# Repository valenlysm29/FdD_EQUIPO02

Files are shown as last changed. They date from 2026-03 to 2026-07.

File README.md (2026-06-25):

# Equipo 02 - Fundamentos de Diseño
### Carrera de Ingeniería Ambiental / Informática / Industrial  
**Universidad Peruana Cayetano Heredia**

---

## 🌍 Descripción del Equipo  
<p align="justify">
Somos el <strong>Equipo 02</strong> del curso <strong>Fundamentos de Diseño 2026-1</strong>, conformado por estudiantes de la carrera de Ingeniería Ambiental / Informática / Industrial.  
Nuestro objetivo es aplicar la metodología de diseño para generar soluciones innovadoras con impacto social, tecnológico y ambiental.
</p>

---

## 🎯 Introducción
<p align="justify">
La ciudad de Lima, particularmente en distritos como Villa María del Triunfo, presenta una marcada desigualdad en el acceso a recursos básicos, siendo el agua potable uno de los más críticos. En las zonas altas y asentamientos humanos, el abastecimiento es irregular, costoso y, en muchos casos, dependiente de camiones cisterna, lo que limita el desarrollo y la calidad de vida de la población.
</p>

<p align="justify">
Paradójicamente, Lima posee una alta humedad ambiental, especialmente durante temporadas de garúa y neblina, recurso que no es aprovechado de manera eficiente. A ello se suma un segundo problema relevante: la contaminación del aire, producto del crecimiento urbano, el tránsito vehicular y la presencia de polvo en zonas no pavimentadas.
</p>

<p align="justify">
En este contexto, el presente proyecto propone el diseño de un sistema inteligente de captación de niebla con monitoreo de calidad del aire, que permita no solo generar una fuente alternativa de agua, sino también evaluar las condiciones ambientales del entorno. Esta propuesta integra principios de ingeniería, sostenibilidad y tecnología, orientándose a soluciones adaptadas a la realidad local.
</p>

---

## ⚠️ Problemática

<p align="justify">
En las zonas altas de Villa María del Triunfo y otros sectores periurbanos de Lima se identifican dos problemáticas principales:
</p>

### 1. Escasez de agua  
- Más de un millón de personas en Lima no cuentan con acceso adecuado al agua potable.  
- Existe dependencia de camiones cisterna, lo que implica **altos costos y baja continuidad del servicio**.  
- Se generan limitaciones en actividades básicas como higiene, riego y consumo.  

### 2. Contaminación del aire  
- Presencia de material particulado (PM2.5 y PM10), especialmente en zonas con alta exposición al polvo.  
- Emisión de gases contaminantes debido al tránsito vehicular y actividades urbanas.  
- Impacto directo en la salud, principalmente enfermedades respiratorias.  

### 🔍 Problema integrador  

<p align="justify">
A pesar de la abundante humedad ambiental presente en forma de neblina o garúa, no existen sistemas accesibles que permitan aprovechar este recurso como fuente alternativa de agua y, simultáneamente, evaluar la calidad del aire del que proviene.
</p>

<p align="justify">
Esto genera una doble brecha:
</p>

- Se desperdicia un recurso natural disponible (neblina).  
- No se cuenta con información clara sobre la calidad del aire en zonas vulnerables.  

---

## 💡 Presentación de la solución  

<p align="justify">
El presente proyecto propone el desarrollo de un <strong>sistema inteligente de captación de niebla con monitoreo de calidad del aire</strong>, diseñado para zonas vulnerables de Lima, como Villa María del Triunfo, donde existe limitada disponibilidad de agua potable y altos niveles de contaminación ambiental.
</p>

<p align="justify">
La solución se basa en el aprovechamiento de la humedad atmosférica en forma de neblina o garúa, la cual es transformada en agua mediante un sistema de captación física. A diferencia de los sistemas tradicionales de atrapanieblas, esta propuesta incorpora un componente tecnológico que permite evaluar la calidad del aire y la calidad del agua, generando información ambiental relevante.
</p>

<p align="justify">
El sistema está compuesto por tres módulos principales:
</p>

### 🔹 Módulo 1: Captación de niebla  
- Uso de una malla especializada donde las microgotas se adhieren.  
- Coalescencia de gotas hasta alcanzar un tamaño suficiente.  
- Descenso por gravedad hacia una canaleta.  
- Almacenamiento en un depósito.  

### 🔹 Módulo 2: Monitoreo ambiental  
- Integración de sensores (ej. MQ-135 o PM2.5).  
- Detección de gases y partículas contaminantes.  
- Visualización del nivel de calidad del aire mediante LED o pantalla.  

### 🔹 Módulo 3: Registro y análisis  
- Medición del volumen de agua recolectada.  
- Registro del tiempo de captación.  
- Relación entre condiciones ambientales y rendimiento del sistema.  

<p align="justify">
Desde el enfoque de ingeniería, la solución integra principios de <strong>transferencia de masa (condensación)</strong>, diseño estructural optimizado (ángulo e inclinación de la malla) y sistemas electrónicos basados en sensores y microcontroladores. Esto permite no solo la captación eficiente del recurso hídrico, sino también la generación de datos para análisis y toma de decisiones.
</p>

<p align="justify">
El valor diferencial del proyecto radica en su enfoque integral: no solo busca generar una fuente alternativa de agua, sino también garantizar que dicha agua provenga de un entorno ambiental evaluado, incorporando un criterio de calidad que no está presente en sistemas convencionales.
</p>

<p align="justify">
En términos de impacto, esta solución representa una alternativa sostenible, de bajo costo y replicable, que puede ser implementada en comunidades con condiciones similares, contribuyendo simultáneamente a la <strong>seguridad hídrica</strong> y al <strong>monitoreo ambiental urbano</strong>.
</p>

---

## 🎯 Objetivos de Desarrollo Sostenible (ODS)

- 🚰 **ODS 6: Agua limpia y saneamiento**  
  Busca garantizar la disponibilidad y gestión sostenible del agua, promoviendo no solo el acceso al agua potable, sino también su uso eficiente en actividades productivas como la agricultura. Este objetivo es fundamental, ya que el sector agrícola consume aproximadamente el 70% del agua dulce a nivel mundial, lo que hace necesario implementar sistemas de riego más eficientes y sostenibles . En el Perú, aún existen importantes brechas en el acceso y gestión del agua: solo el 49,4% de la población cuenta con agua potable gestionada de forma segura , lo que evidencia la urgencia de optimizar el uso del recurso hídrico, especialmente en contextos de escasez.
  
  En distritos como Villa María del Triunfo, donde muchas familias dependen de camiones cisterna y enfrentan altos costos por el agua, resulta poco sostenible utilizar agua potable para el riego agrícola. En este contexto, nuestro proyecto se alinea directamente con el ODS 6 al proponer un sistema de riego agrícola basado en una fuente alternativa de agua, lo que permite reducir la presión sobre el agua potable, mejorar la eficiencia en su uso y promover prácticas sostenibles. De esta manera, se contribuye no solo a la conservación del recurso hídrico, sino también al desarrollo de la agricultura urbana y a la mejora de la calidad de vida en comunidades vulnerables.

---

- ❤️ **ODS 3: Salud y bienestar** 

  Monitoreo de la calidad del aire (Meta 3.9). El proyecto no solo proporciona agua, sino que también mide el entorno. Al integrar sensores de calidad del aire, se obtendrán datos críticos para prevenir enfermedades respiratorias. El ODS 3 busca reducir sustancialmente el número de muertes y enfermedades producidas por aire contaminado. El sistema actúa como una estación de alerta temprana para la salud comunitaria. Villa María del Triunfo es uno de los distritos con mayor humedad y, a menudo, con altos índices de contaminación por su cercanía a zonas industriales y tráfico. La niebla puede concentrar contaminantes; por ello, medir el aire mientras se captura el agua es vital.  

  Reducción de la carga de estrés y salud mental.En pleno 2026, la escasez hídrica en el Cono Sur de Lima obliga a más de 3,000 familias en VMT a depender de camiones cisterna con costos excesivos y frecuencias mínimas. La salud, entendida como un estado de bienestar integral, se ve afectada por la carga física y mental de gestionar el agua. Al automatizar la recolección para áreas verdes y huertos, se reduce el agotamiento físico (especialmente en mujeres y niños) y el estrés económico. La autonomía sobre el recurso hídrico y la creación de espacios verdes saludables transforman el entorno social, promoviendo una mejor salud mental y cohesión comunitaria.
---

- 🏗️ **ODS 9: Industria, innovación e infraestructura**  
  Este objetivo promueve el desarrollo de infraestructura resiliente, la industrialización sostenible y el fomento de la innovación. En muchas zonas vulnerables de Lima, la infraestructura para el acceso al agua es limitada o inexistente, lo que genera dependencia de sistemas informales como los camiones cisterna.  

  Frente a esta situación, el proyecto propone una solución innovadora que integra diseño estructural, sensores y análisis de datos. El sistema combina un mecanismo físico de captación de niebla con tecnologías como microcontroladores y monitoreo en tiempo real, permitiendo no solo recolectar agua, sino también optimizar su funcionamiento mediante el análisis de variables ambientales.  

  De esta manera, se desarrolla una propuesta tecnológica orientada a la innovación y al desarrollo de soluciones funcionales para problemáticas reales, promoviendo infraestructura alternativa sostenible, accesible y replicable en otras zonas con condiciones similares.

---

- 🏙️ **ODS 11: Ciudades y comunidades sostenibles**  
  Busca mejorar las ciudades frente al rápido crecimiento urbano. Actualmente, más de la mitad de la población vive en zonas urbanas y se proyecta que esta cifra alcanzará el 70 % para el año 2050, lo que generará problemáticas como la contaminación del aire, la expansión desordenada y el acceso limitado a servicios básicos. Además, cerca de 1100 millones de personas viven en condiciones precarias, y muchas ciudades continúan creciendo más rápido en territorio que en población, provocando un uso ineficiente del suelo. Ante este panorama, el ODS 11 propone construir ciudades más sostenibles, resilientes, seguras e inclusivas.  

  En este contexto, como equipo se desarrollará el proyecto “Sistema inteligente de captación de niebla con monitoreo de calidad del aire para Lima”, el cual buscará responder a problemáticas reales de la ciudad. Por un lado, se propondrá captar agua a partir de la humedad ambiental, con el objetivo de contribuir al acceso a un recurso básico en zonas vulnerables. Por otro lado, se incorporarán sensores que permitirán monitorear la calidad del aire, facilitando la identificación de niveles de contaminación. De esta manera, el proyecto integrará sostenibilidad, uso eficiente de recursos e innovación tecnológica, con la finalidad de aportar a la mejora de la calidad de vida en entornos urbanos y fortalecer el desarrollo de ciudades más sostenibles.

---

- 🌱 **ODS 13: Acción por el clima**  
  Hemos escogido este ODS porque nuestro proyecto busca responder a problemas relacionados con el cambio climático en Lima, especialmente en zonas como Villa María del Triunfo, donde hay presencia de neblina, alta humedad y contaminación del aire.  

  En las zonas de lomas de Villa María del Triunfo existe alta humedad debido a la neblina, pero este recurso no es aprovechado, a pesar de la escasez de agua en sectores cercanos. Además, la contaminación del aire en Lima afecta el ambiente y la salud, siendo un problema relacionado con el cambio climático. Según datos estadísticos de SENAMHI, en Lima se registran contaminantes como PM2.5 y PM10 en niveles que pueden ser perjudiciales para la salud. Asimismo, la humedad relativa puede alcanzar entre 70% y 90%, lo que evidencia el potencial de captar agua de la niebla.

---

## 📸 Fotografía del prototipo
<p align="center">
  
  <br>
  <em>Figura 1. Representación del prototipo propuesto</em>
</p>

---

## 📚 Referencias

- Organización Mundial de la Salud (OMS). (2021). *Air Quality Guidelines*.  
  https://www.who.int/publications/i/item/9789240034228  

- Organización Mundial de la Salud (OMS). (2021). *What are the WHO Air Quality Guidelines*.  
  https://www.who.int/news-room/feature-stories/detail/what-are-the-who-air-quality-guidelines  

- United Nations. (2023). *The Sustainable Development Goals Report 2023*.  
  https://unstats.un.org/sdgs/report/2023/  

- United Nations. (2023). *Informe de los Objetivos de Desarrollo Sostenible*.  
  https://unstats-un-org.translate.goog/sdgs/report/2023/_x_tr_sl=en&_x_tr_tl=es&_x_tr_hl=es&_x_tr_pto=tc  

- Naciones Unidas Perú. (s.f.). *Objetivo de Desarrollo Sostenible 6: Agua limpia y saneamiento*.  
  https://peru.un.org/es/sdgs/6  

- United Nations Environment Programme (UNEP). (2019). *Air Pollution Report*.  
  https://unhabitat.org/world-cities-report-2020-the-value-of-sustainable-urbanization  

- World Bank. (2020). *Sustainable Cities Report*.  
  https://www.unep.org/resources/assessment/air-pollution-asia-and-pacific-science-based-solutions  

- UNICEF. (s.f.). *Día Mundial del Agua: 1.000 niños mueren cada día por falta de agua potable*.  
  https://www.unicef.es/noticia/dia-mundial-del-agua-1000-ninos-mueren-cada-dia-por-falta-de-agua-potable  

- Servicio Nacional de Meteorología e Hidrología del Perú (SENAMHI). (2022). *Calidad del aire en Lima Metropolitana*.  
  https://www.senamhi.gob.pe  

- Servicio Nacional de Meteorología e Hidrología del Perú (SENAMHI). (2025). *Reporte de condiciones climáticas y calidad del aire en Lima*.  
  https://www.senamhi.gob.pe  

- Superintendencia Nacional de Servicios de Saneamiento (SUNASS). (2023). *Familias sin acceso al agua potable gastan más que hogares conectados*.  
  https://www.gob.pe/institucion/sunass/noticias/848884  

- Ministerio de Vivienda, Construcción y Saneamiento. (2024). *Proyectos de agua y saneamiento en Villa María del Triunfo*.  
  https://www.gob.pe/vivienda  

- FogQuest. (2020). *Fog Collection Projects*.  
  https://www.fogquest.org  

- MIT News. (2013). *Fog harvesting system inspired by nature*.  
  https://news.mit.edu/2013/efficient-fog-harvesting-0423  

- UCSS. (s.f.). *Contaminación del aire en Villa María del Triunfo*.  
  https://es.scribd.com/document/495390114/informe-villa-maria-docx  

- Congreso de la República del Perú. (2012). *Informe técnico: Captación de agua de las nieblas: Una alternativa para el desarrollo de las zonas áridas*. Centros de Documentación y Biblioteca.  
  https://www2.congreso.gob.pe/sicr/cendocbib/con4_uibd.nsf/B0F868A4B8BAE93705257CBC004FA71A/$FILE/1_INFORME_TECNICO_FINAL.pdf
 
  ---

## 📸 Fotografía del Equipo  
<p align="center">
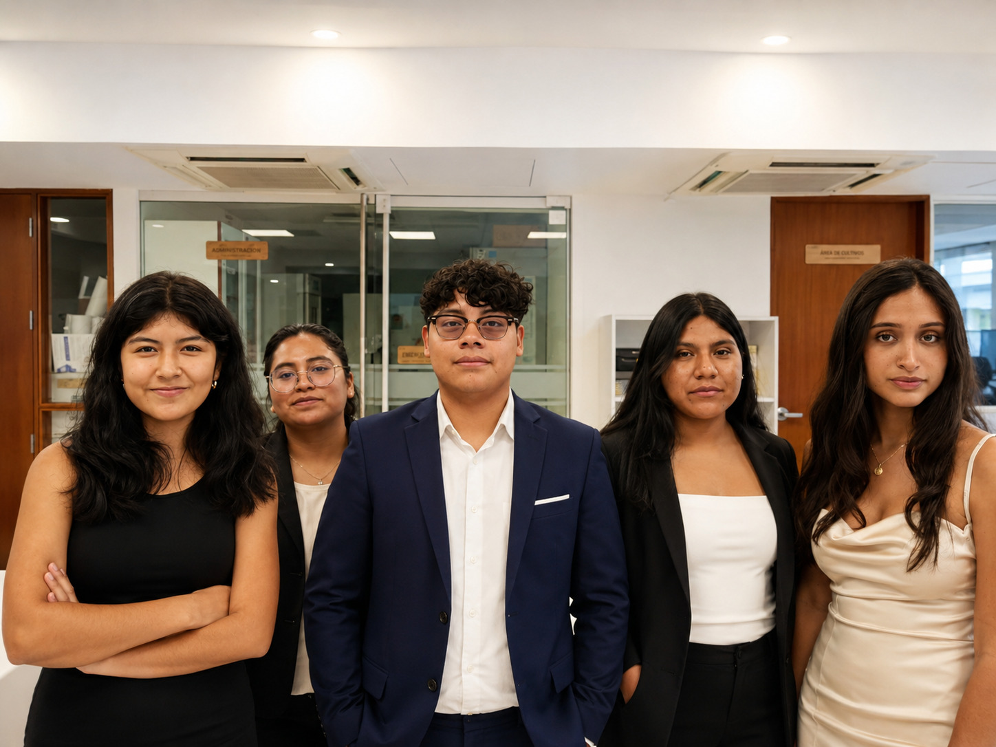
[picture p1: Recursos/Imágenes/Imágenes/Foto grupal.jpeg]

<br>
<em>Figura 2. Fotografía del equipo 02</em>
</p>

---

## 👥 Integrantes del Equipo  

| 📸 Foto | 👤 Nombre | 🎓 Rol | 💡 Intereses | 📧 Correo |
|:---:|:---|:---:|:---|:---|
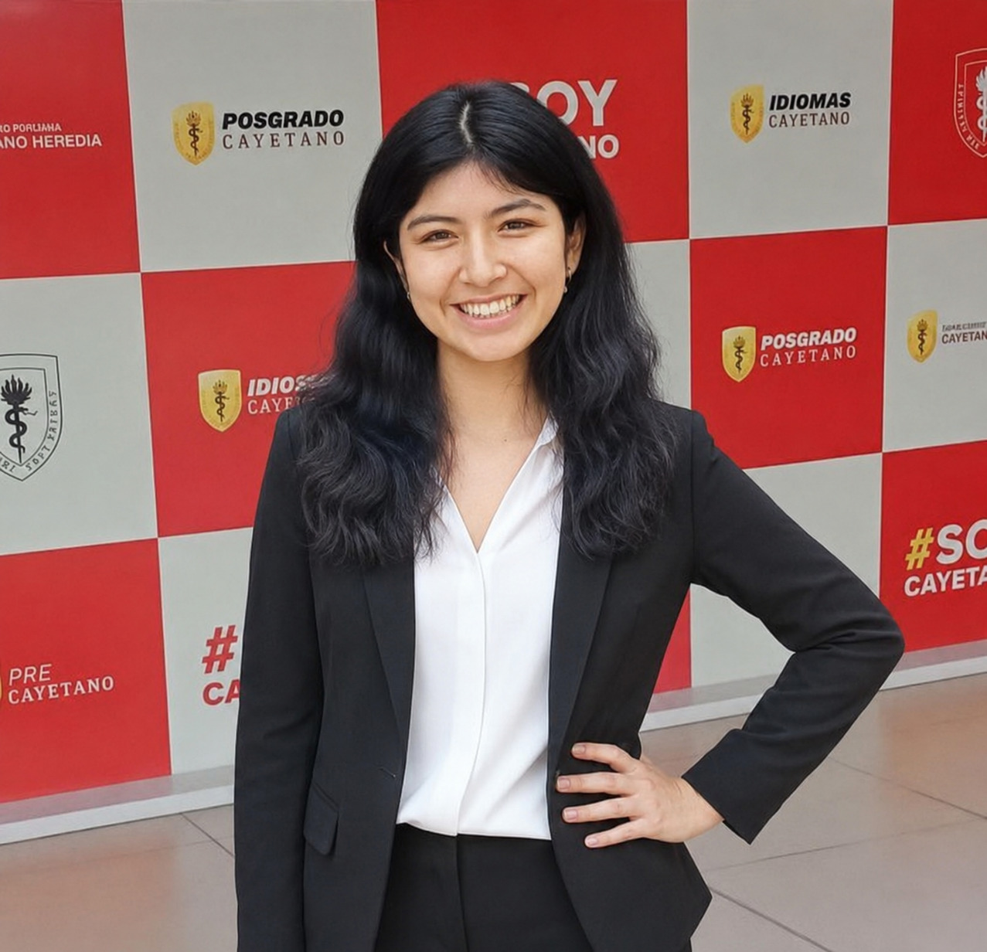
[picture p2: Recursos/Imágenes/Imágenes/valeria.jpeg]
|  | **Rodriguez Zavaleta, Valeria Nicole** | 👑 Líder del equipo | 🌱 Innovación social, 💡 liderazgo, ♻️ sostenibilidad | 📩 [valeria.rodriguez@upch.pe](mailto:valeria.rodriguez@upch.pe) |
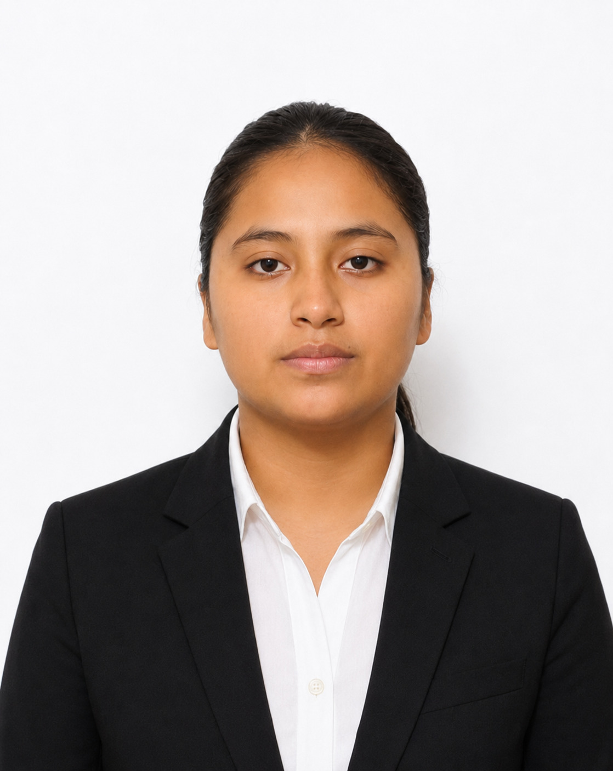
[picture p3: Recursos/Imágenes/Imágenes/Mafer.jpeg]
|  | **Perez Salvatierra, María Fernanda** | 🔬 Investigación | 🌍 Gestión ambiental, 🌱 desarrollo sostenible, 📊 impacto ambiental | 📩 [maria.perez.salvatierra@upch.pe](mailto:maria.perez.salvatierra@upch.pe) |
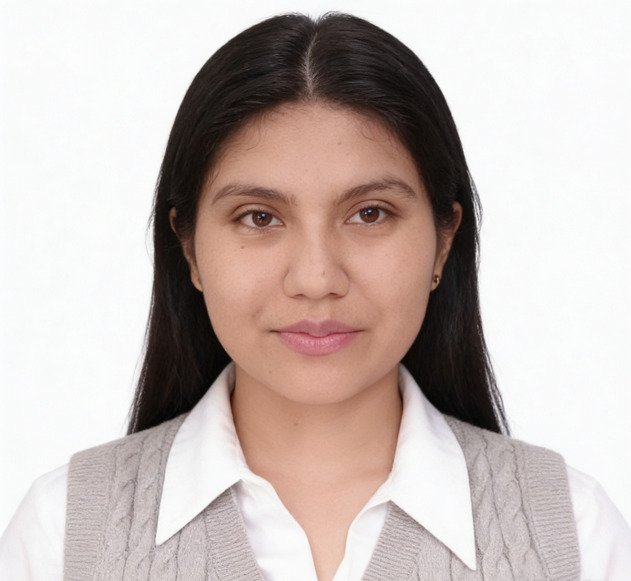
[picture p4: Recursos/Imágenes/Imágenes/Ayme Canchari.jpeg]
|  | **Canchari de la Cruz, Ayme** | 🎨 Diseño | 🧩 prototipos, ✨ innovación, 🎯 creatividad aplicada | 📩 [ayme.canchari@upch.pe](mailto:ayme.canchari@upch.pe) |
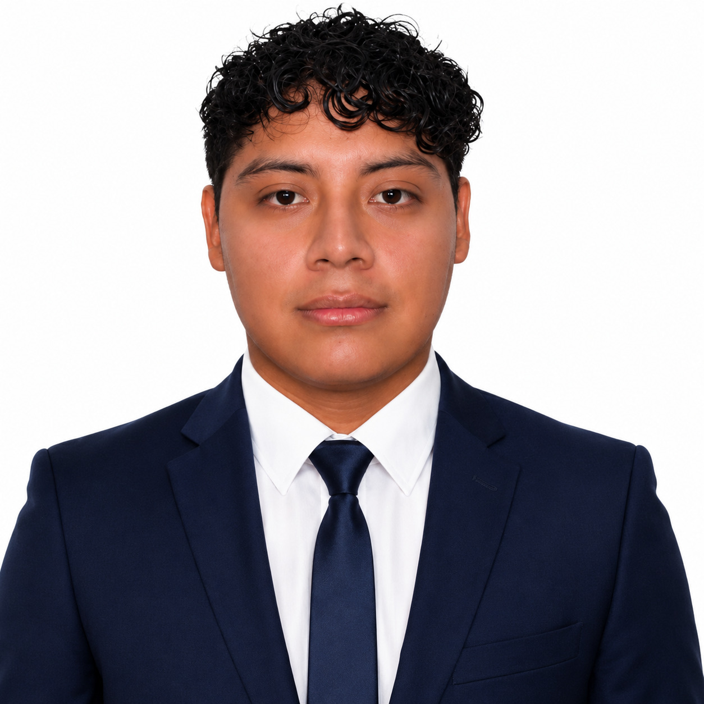
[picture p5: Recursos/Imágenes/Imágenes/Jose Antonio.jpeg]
|  | **Mamani Tello, Jose Antonio** | 📝 Documentación | 📄 procesos, 📈 mejora continua, ✍️ redacción técnica | 📩 [jose.mamani.t@upch.pe](mailto:jose.mamani.t@upch.pe) |
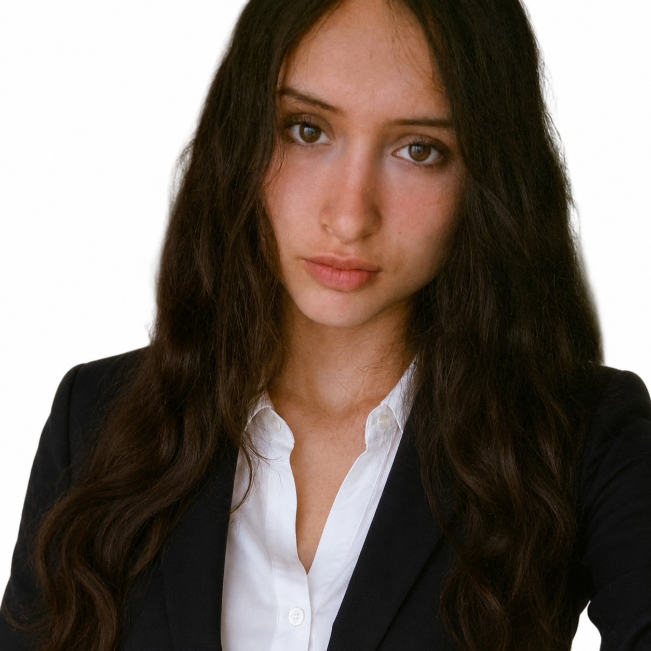
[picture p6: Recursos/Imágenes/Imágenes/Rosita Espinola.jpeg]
|  | **Espinola Abanto, Rosita Dayana** | 💻 Programación | 👩‍💻 programación, 📊 datos, 🧠 simulación y sistemas robóticos | 📩 [rosita.espinola@upch.pe](mailto:rosita.espinola@upch.pe) |

---

## 📌 Resumen Final  
<p align="justify">
El presente README describe la conformación del equipo, la problemática abordada y la propuesta de solución desarrollada en el marco del curso Fundamentos de Diseño. El proyecto propone un sistema inteligente que capta agua de la neblina mediante una malla atrapanieblas y, simultáneamente, monitorea la calidad del aire mediante sensores ambientales. Esta solución, aplicada en zonas como Villa María del Triunfo, permite aprovechar la humedad del ambiente como fuente alternativa de agua y evaluar las condiciones del aire del que proviene, integrando sostenibilidad, tecnología e innovación en un solo sistema.
</p>

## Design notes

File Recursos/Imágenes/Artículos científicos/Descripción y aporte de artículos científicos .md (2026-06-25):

 # Artículo Científico de Apoyo 1

## Nombre del Artículo

Water Harvesting Through Fog Collectors: A Review of Conceptual, Experimental and Operational Aspects

## Descripción

Este artículo presenta una revisión del estado del arte sobre los sistemas de captación de agua mediante atrapanieblas, enfocándose en su uso como alternativa frente a la escasez hídrica en zonas áridas y comunidades aisladas. Analiza la clasificación de los sistemas en conceptuales, experimentales y operacionales, así como su evolución, funcionamiento y aplicaciones en distintos contextos.

Además, estudia los principales factores que influyen en la eficiencia de captación, como el clima, los materiales utilizados y el diseño estructural, junto con desafíos asociados al mantenimiento y la implementación social de estas tecnologías.

## Aporte al Proyecto

Este artículo aporta una base teórica sólida sobre el funcionamiento de los atrapanieblas y los factores que afectan su eficiencia. Asimismo, permite identificar oportunidades de mejora mediante la incorporación de tecnologías IoT para el monitoreo en tiempo real de variables ambientales y de la calidad del agua, fortaleciendo la propuesta del proyecto.

---

# Artículo Científico de Apoyo 2

## Nombre del Artículo

Eficiencia de captación de agua con tres tipos de malla atrapanieblas en zonas rurales altoandinas de la sierra norte del Perú

## Descripción

Este artículo presenta un estudio experimental que evalúa la eficiencia de captación de agua mediante tres tipos de mallas atrapanieblas en zonas rurales altoandinas del norte del Perú. La investigación compara el desempeño de cada material bajo condiciones ambientales similares, considerando variables como humedad relativa, velocidad del viento y densidad de la niebla.

Los resultados evidencian diferencias significativas en la cantidad de agua recolectada, lo que permite determinar los materiales más eficientes para la captación en este tipo de entornos.

## Aporte al Proyecto

Este estudio proporciona evidencia experimental sobre la influencia del tipo de malla en el rendimiento de los sistemas atrapanieblas. Además, contribuye a la selección de materiales más eficientes y respalda la propuesta de integrar sensores para analizar en tiempo real la relación entre las condiciones ambientales y la eficiencia del sistema.

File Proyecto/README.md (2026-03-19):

# Proyecto

En esta carpeta deben estar todos los archivos necesarios para poder replicar el proyecto:

- Código fuente del sistema (Módulo Software)
- Archivos de diseño 3D para la fabricación de piezas (Módulo Mecánico)
- Esquemas electrónicos (Módulo Electrónico)

Cada módulo contiene su propia documentación y recursos específicos para facilitar la implementación y el montaje del proyecto.

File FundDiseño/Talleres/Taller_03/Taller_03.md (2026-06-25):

# 1. INTRODUCCIÓN

El acceso al agua constituye uno de los principales desafíos a nivel global, especialmente en un contexto marcado por el cambio climático y el crecimiento urbano acelerado, factores que comprometen la disponibilidad y la gestión sostenible de los recursos hídricos (1). En el Perú, esta problemática es particularmente crítica, ya que solo el 49,4% de la población cuenta con acceso a agua potable gestionada de forma segura, lo que evidencia importantes brechas estructurales en la cobertura y calidad del servicio (2).

En Lima Metropolitana, y de manera más acentuada en distritos como Villa María del Triunfo, la situación se agrava debido a la expansión urbana desordenada y a la limitada infraestructura de saneamiento. En estas zonas, una parte significativa de la población depende del abastecimiento mediante camiones cisterna, lo cual incrementa el costo del recurso y restringe su disponibilidad para actividades domésticas y productivas. Paradójicamente, estas áreas presentan altos niveles de humedad relativa (entre 70% y 90%), acompañados de fenómenos persistentes de neblina o garúa característicos de las lomas costeras (2).

A pesar de este potencial hídrico atmosférico, la niebla no es aprovechada de manera sistemática como fuente alternativa de agua. Esta situación se ve agravada por la contaminación del aire, caracterizada por la presencia de material particulado fino (PM2.5 y PM10), emisiones vehiculares y polvo en suspensión, lo que no solo afecta la salud de la población, sino también la calidad del agua captada de la atmósfera (3).

En este contexto, diversas investigaciones han demostrado que la captación de agua de niebla mediante sistemas atrapanieblas constituye una alternativa viable en zonas áridas y semiáridas, permitiendo recolectar microgotas suspendidas en la atmósfera para su uso en actividades como el riego agrícola (4–7). Asimismo, el desarrollo tecnológico en este campo ha sido impulsado por estudios y patentes que optimizan la eficiencia de captación mediante el uso de materiales especializados (8). Sin embargo, en el contexto local, estas soluciones suelen carecer de sistemas de monitoreo ambiental y de adaptaciones específicas frente a condiciones de contaminación urbana.

En ese sentido, se identifica una brecha tecnológica en la integración de sistemas de captación de agua de niebla con herramientas inteligentes de monitoreo ambiental que permitan garantizar un uso eficiente, seguro y sostenible del recurso. Estudios realizados en las lomas de Villa María del Triunfo evidencian que el agua captada no es apta para consumo humano directo, pero sí resulta adecuada para riego y mantenimiento de áreas verdes, lo que orienta su aprovechamiento hacia usos no potables (7).

Frente a esta problemática, el presente proyecto propone el diseño de un sistema inteligente de captación de agua de niebla, complementado con sensores para el monitoreo de la calidad del aire y variables ambientales como temperatura y humedad relativa. Para ello, se plantea el uso del sensor BME280, el cual permite medir con alta precisión la temperatura, humedad relativa y presión atmosférica, variables clave para identificar condiciones óptimas de formación de niebla. En cuanto al monitoreo de la calidad del aire, se empleará el sensor MQ-135, seleccionado como una alternativa representativa y de bajo costo frente a sensores más avanzados como el PMS5003, permitiendo detectar gases contaminantes relevantes en entornos urbanos. Asimismo, el sistema incorporará un sensor de pH para evaluar la calidad del agua captada y determinar su idoneidad para riego, así como un sensor de nivel de agua (tipo flotador o ultrasónico) para gestionar el almacenamiento del recurso recolectado. Para la automatización del riego, se utilizará un sensor de humedad de suelo, el cual permitirá optimizar el uso del agua en función de las necesidades reales del terreno. Todos estos dispositivos estarán integrados mediante un microcontrolador ESP32, el cual posibilita la interconexión de sensores y la transmisión de datos en tiempo real, facilitando la implementación de un sistema basado en Internet de las Cosas (IoT) orientado a la gestión eficiente del recurso hídrico.

Finalmente, la propuesta se alinea con los Objetivos de Desarrollo Sostenible (ODS), particularmente con el ODS 6 (agua limpia y saneamiento), al promover el uso de fuentes hídricas alternativas; el ODS 9 (industria, innovación e infraestructura), mediante la aplicación tecnológica; el ODS 11 (ciudades y comunidades sostenibles), al mejorar las condiciones ambientales urbanas (9); y el ODS 13 (acción por el clima), al plantear estrategias de adaptación basadas en el aprovechamiento de recursos atmosféricos. De este modo, el proyecto se configura como una solución sostenible, accesible y replicable frente a problemáticas ambientales críticas (10).

---

# BIBLIOGRAFÍA

1. Ministerio del Ambiente del Perú. Evaluación de necesidades tecnológicas para el cambio climático en el Perú [Informe técnico]. Lima: Ministerio del Ambiente; 2014.

2. Instituto Nacional de Estadística e Informática. Perú: Formas de acceso al agua y saneamiento básico - Nro 10 [Internet]. [citado el 8 de abril de 2026]. Disponible en: https://www.gob.pe/institucion/inei/informes-publicaciones/4985657-peru-formas-de-acceso-al-agua-y-saneamiento-basico-nro-10

3. Organización Mundial de la Salud. Publicaciones sobre calidad del aire [Internet]. [citado el 8 de abril de 2026]. Disponible en: https://www.who.int/publications

4. Miñan Peña MM. Estudio para la obtención y aprovechamiento de agua para uso agrícola por medio de captadores de neblina en la comunidad campesina de Samanga, Ayabaca – Piura [Tesis de pregrado]. Universidad Alas Peruanas; 2017.

5. Toledo Huayaney EI. Gestión de nieblas como recurso hídrico para proteger el ecosistema de lomas en zonas áridas del distrito de Villa María del Triunfo en el año 2015 [Tesis de maestría] [Internet]. Universidad Nacional Hermilio Valdizán; 2017. Disponible en: https://repositorio.unheval.edu.pe/backend/api/core/bitstreams/a02e9b67-677e-4612-81b4-57812e1e571f/content

6. Albornoz Figueroa F, Torres Rojas G. Determinación del potencial de captación de agua de atrapanieblas como fuente alternativa de recursos hídricos para desarrollo agrícola en un ecosistema con características árido-desérticas en la región de Arica y Parinacota [Tesis de pregrado]. Universidad de Tarapacá; 2020.

7. García Huazo FN. Estudio de la variación temporal y espacial de la calidad del agua de niebla en Las Lomas de Villa María [Internet]. 2017 [citado el 8 de abril de 2026]. Disponible en: https://hdl.handle.net/20.500.12996/3198

8. CN116988543. Agricultural irrigation fog water collector [Internet]. [citado el 2 de abril de 2026]. Disponible en: https://patentscope.wipo.int/search/en/detail.jsf?docId=CN414524443

9. Gómez Cano CA, Pérez Gamboa AJ, Sánchez Castillo V. Análisis de la producción científica en torno al ODS 11: Ciudades y Comunidades Sostenibles. Mundo Fesc. 2024;14(28):117–135. doi:10.61799/2216-0388.1585

10. Organización de las Naciones Unidas. 17 Objetivos de Desarrollo Sostenible [Internet]. [citado el 8 de abril de 2026]. Disponible en: https://www.ods.cr/es/17-objetivos-de-desarrollo-sostenible/

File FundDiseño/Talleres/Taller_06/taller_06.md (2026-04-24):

## MATRIZ DE DESK RESEARCH

**Proyecto:** YAKUYURA - Sistema de captación de niebla para riego con monitoreo de calidad de agua  
**Ubicación:** Villa María del Triunfo, Lima – Perú  

**Problematica:**  
¿Cómo diseñar un sistema de captación de niebla eficiente, de bajo costo y adaptable a las condiciones climáticas de Villa María del Triunfo, que permita obtener agua con calidad adecuada para riego, mediante el monitoreo de parámetros físico-químicos (pH, conductividad y turbidez), considerando la influencia de las condiciones ambientales?

**Acceso a la matriz en Google Sheets:**  
🔗 [Consultar matriz de Desk Research](https://docs.google.com/spreadsheets/d/1Mp-pc_4aNizmCjHv-cpVC83qQYfwDnMo/edit)

---

| N° | Fuente | Autor/Institución | Año | Referencia | Estado de tecnología encontrada | Exigencia o requisito identificado | Restricción o limitación | Función principal | Aplicación al proyecto |
|----|---|---|-----|---|---|---|---|---|---|
| 1 | DS N°004-2017-MINAM | Ministerio del Ambiente (MINAM) | 2017 | https://www.minam.gob.pe/wp-content/uploads/2017/06/DS-004-2017-MINAM.pdf | Normativa nacional que establece límites de calidad para agua de riego (Categoría 3, D1) | pH: 6.5–8.5; Conductividad: 2500–5000 µS/cm; control de calidad física (relacionada a turbidez) | No incluye turbidez como parámetro directo; algunos parámetros requieren interpretación | Establecer límites de calidad para uso seguro del agua en riego | Define rangos operativos para sensores de pH y conductividad; orienta la evaluación del agua captada |
| 2 | ISO 7027-1, ISO 10523, ISO 7888 | International Organization for Standardization (ISO) | 2008–2016 | ISO 7027-1: https://www.iso.org/obp/ui/#iso:std:iso:7027:-1:ed-1:v1:en <br> ISO 10523: https://www.iso.org/obp/ui/#iso:std:iso:10523:ed-2:v1:en <br> ISO 7888: https://www.iso.org/obp/ui/#iso:std:iso:7888:ed-1:v1:en | Métodos estandarizados para medición de turbidez, pH y conductividad | Uso de sensores calibrados y medición bajo condiciones controladas | No establecen valores límite de calidad | Estandarizar la medición de parámetros físico-químicos | Permite validar y calibrar sensores implementados en el sistema atrapanieblas |
| 3 | Calidad del aire y salud | Organización Mundial de la Salud (OMS) | 2023 | https://www.who.int/es/news-room/fact-sheets/detail/ambient-(outdoor)-air-quality-and-health | Información sobre contaminantes atmosféricos (PM, gases) que afectan el entorno | Identificación de contaminantes que pueden influir indirectamente en la calidad del agua | No aborda directamente calidad de agua ni riego | Analizar el impacto del aire en el ambiente | Justifica que la calidad del aire influye en pH, conductividad y turbidez del agua de niebla |
| 4 | Water Quality for Agriculture | FAO (Ayers & Westcot) | 1985 | https://www.fao.org/4/t0234e/t0234e00.htm | Referencia internacional para evaluación de agua en agricultura | Clasificación de salinidad mediante conductividad; control de sólidos en suspensión | No es normativa obligatoria; valores referenciales | Evaluar la aptitud del agua para riego agrícola | Complementa la normativa ECA e interpreta conductividad y turbidez del agua captada |

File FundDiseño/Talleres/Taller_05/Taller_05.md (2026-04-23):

## 🚀 Presentación del Proyecto

<p align="center">
  <a href="https://docs.google.com/document/d/1KE3PtH3lDLxYr63FYQYzETe2vs5omj35mvZSyd1JYwM/edit" target="_blank">
    
  </a>
  <a href="https://canva.link/n60l2mmut4ebm6i" target="_blank">
    
  </a>
</p>

<p align="center">
  Accede al documento técnico y a la presentación del proyecto YAKUYURA.
</p>

# 🚰 YAKUYURA: del aire a la vida

## 1. Historia

¿Sabías que en Lima, una ciudad con hasta 90% de humedad, más de un millón de personas tienen acceso limitado al agua?

Yo crecí viendo cómo, en distritos como Villa María del Triunfo, muchas familias dependen de camiones cisterna, pagando precios elevados por un recurso básico. Esta situación no solo afecta el consumo diario, sino también limita el desarrollo de actividades productivas como el riego y los huertos urbanos.

Como equipo de ingeniería, nos hicimos una pregunta clave:  
**¿Cómo es posible que falte agua, si vivimos rodeados de neblina todos los días?**

Fue ahí donde entendimos que el problema no es la falta de recursos, sino que no los estamos aprovechando.

---

## 2. Problema

A pesar de contar con condiciones ambientales favorables, el acceso al agua en el asentamiento humano Bellavista del Paraíso (Villa María del Triunfo) es limitado, incluso con la presencia de niebla costera (garúa).

- Consumo promedio en Lima: **134 L/persona/día** (≈ 536 L por familia)
- En la zona de estudio: **20 a 70 L/persona/día** (≈ 80 a 280 L por familia)
- Reducción de hasta **85%** (1,2)

Esto limita el uso del agua solo a:
- Cocina  
- Higiene  
- Limpieza  

Dejando de lado:
- Riego  
- Áreas verdes  

Además:
- No existen sistemas accesibles para aprovechar la niebla  
- El acceso es irregular y costoso  
- La calidad del aire genera dudas sobre el agua obtenida (3)

👉 **Problema central:**  
Existe un recurso disponible, pero no hay soluciones accesibles para captarlo ni herramientas que aseguren su calidad.

---

## 3. Solución

Proponemos **YAKUYURA**, un sistema que:

- Captura agua de la niebla mediante mallas
- Conduce el agua hacia un sistema de recolección
- La almacena para uso en riego

Además, incorpora sensores que miden:
- Humedad  
- Calidad del aire  
- Parámetros del agua  

Esto permite entender:
- En qué condiciones se obtiene el recurso  
- Para qué uso es adecuado  

---

## 4. Propuesta de valor

YAKUYURA no es un atrapanieblas tradicional, sino una solución integral que combina:

- Captación de agua  
- Monitoreo ambiental  
- Gestión del recurso  

Beneficios:
- Decisiones informadas sobre el uso del agua  
- Optimización del sistema  
- Reducción de riesgos por calidad ambiental  

✔ Enfoque realista:  
El agua está orientada a **riego y áreas verdes**, no consumo humano directo.

---

## 5. Modelo de negocio

YAKUYURA se plantea como una solución de implementación:

- Comunitaria  
- Institucional  

Dirigida a:
- Municipalidades  
- ONGs  
- Proyectos urbanos  

Basado en modelos reales:
- Peruanos Sin Agua  
- FogQuest  
- Aqualonis (4–6)

💡 Propuesta:
Servicio integral que incluye:
- Instalación  
- Mantenimiento  
- Monitoreo ambiental  

---

## 6. Estrategia

1. Piloto en Bellavista del Paraíso (VMT)
2. Evaluación del sistema en riego
3. Simulación en la universidad
4. Validación del impacto
5. Generación de alianzas

Objetivo:
- Escalar a otros asentamientos de Lima Sur

---

## 7. Tracción

Actualmente en fase de:

- Análisis del contexto  
- Definición del problema  
- Diseño conceptual  

✔ Próximo paso:
- Desarrollo y validación del prototipo en campo  

---

## 8. Equipo

Equipo multidisciplinario de estudiantes de:

- Ingeniería Ambiental  
- Ingeniería Informática  
- Ingeniería Industrial  

Capacidad:
- Enfoque técnico  
- Desarrollo de soluciones reales  
- Adaptación al contexto  

---

## 9. Pedido

Buscamos apoyo para:

- Desarrollo del prototipo  
- Validación en campo  
- Asesoría técnica  
- Espacios de prueba  
- Alianzas estratégicas  

🎯 Objetivo:
Demostrar que la niebla puede convertirse en una alternativa:

- Útil  
- Monitoreada  
- Sostenible  

---

## 📚 Referencias

1. Superintendencia Nacional de Servicios de Saneamiento (SUNASS).  
   Consumo promedio de agua potable en Lima es de 134 litros al día por persona [Internet]. 2024. Disponible en: https://www.gob.pe/institucion/sunass/noticias/1350994-consumo-promedio-de-agua-potable-en-lima-es-de-134-litros-al-dia-por-persona-con-tendencia-decreciente-de-13-l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  

2. Agencia Peruana de Noticias Andina.  
   Sedapal: consumo de agua por distritos [Internet]. 2024. Disponible en: https://andina.pe/agencia/noticia-sedapal-estos-distritos-se-consumen-mas-200-litros-agua-al-dia-persona-970596.aspx  

3. Cruz Gutiérrez A.  
   Captación de agua de niebla: fundamentos y aplicaciones [Internet]. Disponible en: https://riuma.uma.es/rest/api/core/bitstreams/604ac6e0-f6b0-4d73-89f6-1e0027e912ee/content  

4. Peruanos Sin Agua. Disponible en: https://lossinagua.org/  

5. FogQuest. Disponible en: https://www.fogquest.org/

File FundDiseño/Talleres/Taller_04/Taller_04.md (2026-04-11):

# 📚 Análisis de Patentes  
## Sistema Atrapanieblas

---

## 🔹 Patente 1

**📌 Título:**  
ATRAPANIEBLAS MULTIFUNCIONAL AUTOSUSTENTABLE PARA UN RIEGO UNIFORME  

**📄 Número:**  
001116-2024/DIN  

**📅 Año:**  
2025 

**🌐 Página de patente:**  
INDECOPI  

**🔗 Link:**  
https://servicio.indecopi.gob.pe/portalSAE/Expedientes/consultaOIN.jsp  

### 📝 Resumen
La presente invención se refiere a un atrapanieblas autosustentable diseñado para la reforestación mediante un sistema de riego uniforme y autónomo. El dispositivo está integrado por una hélice atrapaniebla (100) que captura la humedad ambiental, la cual es canalizada hacia un soporte (200) que cumple la doble función de estructura y tanque de almacenamiento. Desde este depósito, el recurso hídrico se distribuye a través de brazos laterales (204) que permiten un riego por goteo localizado directamente sobre el basamento vegetativo (300). Gracias a esta configuración, el sistema garantiza el aprovechamiento máximo del agua de niebla y una hidratación constante de las especies vegetales, facilitando la recuperación de ecosistemas en zonas de difícil acceso sin necesidad de fuentes de energía externas.

### 🔗 Relación con el proyecto
Se relaciona directamente con el proyecto en la integración de la captación de niebla y su uso en sistemas de riego, permitiendo aprovechar el agua atmosférica como recurso hídrico. Sin embargo, a diferencia de esta propuesta, el proyecto incorpora sensores para el monitoreo de la calidad del agua y del ambiente, así como un sistema de control inteligente basado en IoT, lo cual representa una mejora tecnológica.

### 🖼️ Imagen
<p align="center">
  
</p>

---

## 🔹 Patente 2

**📌 Título:**  
Method and system for fog harvesting and mist elimination  

**📄 Número:**  
WO2023230244A1  

**📅 Año de publicación:**  
2023  

**🌐 Página:**  
Espacenet  

**🔗 Link:**  
https://worldwide.espacenet.com/patent/search/family/088919907/publication/WO2023230244A1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  

### 📝 Resumen
La invención consiste en un dispositivo que recoge el agua contenida en la niebla y la canaliza hacia un punto de salida. El sistema cuenta con un eje central de forma alargada que actúa como columna vertebral del conjunto y como conductor del agua hacia abajo. A lo largo de este eje se distribuyen múltiples estructuras filiformes denominadas tricomas, cuya función es atrapar las microgotas suspendidas en la niebla al entrar en contacto con ellas. Los espacios que quedan entre tricoma y tricoma no son simples huecos, sino que actúan como canales capilares que absorben y fusionan las gotas individuales hasta formar hilos de agua continuos. Estos hilos fluyen a lo largo del eje central aprovechando la gravedad, recorren toda la longitud del dispositivo y convergen finalmente en una salida principal donde el agua ya puede ser recolectada o aprovechada. Método y sistema para la recolección de neblina y la eliminación de bruma. En síntesis, el sistema replica de forma artificial el mecanismo que utilizan ciertas plantas y superficies naturales para captar la humedad del aire, integrando la captación, el transporte capilar y la recolección en una sola estructura compacta.

### 🔗 Relación con el proyecto
Se relaciona directamente con el módulo de captación de niebla, ya que emplea principios similares de recolección de microgotas; sin embargo, no incorpora sistemas de monitoreo ambiental ni sensores, ni un sistema de filtración simple, lo cual representa una mejora propuesta en el presente proyecto.

### 🖼️ Imagen
<p align="center">
  
</p>

---

## 🔹 Patente 3

**📌 Título:**  
Cobweb-like mist-catching water drinking device  

**📄 Número:**  
CN110144994A  

**📅 Año:**  
2019  

**🌐 Página:**  
Espacenet  

**🔗 Link:**  
https://worldwide.espacenet.com/patent/search?q=pn%3DCN110144994A 

### 📝 Resumen
La patente describe un dispositivo de captación de niebla que utiliza una estructura tipo malla inspirada en una telaraña para atrapar microgotas presentes en el aire. Estas gotas son conducidas hacia un sistema de almacenamiento, donde el agua recolectada pasa por un proceso de purificación en varias etapas. En una primera fase, el sistema incorpora un proceso de filtración multicapa, utilizando materiales como grafeno poroso tridimensional y carbón activado, los cuales permiten retener partículas y eliminar impurezas mediante procesos de adsorción. Posteriormente, el agua es sometida a un tratamiento térmico, en el cual se activa un calentador eléctrico que eleva la temperatura hasta alcanzar el punto de ebullición, permitiendo la eliminación de microorganismos como bacterias y virus. Finalmente, el sistema cuenta con un mecanismo de control automático, mediante sensores que detectan el punto de ebullición, asegurando que el agua solo sea liberada cuando ha alcanzado condiciones adecuadas de seguridad.

### 🔗 Relación con el proyecto
Se relaciona con el proyecto en el uso de una estructura de malla para la captación de niebla y en la incorporación de procesos de mejora de la calidad del agua. Sin embargo, a diferencia de la patente, el sistema propuesto plantea un enfoque más simple basado en filtración física, sin incluir tratamiento térmico, debido a que el agua está destinada a riego y no a consumo humano. Asimismo, el proyecto incorpora sensores para el monitoreo ambiental, lo cual no está presente en la patente.

### 🖼️ Imagen
<p align="center">
  
</p>

---

## 🔹 Patente 4

**📌 Título:**  
Water quality monitoring and control system  

**📄 Número:**  
US11693434B2  

**📅 Año:**  
2023  

**🌐 Página:**  
Espacenet  

**🔗 Link:**  
https://worldwide.espacenet.com/patent/search?q=pn%3DUS11693434B2  

### 📝 Resumen
Se proporciona un sistema de monitoreo de la calidad del agua, que incluye varios sensores, varios actuadores y un sistema embebido. Los sensores detectan parámetros ambientales y generan por separado diversas señales de detección, incluyendo dichos parámetros. Los actuadores modifican los parámetros ambientales. El sistema embebido incluye un módulo de almacenamiento, un módulo de adquisición de datos, un módulo de análisis de datos y un módulo de control. El módulo de almacenamiento guarda varios rangos de parámetros normales que corresponden a los parámetros ambientales respectivos. El módulo de adquisición de datos está conectado a los sensores para recibir las señales de detección. El módulo de análisis de datos está conectado al módulo de almacenamiento y al módulo de adquisición de datos para determinar si las señales de detección son anormales según los rangos de parámetros normales y generar un resultado de determinación. El módulo de control está conectado al módulo de análisis de datos para controlar los actuadores o generar una señal de advertencia según el resultado de la determinación.

### 🔗 Relación con el proyecto
Se relaciona directamente con el proyecto en la incorporación de sensores para el monitoreo de parámetros del agua, así como en el uso de un sistema de control que permite analizar los datos en tiempo real. Al igual que la patente, el proyecto propone medir variables como el pH y condiciones ambientales para evaluar la calidad del agua. Sin embargo, a diferencia de ésta, el sistema propuesto integra la captación de agua de niebla como fuente alternativa y está orientado a su uso en un sistema de riego automatizado para la agricultura, por lo que el agua recolectada no está destinada al consumo humano, sino a usos no potables.

### 🖼️ Imágenes
<p align="center">
  
</p>

<p align="center">
  
</p>

---

## 🔹 Patente 5

**📌 Título:**  
DISPOSITIVO INTEGRADO PARA RIEGO INTELIGENTE BASADO EN IOT, ENERGÍA RENOVABLE Y CONTROL REMOTO  

**📄 Número:**  
002521-2025  

**📅 Año:**  
2025  

**🌐 Página:**  
INDECOPI  

**🔗 Link:**  
https://servicio.indecopi.gob.pe/portalSAE/Expedientes/consultaOIN.jsp  

### 📝 Resumen
El dispositivo integrado para riego inteligente basado en IoT y energía renovable proporciona una solución automatizada y eficiente para el riego agrícola. Combina sensores avanzados para monitorear variables ambientales, un sistema de energía solar para operar sin conexión a la red eléctrica, y control remoto mediante una plataforma como Telegram. Además, incorpora un sistema de monitoreo en tiempo real con cámaras para detectar problemas en las plantas y mejorar la seguridad del entorno.

### 🔗 Relación con el proyecto
Se relaciona con el proyecto en la implementación de un sistema de riego automatizado basado en sensores y control inteligente del agua. Al igual que la patente, el sistema propuesto busca optimizar el uso del recurso hídrico mediante tecnología. Sin embargo, a diferencia de esta, el proyecto incorpora la captación de agua de niebla como fuente alternativa, así como el monitoreo de la calidad del agua, lo cual no se contempla en la patente.

### 🖼️ Imagen
<p align="center">
  
</p>

---

## 🔹 Patente 6

**📌 Título:**  
DISPOSITIVO DE MONITOREO CONTINUO DE LA TEMPERATURA Y LA HUMEDAD DEL SUELO  

**📄 Número:**  
ES1259389U  

**📅 Año:**  
2021  

**🌐 Página:**  
Espacenet  

**🔗 Link:**  
https://worldwide.espacenet.com/patent/search?q=pn%3DES1259389U  

### 📝 Resumen
Dispositivo (para el monitoreo continuo de la humedad y la temperatura del suelo, diseñado para ser insertado en la interfaz aire-suelo de un terreno a monitorear, que comprende: - un soporte , - un módulo electrónico , conectado al soporte , que a su vez comprende: - un sensor de temperatura  y un sensor de humedad , que obtienen datos de temperatura y humedad de la interfaz aire-suelo, - un microcontrolador , conectado al sensor de temperatura  y al sensor de humedad, - una fuente de alimentación , conectada al microcontrolador , y - una unidad de almacenamiento , conectada al microcontrolador , para almacenar los datos obtenidos por los sensores.

### 🔗 Relación con el proyecto
Se relaciona con el proyecto en la implementación de un sistema de riego automatizado que permite optimizar el uso del agua. Al igual que la patente, el sistema propuesto busca mejorar la eficiencia del riego mediante el uso de tecnología. Sin embargo, el proyecto integra además la captación de agua de niebla como fuente alternativa y el monitoreo de la calidad del agua, lo cual no se contempla en la patente.

### 🖼️ Imagen
<p align="center">
  
</p>

---

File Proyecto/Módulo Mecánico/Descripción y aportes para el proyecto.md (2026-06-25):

# DESCRIPCIÓN Y APORTES 
## ONSHAPE

## Descripción

Este proyecto fue desarrollado utilizando la plataforma Onshape para el diseño y modelado de piezas mecánicas mediante técnicas de CAD paramétrico. Durante el desarrollo se realizaron diversos bocetos y operaciones de modelado para construir una solución funcional, optimizando dimensiones, restricciones geométricas y relaciones entre componentes.

El trabajo permitió aplicar conocimientos de diseño asistido por computadora, modelado 3D, ensamblajes y documentación técnica, fortaleciendo las competencias en ingeniería y manufactura digital.

## Objetivos

* Diseñar componentes mediante modelado paramétrico.
* Crear bocetos técnicos con restricciones geométricas.
* Construir modelos tridimensionales funcionales.
* Validar dimensiones y relaciones entre piezas.
* Generar documentación técnica del proyecto.

## Aportes al Proyecto

### Diseño de Bocetos

Se desarrollaron bocetos iniciales para definir la geometría base de las piezas, estableciendo dimensiones, restricciones y relaciones necesarias para garantizar la precisión del modelo.

### Modelado 3D

A partir de los bocetos se realizaron operaciones de extrusión, corte y modificación para construir los componentes tridimensionales del proyecto.

### Optimización del Diseño

Se ajustaron dimensiones y parámetros con el fin de mejorar la funcionalidad, estabilidad y facilidad de fabricación de las piezas diseñadas.

### Documentación Técnica

Se elaboró la documentación correspondiente para registrar el proceso de diseño, las decisiones tomadas y las características técnicas del modelo final.

## Bocetos Realizados

### Boceto 1

**Descripción:** Definición de la estructura principal.

**Aporte:**

* Establecimiento de dimensiones base.
* Aplicación de restricciones geométricas.
* Preparación para operaciones de modelado.

### Boceto 2

**Descripción:** Desarrollo de componentes complementarios.

**Aporte:**

* Mejora de la integración entre piezas.
* Optimización de la geometría funcional.
* Reducción de posibles interferencias.

### Boceto 3

**Descripción:** Ajustes finales del diseño.

**Aporte:**

* Corrección de tolerancias.
* Validación dimensional.
* Preparación para ensamblaje o fabricación.

## Herramientas Utilizadas

* Onshape
* Modelado Paramétrico
* Bocetos 2D
* Extrusiones y Cortes
* Ensamblajes CAD
* Exportación de Modelos 3D

## Certificados

## Resultados

* Diseño CAD completamente desarrollado.
* Modelos tridimensionales funcionales.
* Bocetos documentados y parametrizados.
* Validación de dimensiones y ensamblajes.
* Fortalecimiento de habilidades en diseño asistido por computadora.

## Conclusiones

El desarrollo del proyecto permitió aplicar metodologías de diseño CAD y modelado paramétrico para la creación de soluciones técnicas. Los bocetos constituyeron la base para la construcción del modelo final, facilitando la validación de dimensiones, la optimización de componentes y la generación de documentación técnica para futuras mejoras o procesos de fabricación.

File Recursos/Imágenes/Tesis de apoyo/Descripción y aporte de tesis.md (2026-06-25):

## Descripción y Aporte de Tesis

### 1. Tesis – Universidad Nacional Agraria La Molina

## Descripción

Esta tesis estudia la problemática de la escasez de recursos hídricos en zonas rurales mediante el análisis de sistemas de captación de agua de niebla. Se evalúan factores determinantes como la velocidad del viento, la densidad de la niebla, la ubicación geográfica y el diseño estructural de los colectores, los cuales influyen directamente en la eficiencia del sistema.

## Aporte al Proyecto

Aporta una base técnica fundamental para el diseño del sistema atrapanieblas, permitiendo definir criterios de optimización en la estructura y ubicación de los paneles. Además, respalda la viabilidad del proyecto como una solución sostenible y de bajo costo para zonas con escasez de agua, e introduce la posibilidad de integrar tecnología IoT para el monitoreo en tiempo real.

---

### 2. Tesis – Universidad Ricardo Palma

## Descripción

Esta investigación analiza tecnologías de captación de agua atmosférica como alternativa frente a la escasez hídrica, enfocándose en sistemas atrapanieblas para la recolección de agua mediante la condensación de la humedad ambiental. Se evalúan distintos materiales y configuraciones estructurales, determinando que el rendimiento depende principalmente del tipo de malla y del diseño del colector.

## Aporte al Proyecto

Aporta información técnica clave sobre la selección de materiales, destacando la eficiencia de mallas como la Raschel en la captación de agua. Asimismo, refuerza la viabilidad de los sistemas atrapanieblas como solución sostenible y complementa el proyecto al permitir la integración de sensores e IoT para optimizar su desempeño en tiempo real.

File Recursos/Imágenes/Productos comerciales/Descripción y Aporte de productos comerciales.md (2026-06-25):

## Aportes de productos comerciales.

### 1. Los Cloud Fishers que transforman la niebla en agua limpia en muchos países

## Descripción

Cloud Fishers es una tecnología utilizada en distintos países que permite la captación de agua a partir de la niebla mediante sistemas de mallas atrapanieblas. Estas estructuras interceptan las microgotas presentes en el aire, las condensan y las conducen hacia sistemas de almacenamiento para su posterior uso.

## Aporte al Proyecto

Esta tecnología sirve como referencia para el diseño del sistema atrapanieblas del proyecto, ya que demuestra la viabilidad de obtener agua potable a partir de la niebla en diferentes regiones del mundo.

---

### 2. Brochure Producto – Sistema de captación y tratamiento

## Descripción

Este documento presenta un sistema de captación de agua de niebla integrado con tecnologías de almacenamiento y tratamiento. Explica el funcionamiento de soluciones orientadas a entornos inteligentes y sostenibles, donde el agua recolectada puede ser gestionada de manera eficiente.

## Aporte al Proyecto

Aporta información sobre el diseño de sistemas integrados de captación y gestión del recurso hídrico, lo cual permite mejorar la propuesta del proyecto incorporando etapas de almacenamiento y posible tratamiento del agua recolectada.

---

### 3. Smart Environment – Sistema de monitoreo ambiental

## Descripción

Este documento describe un enfoque de sistema inteligente orientado al monitoreo de variables ambientales, aplicado a soluciones sostenibles. Se enfoca en el uso de tecnologías para supervisar condiciones del entorno en tiempo real.

## Aporte al Proyecto

Aporta la base conceptual para la integración de sensores y monitoreo en tiempo real dentro del sistema atrapanieblas, permitiendo mejorar el control y la eficiencia del proceso de captación de agua.

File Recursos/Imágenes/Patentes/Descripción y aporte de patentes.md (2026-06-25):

# Patente de Apoyo 1

## Nombre de la Patente

Expediente 001116-2024/DIN: Atrapanieblas multifuncional autosustentable para un riego uniforme

## Descripción

Esta patente presenta un sistema autosustentable diseñado para captar agua de niebla y utilizarla en procesos de reforestación. El dispositivo incorpora una hélice atrapanieblas que recolecta la humedad atmosférica y la conduce hacia un tanque de almacenamiento integrado en la estructura de soporte. Posteriormente, el agua almacenada es distribuida mediante brazos laterales que permiten un riego por goteo uniforme sobre la vegetación. El sistema opera de forma autónoma y no requiere fuentes externas de energía para su funcionamiento.

## Aporte al Proyecto

Esta patente proporciona una referencia tecnológica para el diseño de sistemas de captación y distribución de agua provenientes de la niebla. Además, aporta información sobre mecanismos de almacenamiento y riego automatizado que pueden ser adaptados para mejorar la eficiencia y sostenibilidad del proyecto.

---

# Patente de Apoyo 2

## Nombre de la Patente

CN110144994A: Cobweb-like Mist-Catching Water Drinking Device

## Descripción

Esta patente describe un sistema de captación de agua atmosférica mediante una malla con estructura similar a una telaraña. El dispositivo recolecta microgotas de niebla y las conduce hacia un sistema de almacenamiento. Posteriormente, el agua es sometida a procesos de filtración utilizando grafeno poroso tridimensional y carbón activado, seguidos de un tratamiento térmico para eliminar microorganismos y garantizar su calidad.

## Aporte al Proyecto

Esta patente aporta información relevante sobre tecnologías de captación y purificación de agua obtenida de la niebla. Asimismo, permite identificar materiales y procesos que podrían incorporarse para mejorar la calidad del agua recolectada y ampliar las funcionalidades del sistema propuesto.

---

# Patente de Apoyo 3

## Nombre de la Patente

US11693434B2: Water Quality Monitoring and Control System

## Descripción

Esta patente presenta un sistema inteligente para el monitoreo y control de la calidad del agua mediante sensores, actuadores y un sistema embebido de procesamiento de datos. El sistema recopila información en tiempo real, compara los resultados con parámetros previamente establecidos y ejecuta acciones correctivas o genera alertas cuando detecta anomalías en las condiciones del recurso hídrico.

## Aporte al Proyecto

Esta patente proporciona una base tecnológica para la incorporación de sistemas de monitoreo en proyectos relacionados con recursos hídricos. Su aplicación permitiría supervisar la calidad del agua recolectada, optimizar la gestión del recurso y garantizar condiciones adecuadas para su almacenamiento y uso.

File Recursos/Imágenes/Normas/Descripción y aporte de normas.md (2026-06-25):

# Norma Técnica 1

## Nombre de la Norma

Decreto Supremo N.° 004-2017-MINAM – Estándares de Calidad Ambiental (ECA) para Agua

## Descripción

Esta norma establece los Estándares de Calidad Ambiental para el agua en el Perú, definiendo los valores máximos permitidos de diversos parámetros físicos, químicos y biológicos según el uso destinado al recurso hídrico. Su finalidad es proteger la salud de la población y conservar los ecosistemas acuáticos mediante criterios técnicos que permitan evaluar la calidad del agua.

## Aporte al Proyecto

Esta norma sirve como referencia para evaluar la calidad del agua recolectada por el sistema atrapanieblas. Los sensores de pH, turbidez y TDS implementados en el proyecto permiten obtener datos que pueden compararse con los parámetros establecidos en el ECA para determinar si el agua captada cumple con condiciones adecuadas para su aprovechamiento.

---

# Norma Técnica 2

## Nombre de la Norma

ISO 7027-1 – Calidad del Agua: Determinación de la Turbidez

## Descripción

La norma ISO 7027-1 establece los métodos para la medición de la turbidez en muestras de agua mediante técnicas ópticas basadas en la dispersión de la luz. Esta norma proporciona procedimientos estandarizados que garantizan resultados precisos y comparables para evaluar la presencia de partículas suspendidas en el agua.

## Aporte al Proyecto

La aplicación de esta norma respalda el uso del sensor de turbidez incorporado en el sistema de monitoreo. Gracias a ella es posible interpretar adecuadamente los datos obtenidos y evaluar la claridad del agua recolectada por el atrapanieblas, contribuyendo a la verificación de su calidad para posibles usos futuros.

---

# Norma Técnica 3

## Nombre de la Norma

ISO 10523 – Calidad del Agua: Determinación del pH

## Descripción

La norma ISO 10523 especifica los procedimientos para la determinación electrométrica del pH en muestras de agua. El pH es uno de los parámetros más importantes para evaluar las características químicas del agua, ya que permite identificar si presenta condiciones ácidas, neutras o alcalinas.

## Aporte al Proyecto

Esta norma sustenta técnicamente el uso del sensor de pH implementado en el prototipo. Los valores obtenidos permiten monitorear la calidad química del agua captada por la malla atrapanieblas y verificar si sus características son adecuadas para diferentes aplicaciones ambientales o agrícolas.

---

# Norma Técnica 4

## Nombre de la Norma

ISO 7888 – Calidad del Agua: Determinación del Color

## Descripción

La norma ISO 7888 establece métodos para la determinación y evaluación del color en muestras de agua. El color es un parámetro físico que puede indicar la presencia de materia orgánica, minerales u otras sustancias disueltas que afectan la apariencia y calidad del agua.

## Aporte al Proyecto

Aunque el sistema actual no incorpora un sensor específico para medir el color del agua, esta norma proporciona una referencia importante para futuras ampliaciones del proyecto. Su aplicación permitiría complementar el monitoreo de calidad del agua y obtener una evaluación más completa de las características del recurso recolectado.

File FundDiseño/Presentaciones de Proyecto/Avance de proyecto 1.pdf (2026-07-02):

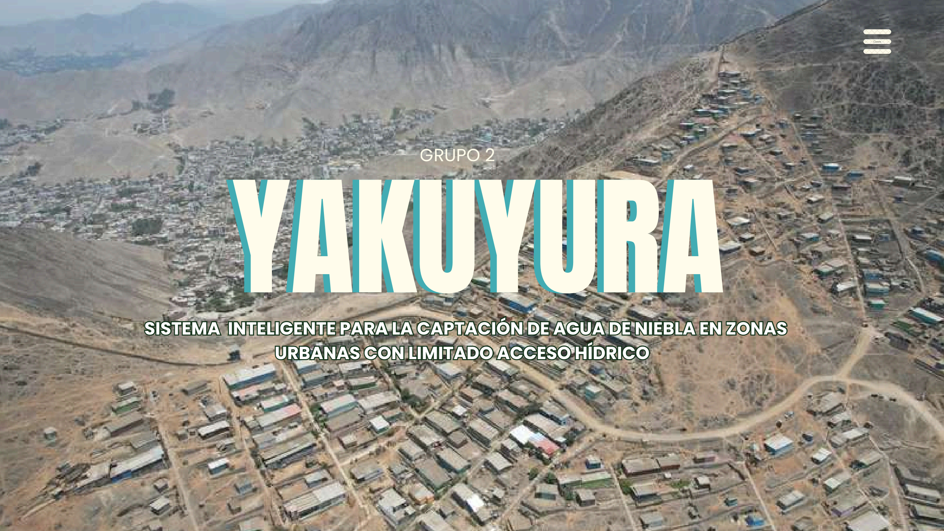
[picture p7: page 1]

# YAKUYURA

SISTEMA INTELIGENTE PARA LA CAPTACIÓN DE AGUA DE NIEBLA EN ZONAS

# URBANAS CON LIMITADO ACCESO HÍDRICO

# SISTEMA INTELIGENTE PARA LA CAPTACIÓN DE AGUA DE NIEBLA EN ZONAS URBANAS CON LIMITADO ACCESO HÍDRICO

# YAKUYURA

# GRUPO 2

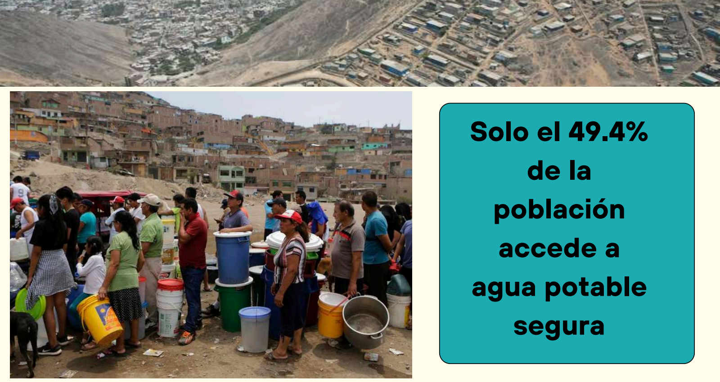
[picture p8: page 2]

# Solo el 49.4% de la población accede a agua potable segura

# ¿Cómo puede una ciudad con alta humedad seguir enfrentando escasez de agua?

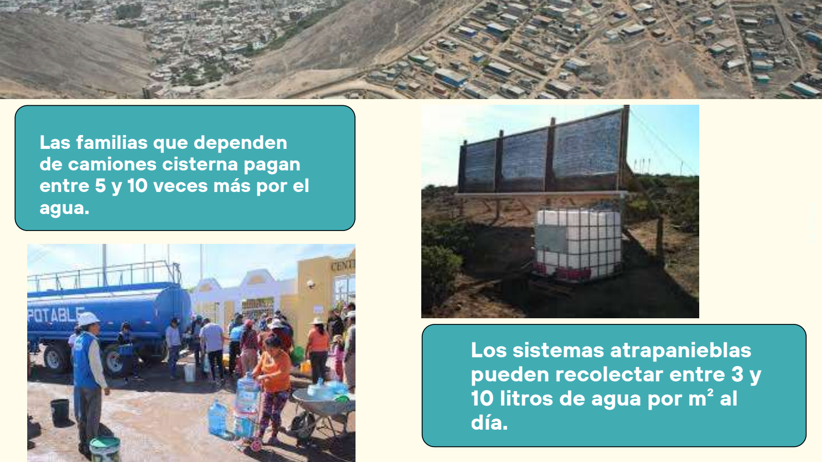
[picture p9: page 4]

# PAGE 02

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
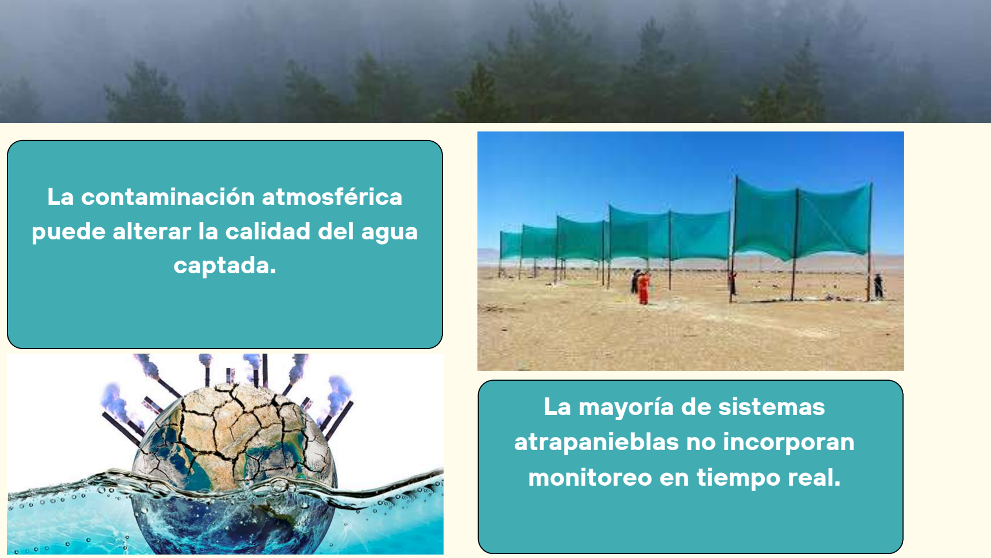
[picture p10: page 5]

# La contaminación atmosférica puede alterar la calidad del agua

captada.

# La mayoría de sistemas atrapanieblas no incorporan

monitoreo en tiempo real.

# PRESENTAMOS

# YAKUYURA

# SISTEMA INTELIGENTE PARA LA CAPTACIÓN DE AGUA DE NIEBLA EN ZONAS URBANAS CON LIMITADO ACCESO HÍDRICO

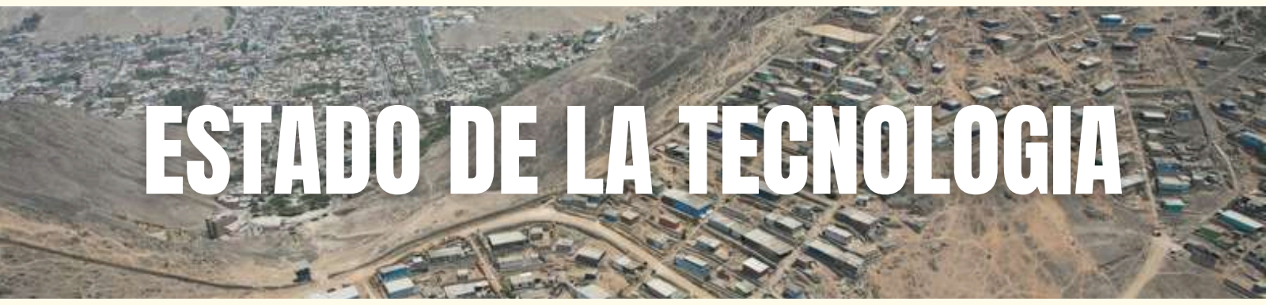
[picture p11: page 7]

# ESTADO DE LA TECNOLOGIA

# TECNOLOGIA EXISTENTE EN EL AMBITO COMERCIAL

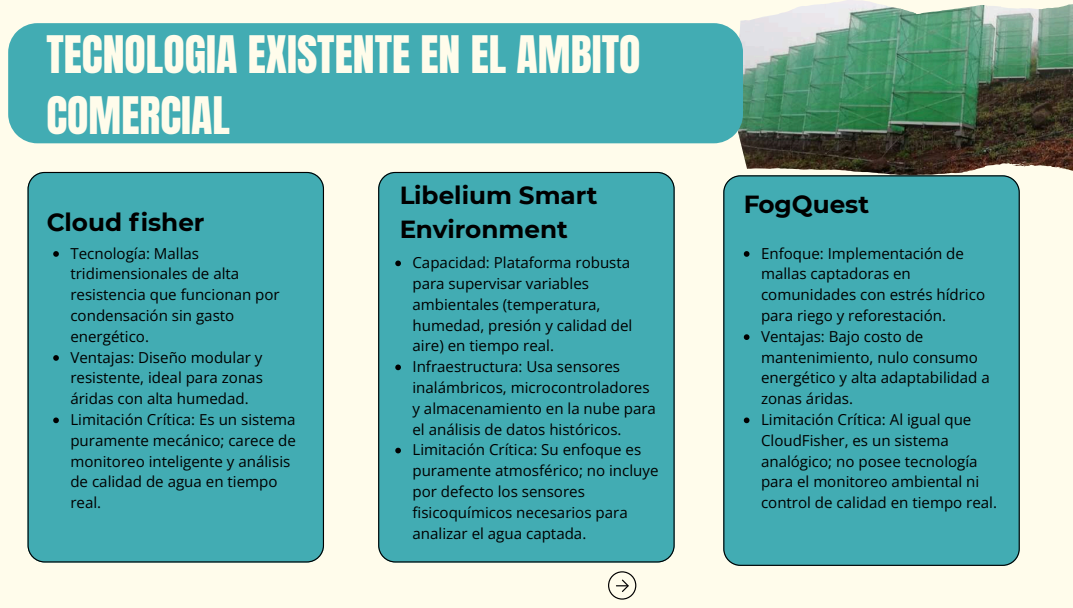
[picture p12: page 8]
Libelium Smart Environment; FogQuest

Cloud fisher
Tecnología: Mallas
tridimensionales de alta
resistencia que funcionan por
condensación sin gasto
energético.
Ventajas: Diseño modular y
resistente, ideal para zonas
áridas con alta humedad.
Limitación Crítica: Es un sistema
puramente mecánico; carece de
monitoreo inteligente y análisis
de calidad de agua en tiempo
real.

Enfoque: Implementación de
mallas captadoras en
comunidades con estrés hídrico
para riego y reforestación.
Ventajas: Bajo costo de
mantenimiento, nulo consumo
energético y alta adaptabilidad a
zonas áridas.
Limitación Crítica: Al igual que
CloudFisher, es un sistema
analógico; no posee tecnología
para el monitoreo ambiental ni
control de calidad en tiempo real.

Capacidad: Plataforma robusta
para supervisar variables
ambientales (temperatura,
humedad, presión y calidad del
aire) en tiempo real.
Infraestructura: Usa sensores
inalámbricos, microcontroladores
y almacenamiento en la nube para
el análisis de datos históricos.
Limitación Crítica: Su enfoque es
puramente atmosférico; no incluye
por defecto los sensores
fisicoquímicos necesarios para
analizar el agua captada.

# TECNOLOGIA EXISTENTE EN EL AMBITO PATENTES

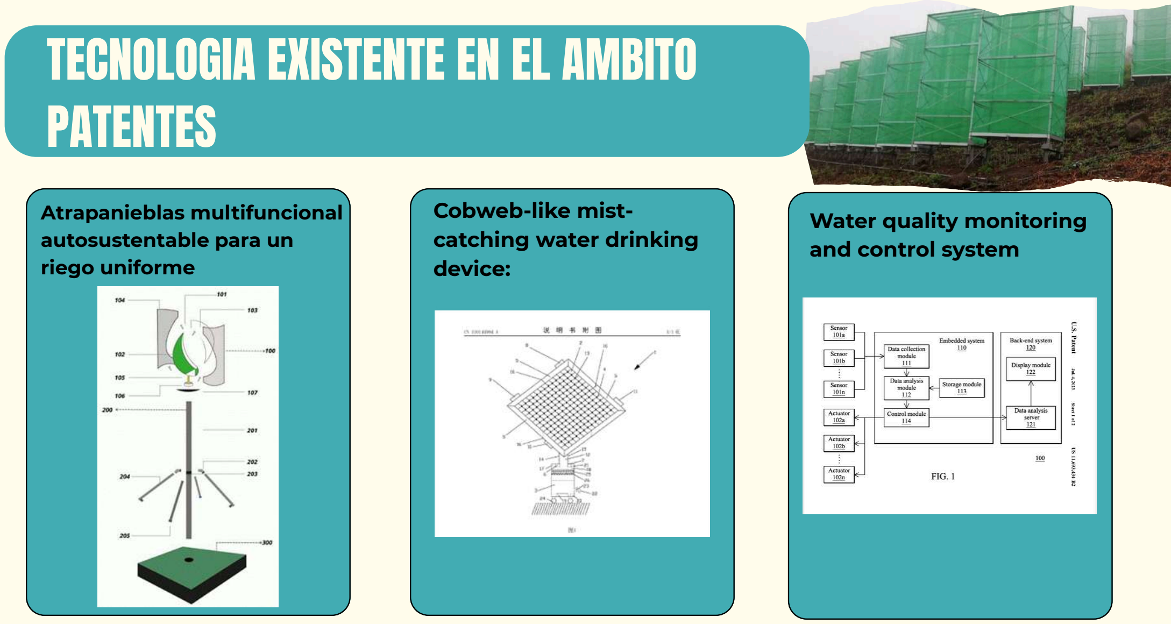
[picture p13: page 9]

# Atrapanieblas multifuncional autosustentable para un riego uniforme

# Cobweb-like mist-catching water drinking device:

# Water quality monitoring and control system

# FACTORES COMUNES EN EL ESTADO DEL ARTE

# TESIS UNIVERSIDAD NACIONAL AGRARIA LA MOLINA

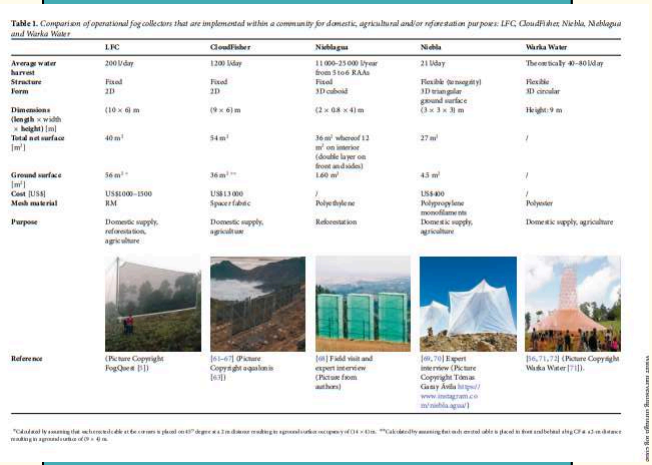
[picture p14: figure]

# Fundamento Técnico: Identifica factores críticos para la eficiencia (viento, densidad de niebla y

diseño estructural).

# Validación: Confirma que es una solución de bajo costo y alta

viabilidad para zonas rurales.

# Evolución del Proyecto: El estudio sirve de base para transformar el modelo convencional en uno inteligente, integrando IoT para el monitoreo automatizado de variables climáticas y volumen de

agua en tiempo real.

# Factor Crítico: El rendimiento depende directamente del tipo de malla (destacando la malla Raschel)

y del diseño estructural del colector.

# Resultados: Confirma que es una tecnología de bajo impacto ambiental y alta viabilidad en climas

con neblina.

# Aporte al Proyecto: Proporciona los parámetros técnicos para optimizar la captación física, permitiendo que la integración de sensores e IoT maximice el volumen recolectado

según el entorno.

# Revisión de sistemas

atrapanieblas.

# TESIS UNIVERSIDAD RICARDO

PALMA .

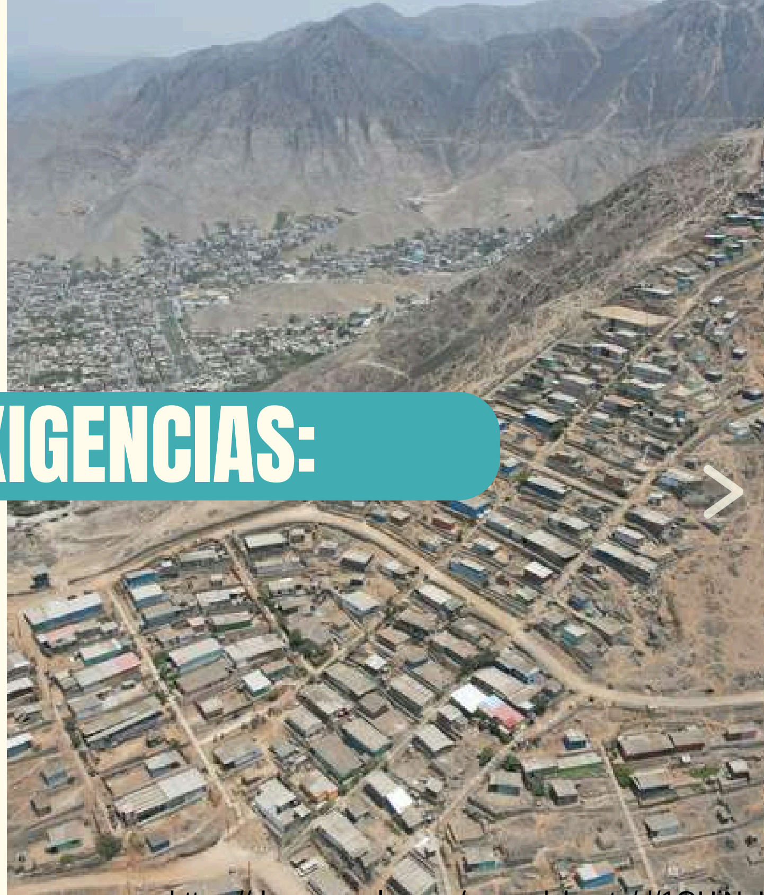
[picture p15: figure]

# LISTA DE EXIGENCIAS:

# LISTA DE EXIGENCIAS

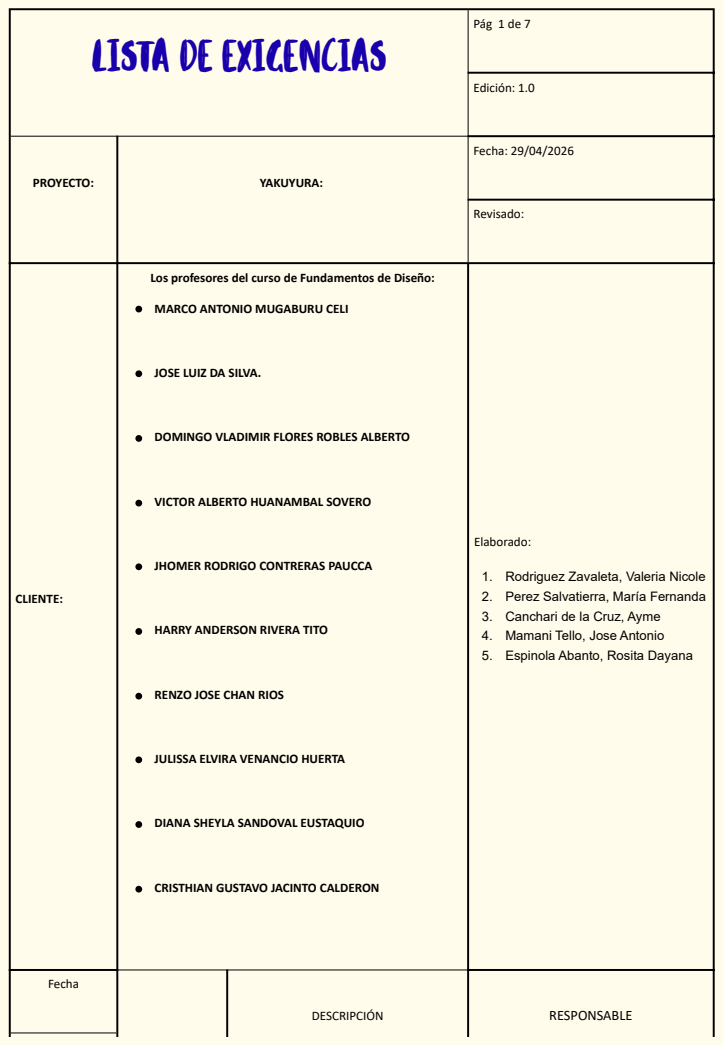
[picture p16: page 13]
Edición: 1.0; Revisado:; CLIENTE:; Elaborado:; Fecha; DESCRIPCIÓN; RESPONSABLE

PROYECTO: | YAKUYURA: | Fecha: 29/04/2026

Los profesores del curso de Fundamentos de Diseño:

MARCO ANTONIO MUGABURU CELI

JOSE LUIZ DA SILVA.

DOMINGO VLADIMIR FLORES ROBLES ALBERTO

VICTOR ALBERTO HUANAMBAL SOVERO

JHOMER RODRIGO CONTRERAS PAUCCA

1. Rodriguez Zavaleta, Valeria Nicole
2. Perez Salvatierra, María Fernanda
3. Canchari de la Cruz, Ayme
4. Mamani Tello, Jose Antonio
5. Espinola Abanto, Rosita Dayana

HARRY ANDERSON RIVERA TITO

RENZO JOSE CHAN RIOS

JULISSA ELVIRA VENANCIO HUERTA

DIANA SHEYLA SANDOVAL EUSTAQUIO

CRISTHIAN GUSTAVO JACINTO CALDERON

(cambios)

28/04/2026 | E

FUNCIÓN PRINCIPAL:

Captar agua de niebla y evaluar su calidad mediante la medición de pH, conductividad y turbidez para su uso en riego, aplicando métodos estandarizados (ISO 7027-1, ISO 10523, ISO 7888)(1) (https://www.zotero.org/google-docs/?DSFb8U)(2) (https://www.zotero.org/google-docs/?PmxobH) (3)considerando (https://www.zotero.org/google-docs/?kOAhaM) los Estándares de Calidad Ambiental para Agua (DS N° 004-2017-MINAM) (4)y (https://www.zotero.org/google-docs/?CdiYSG) criterios de uso agrícola de la FAO (2017)(5), (https://www.zotero.org/google-docs/?Za9Sbp) así como la influencia de contaminantes atmosféricos en la composición del agua (OMS, 2023)(6). (https://www.zotero.org/google-docs/?TARi8P)

Todos

28/04/2026

GEOMETRÍA:

E

El sistema deberá contar con una estructura de captación con altura entre 0.5m, área mínima de 0.2 m² e inclinación entre 20° y 45°, permitiendo la recolección eficiente del agua y su conducción hacia un sistema de almacenamiento de 10 a 15L.

Ayme

D

Se busca mejorar la eficiencia de captación mediante diseños optimizados sin incrementar significativamente el costo del sistema.

Valeria

FUERZAS:

La estructura deberá resistir condiciones ambientales, incluyendo viento ≥ 5 m/s y

28/04/2026 | E | Maria Fernanda

cargas entre 25 y 50 kg, establecidos como criterios de diseño del sistema, considerando la variabilidad climática y condiciones atmosféricas del entorno (NOAA, 2022; Evaluación de necesidades tecnológicas para el cambio climático en el Perú)(7). (https://www.zotero.org/google-docs/?VdbmG5) Asimismo, deberá contar con protección mínima IP ≥ 24 contra humedad y polvo (IEC 60529), garantizando su durabilidad frente a la presencia de contaminantes atmosféricos (OMS, 2023) (6).

28/04/2026 | | MATERIA:
| E | La niebla y la humedad más el flujo de viento se convierte en agua a través del sistema | Valeria
28/04/2026 | | ENERGÍA: | Dayana
| E | Conexión eléctrica por cable
| D | Baterías de Litio (12V 10Ah) para alimentar el sistema con una autonomía de aproximadamente 3 dias solo para monitoreo
| D | Sistema de energía: panel solar además de incluir baterías de respaldo
| | SEÑALES:
| | Entradas:
| | ENERGÍA
| E | Energía eléctrica
| | SEÑALES

28/04/2026 | TODOS
| Señal de control ON/OFF
E | Señal del sensor de pH
E | Señal del sensor de turbidez
E | Variables ambientales (humedad, temperatura, presión, etc.)
E | Señal de nivel de tanque
| Salidas:
| ENERGÍA
E | Calor disipado del sistema
| SEÑALES
| Estado del sistema (encendido/apagado)
E | Señal del volumen disponible en el tanque
E | Visualización y registro de calidad del agua y aire
E | Alertas de operación o mantenimiento
E | Recomendaciones para toma de decisiones
| | CONTROL:

El sistema de captación y monitoreo de

28/04/2026 | TODOS

E

niebla debe operar de manera estable y continua en todas sus etapas, desde la recolección de agua mediante mallas captadoras hasta el almacenamiento y análisis de calidad. Se debe garantizar el control del flujo de agua recolectada, así como la correcta adquisición de datos ambientales mediante sensores (temperatura, humedad, presión y calidad del aire). Asimismo, el sistema debe asegurar que la secuencia de operación (captación, filtración, almacenamiento, medición y visualización de datos) se ejecute en el orden correcto y sin interrupciones. Además, el sistema debe ser capaz de reiniciar automáticamente o manualmente sus operaciones ante fallas o variaciones en las condiciones ambientales, sin comprometer la integridad de los datos ni el
funcionamiento del dispositivo.

28/04/2026

| | ELECTRONICA (Hardware)
| E | El sistema debe permitir la adquisición de datos de variables ambientales y de nivel de agua mediante dispositivos de medición. | Dayana
| E | El sistema debe contar con una unidad de procesamiento capaz de interpretar la información obtenida y gestionar la activación de alertas. | Jose
| E | Se deben incorporar elementos de salida para la notificación de eventos críticos, considerando protección frente a condiciones ambientales como la humedad. | Dayana
28/04/2026 | | SOFTWARE:

El sistema debe procesar la información
obtenida, generando alertas en función de
límites previamente establecidos, así como | Dayana

permitir el registro y acceso remoto a los datos.

28/04/2026

| | COMUNICACIONES:
| E | El sistema debe permitir la transmisión de datos hacia una plataforma remota, facilitando el monitoreo en tiempo real y la generación de alertas ante condiciones críticas. | Ayme
| E | SEGURIDAD: El sistema debe operar con niveles de voltaje seguros y garantizar la protección de la información durante su transmisión, asegurando confidencialidad, integridad y disponibilidad conforme a estándares ISO (8). (https://www.zotero.org/google-docs/?CAAXnD) | Valeria
28/04/2026 | E | ERGONOMÍA: El sistema debe presentar un diseño compacto y de fácil operación, permitiendo una interacción sencilla y un mantenimiento accesible para el usuario en condiciones reales de uso(9). (https://www.zotero.org/google-docs/?ovqdZg) | Valeria
| | FABRICACIÓN:
| | La fabricación del sistema debe incluir un nodo de monitoreo ambiental compuesto por un microcontrolador y sensores , integrados en una sola unidad. Este nodo debe estar protegido frente a humedad, garantizando su durabilidad, en concordancia con la Ley N° 28611 – Ley General del Ambiente. Asimismo, debe permitir la salida de calor, contar con protección contra el ingreso de agua (sellado tipo IP) y facilitar el mantenimiento.
| | CONTROL DE CALIDAD:
28/04/2026 | E

TODOS

28/04/2026

E | El sistema debe evaluar la calidad del agua recolectada según el D.S. N° 004-2017-MINAM (Categoría 3 – D1), asegurando un pH entre 6.5 y 8.5 y considerando la conductividad como indicador de salinidad (4). La medición de pH, conductividad y turbidez deben seguir normas ISO 10523, ISO 7888 e ISO 7027-1, con sensores calibrados(1-3). Además, se debe considerar el impacto de la calidad del aire, según lineamientos de la OMS (2023) (6). | Maria Fernanda
28/04/2026 | | MONTAJE:
| E | El sistema debe instalarse de forma fija y segura, garantizando estabilidad ante viento y humedad, para evitar desplazamientos o fallas. La malla debe orientarse al viento predominante para maximizar la captación, y el tanque colocarse sobre una base firme y protegida para prevenir fugas y contaminación. La instalación eléctrica debe contar con conexiones seguras y protección adecuada. | Jose
28/04/2026 | | TRANSPORTE:
| E | El sistema debe ser modular para facilitar su transporte e instalación en diversas zonas, asegurando adaptabilidad. Sus componentes deben desmontarse sin afectar su funcionamiento y protegerse durante el traslado frente a golpes, vibraciones y condiciones adversas.El prototipo debe tener un peso aproximado entre 10 y 25 kg en vacío, permitiendo su transporte manual. | Valeria
| USO:
E | El sistema operará bajo condiciones ambientales de alta humedad (70% - 90%) y presencia de neblina persistente en VMT. | Ayme

28/04/2026

Para la captación hídrica se utilizará malla Raschel, la cual debe resistir vientos moderados y la exposición a la intemperie

Mafer

El monitoreo se realizará mediante un microcontrolador ESP32 conectado a sensores para identificar cuándo las condiciones climáticas son óptimas para la captación, además sobre la calidad del agua obtenida. | Dayana
E | MANTENIMIENTO:
| Componentes físicos:Limpieza mensual de la malla atrapanieblas para eliminar acumulación de material particulado (PM2.5/PM10) y polvo | Valeria

28/04/2026

E | Componentes electrónicos: Se debe revisar trimestralmente que los cables no tengan sarro o humedad. Los sensores de pH y nivel se deben limpiar para evitar que el agua estancada dé lecturas falsas. | Dayana
| | COSTOS: | TODOS
28/04/2026 | E

Basado en las horas de trabajo en clase (80
hrs de clase) y 60 hrs de trabajo externo. A S/ 40/hr, el costo de diseño es S/ 5600. Los materiales se mantienen en un presupuesto máximo de S/ 500

PLAZOS:

28/04/2026 | E | TODOS

El proyecto se desarrolla durante el periodo académico 2026-1 (16/03 al 09/07). Se han establecido los siguientes hitos de evaluación:

- 7 de mayo: Entrega del Avance 1 (Parcial), presentación de la investigación base, selección final de componentes, pitch del proyecto.
- 2 de julio: Entrega del Avance 2 y sustentación final del prototipo funcional e informe de resultado

# CAJA NEGRA

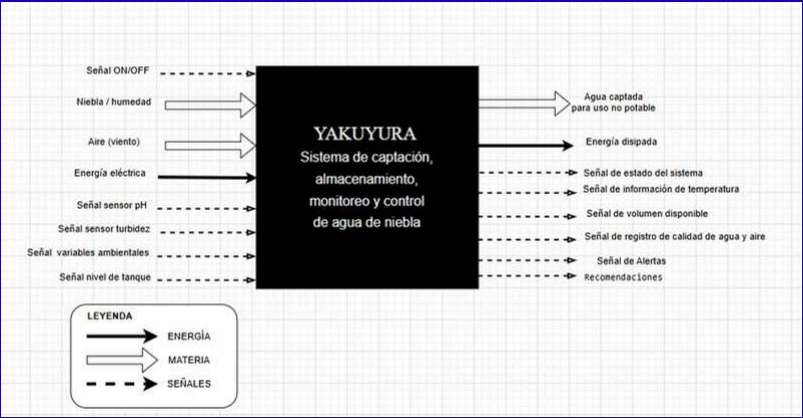
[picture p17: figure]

# SECUENCIA DE OPERACIONES:

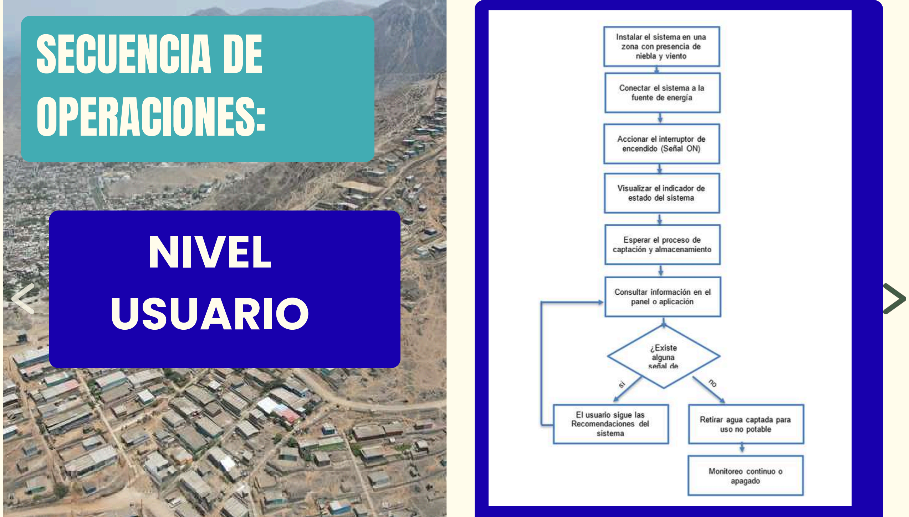
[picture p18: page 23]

# NIVEL USUARIO

# SECUENCIA DE OPERACIONES:

# NIVEL DISPOSITIVO

# ESTRUCTURA DE FUNCIONES:

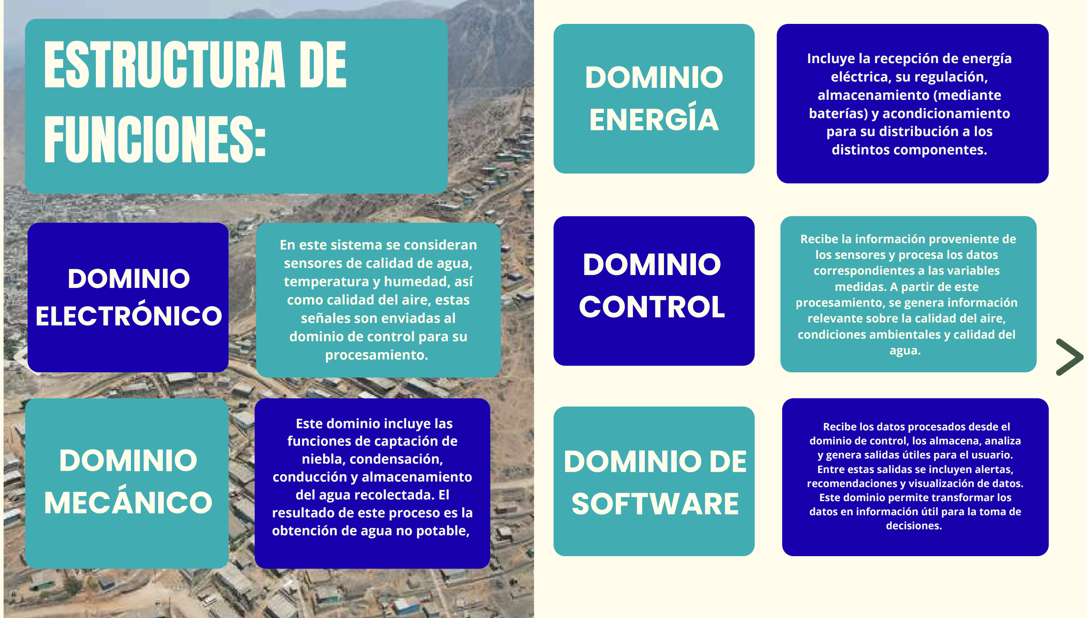
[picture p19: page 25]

# DOMINIO ENERGÍA

# DOMINIO DE SOFTWARE

# DOMINIO ELECTRÓNICO

# DOMINIO MECÁNICO

# DOMINIO CONTROL

# En este sistema se consideran

sensores de calidad de agua,

# temperatura y humedad, así como calidad del aire, estas señales son enviadas al dominio de control para su

procesamiento.

# Este dominio incluye las funciones de captación de

niebla, condensación,

# conducción y almacenamiento del agua recolectada. El resultado de este proceso es la

obtención de agua no potable,

# Incluye la recepción de energía

eléctrica, su regulación,

# almacenamiento (mediante baterías) y acondicionamiento para su distribución a los

distintos componentes.

# Recibe la información proveniente de los sensores y procesa los datos correspondientes a las variables medidas. A partir de este procesamiento, se genera información

relevante sobre la calidad del aire,

# condiciones ambientales y calidad del

agua.

# Recibe los datos procesados desde el dominio de control, los almacena, analiza

y genera salidas útiles para el usuario. Entre estas salidas se incluyen alertas, recomendaciones y visualización de datos.

# Este dominio permite transformar los datos en información útil para la toma de

decisiones.

# ESTRUCTURA DE FUNCIONES INTEGRADAS

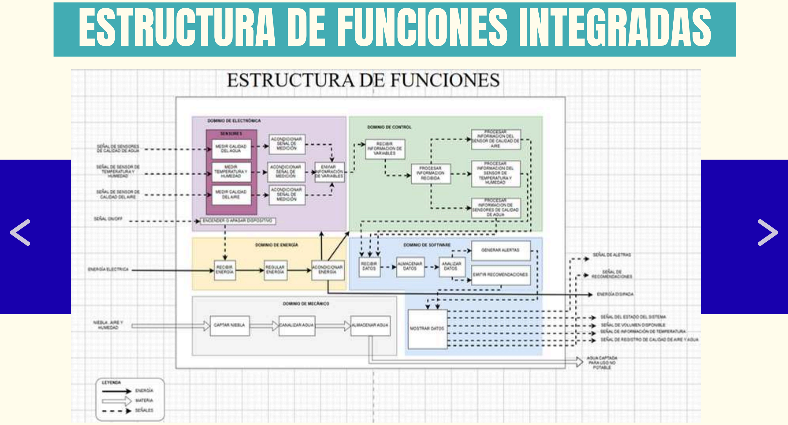
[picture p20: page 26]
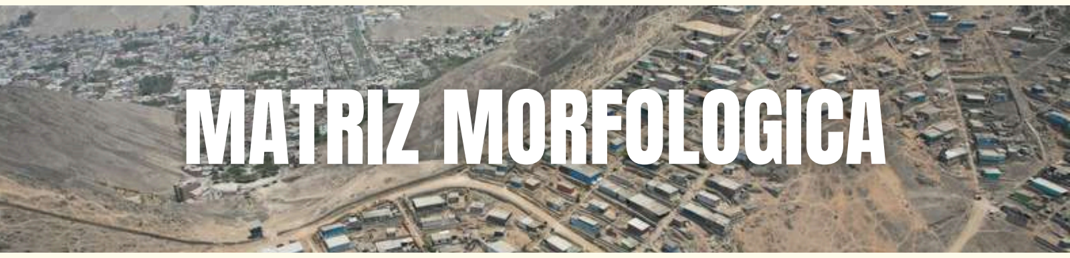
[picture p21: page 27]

# MATRIZ MORFOLOGICA

# DOMINIO ELECTRONICO

# Selección: Alternativa 01

# Monitoreo Atmosférico (BME280 + NDIR): BME280: Integra presión, temperatura y humedad en un

solo componente digital, optimizando el hardware (ESP).

# Sensor NDIR: Medición de gases con mayor vida útil y

estabilidad térmica que los sensores comunes.

# Análisis de Calidad de Agua (pH, Turbidez, TDS): Incluye etapas de amplificación para estabilizar señales

débiles y eliminar ruido, asegurando datos fiables.

# Objetivo Crítico: Correlacionar la calidad del aire con la

pureza del agua recolectada.

# Conclusión: Un ecosistema sensorial robusto que garantiza la precisión necesaria para validar el sistema como fuente de

agua segura.

# DOMINIO MECÁNICO

# Selección: Alternativa 01

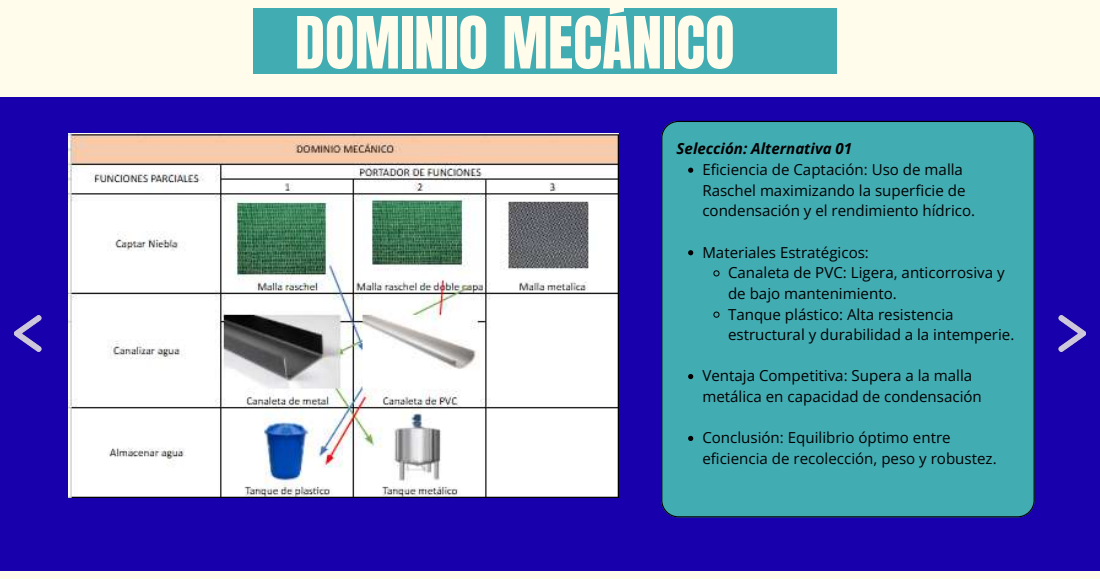
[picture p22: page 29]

Eficiencia de Captación: Uso de malla
Raschel maximizando la superficie de
condensación y el rendimiento hídrico.

Materiales Estratégicos:
Canaleta de PVC: Ligera, anticorrosiva y
de bajo mantenimiento.
Tanque plástico: Alta resistencia
estructural y durabilidad a la intemperie.

Ventaja Competitiva: Supera a la malla
metálica en capacidad de condensación

Conclusión: Equilibrio óptimo entre
eficiencia de recolección, peso y robustez.

# DOMINIO ENERGÍA

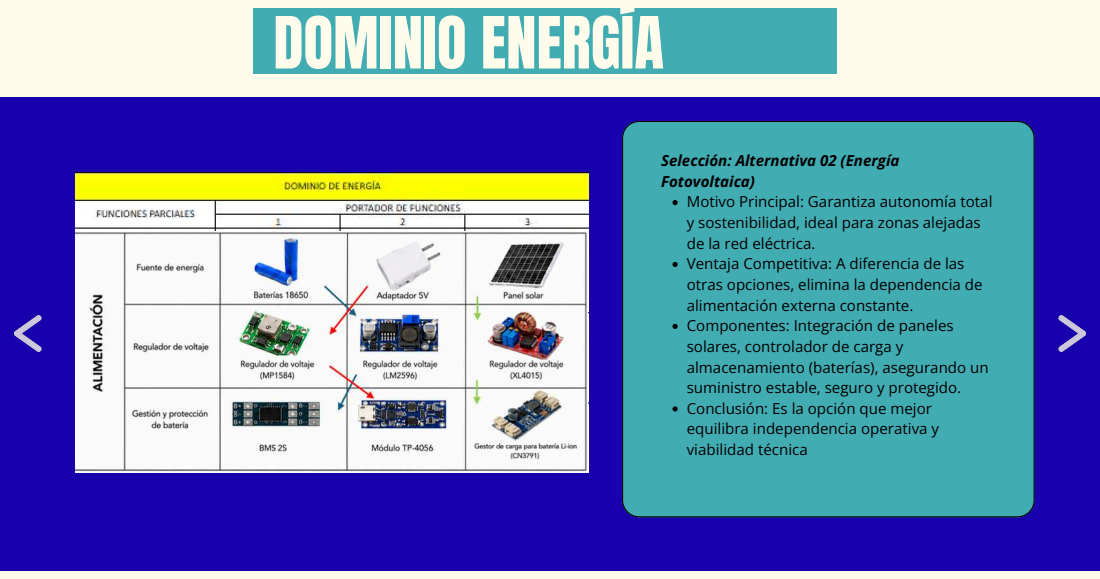
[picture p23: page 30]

Selección: Alternativa 02 (Energía
Fotovoltaica)
Motivo Principal: Garantiza autonomía total
y sostenibilidad, ideal para zonas alejadas
de la red eléctrica.
Ventaja Competitiva: A diferencia de las
otras opciones, elimina la dependencia de
alimentación externa constante.
Componentes: Integración de paneles
solares, controlador de carga y
almacenamiento (baterías), asegurando un
suministro estable, seguro y protegido.
Conclusión: Es la opción que mejor
equilibra independencia operativa y
viabilidad técnica

# DOMINIO CONTROL

# Selección: Alternativa 01

# Cerebro del Sistema: Uso de un microcontrolador

por su equilibrio óptimo entre procesamiento, bajo costo y eficiencia energética.

# Integración Sensorial: Capacidad nativa para

gestionar sensores de calidad de aire,

# temperatura, humedad y calidad del agua en una

sola plataforma.

# Ventaja Competitiva:

Sobre Alt. 02: Menor consumo de energía, crítico para la alimentación solar.

# Sobre Alt. 03: Mayor estabilidad y robustez para una implementación definitiva (no solo

prototipo).

# Conclusión: Solución confiable, compacta y de fácil programación, ideal para sistemas autónomos de

monitoreo remoto.

# DOMINIO DE SOFTWARE

# Selección: Alternativa 03 (Dominio de Software)

# Conectividad y Alcance: Comunicación inalámbrica que elimina el cableado y permite la transmisión

de datos en tiempo real desde los sensores.

# Gestión de Datos: Uso de base de datos en la nube, garantizando accesibilidad remota total y escalabilidad, superando las limitaciones del

almacenamiento local.

# Interfaz y Control: Integración de una aplicación móvil y reglas lógicas para una supervisión moderna y eficiente (superior al uso de pantallas

LCD básicas).

# Conclusión: Una solución IoT robusta que equilibra conectividad, acceso global y

funcionalidad avanzada para el usuario final.

# BOCETOS CONCEPTOS DE SOLUCIÓN

# BOCETOS CONCEPTOS DE SOLUCIÓN

# BOCETO CONCEPTO DE SOLUCIÓN 1

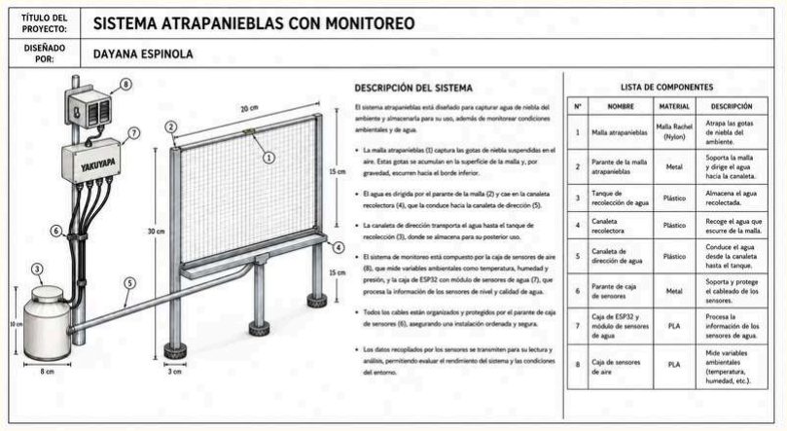
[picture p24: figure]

# BOCETO CONCEPTO DE SOLUCIÓN 2

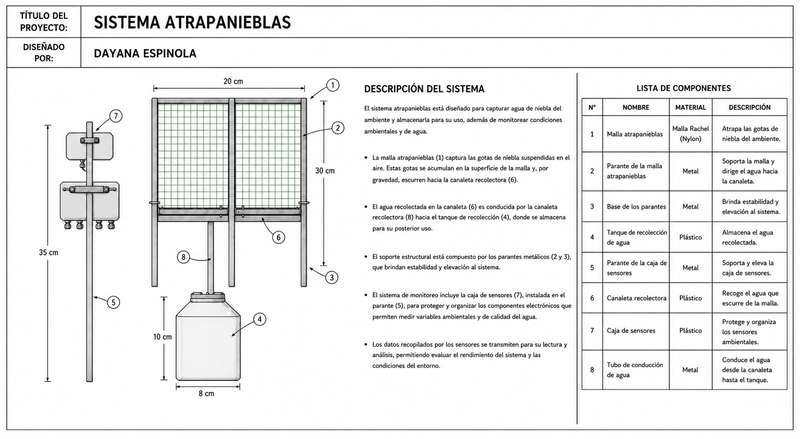
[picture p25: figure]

# BOCETO CONCEPTO DE SOLUCIÓN 3

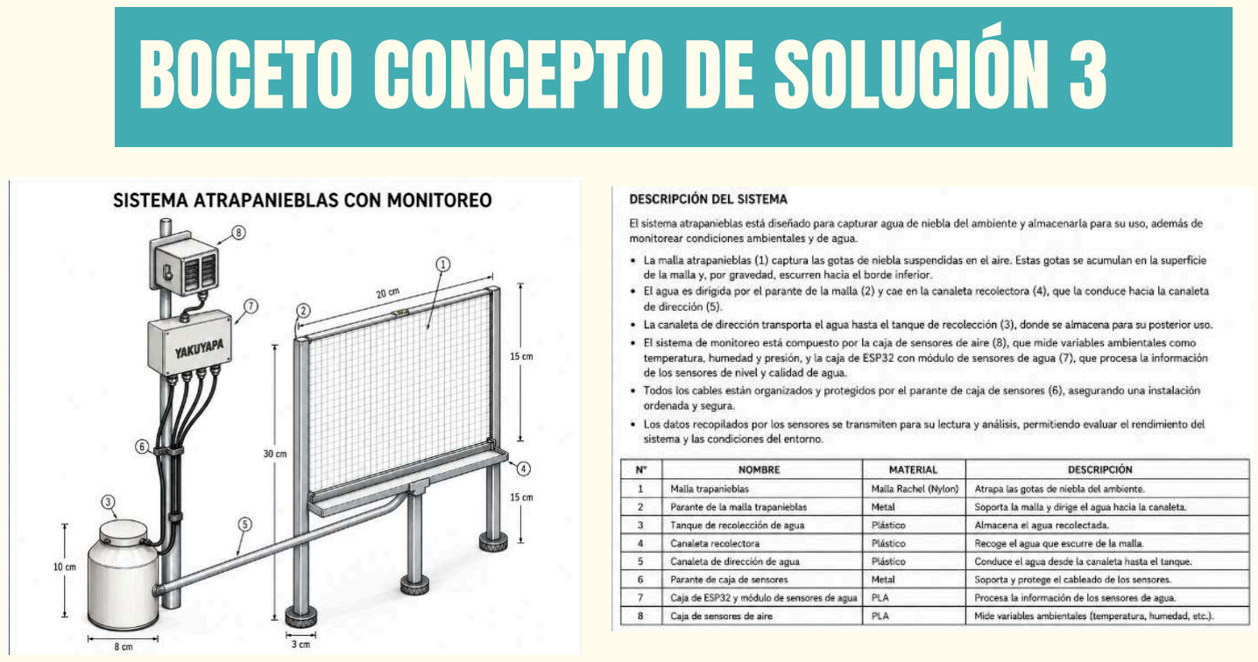
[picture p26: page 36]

# EVALUACIÓN MATRIZ DE PUGH

# MATRIZ DE PUGH

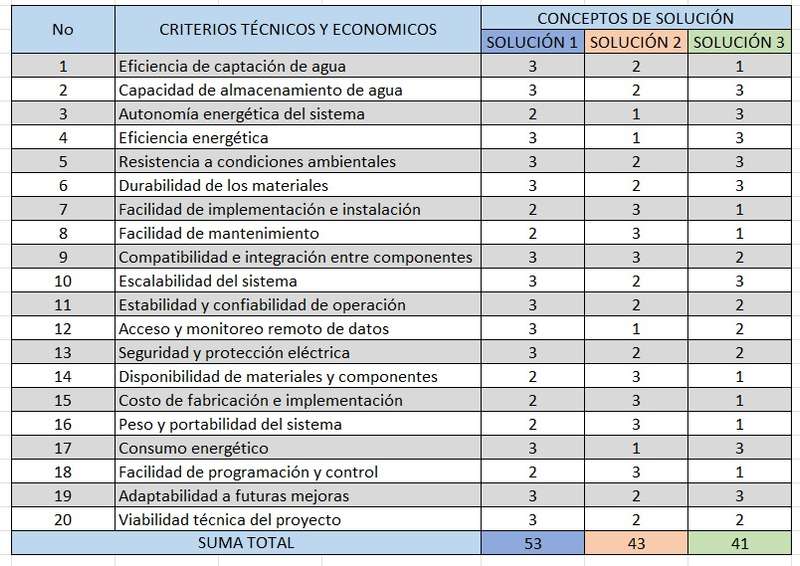
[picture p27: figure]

# SELECCION DE SOLUCIÓN:

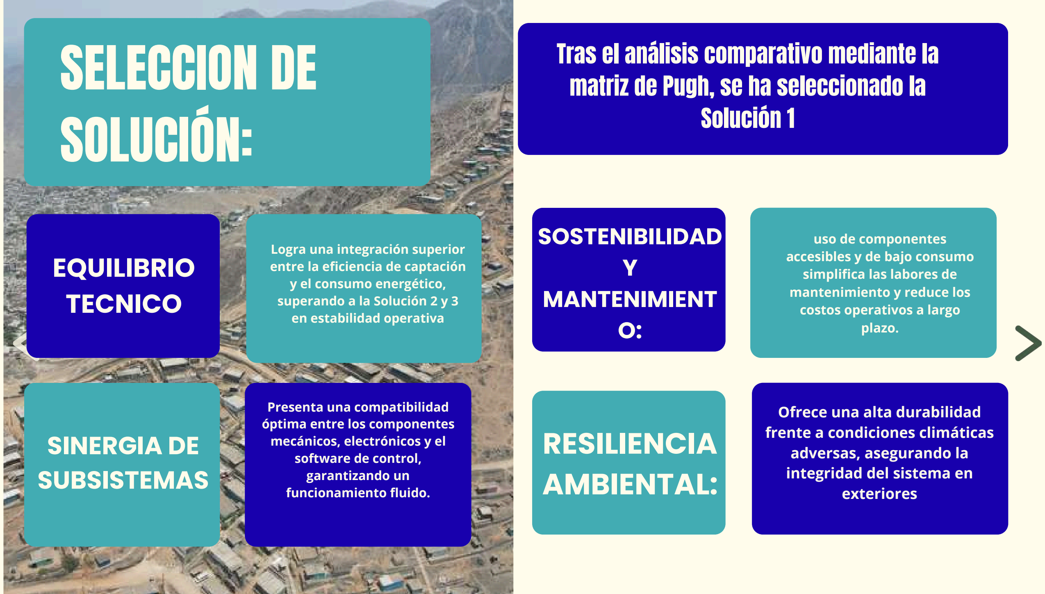
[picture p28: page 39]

# RESILIENCIA AMBIENTAL:

# EQUILIBRIO TECNICO

# SINERGIA DE SUBSISTEMAS

# SOSTENIBILIDAD

Y

# MANTENIMIENT

O:

# Tras el análisis comparativo mediante la matriz de Pugh, se ha seleccionado la Solución 1

# Presenta una compatibilidad óptima entre los componentes mecánicos, electrónicos y el

software de control,

# garantizando un

funcionamiento fluido.

# uso de componentes accesibles y de bajo consumo simplifica las labores de mantenimiento y reduce los costos operativos a largo

plazo.

# Ofrece una alta durabilidad frente a condiciones climáticas adversas, asegurando la integridad del sistema en exteriores

# Logra una integración superior entre la eficiencia de captación

y el consumo energético,

# superando a la Solución 2 y 3 en estabilidad operativa

Fradel and Spies | Home | Services | Project | Contact | End Slide

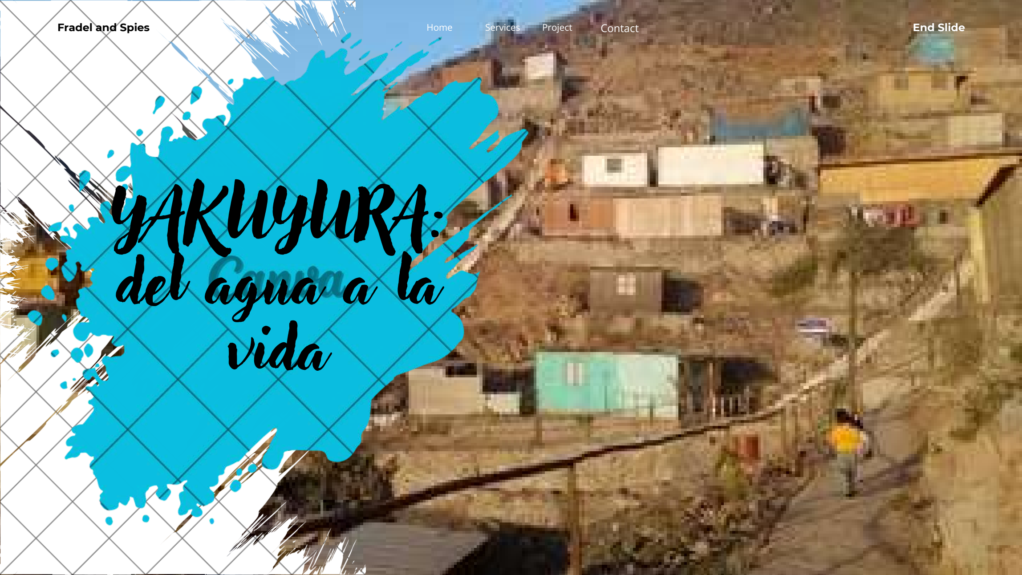
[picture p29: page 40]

# YAKUYURA:

# del agua a la vida

# EQUIPO

# Canchari de la Cruz, Ayme

Espinola Abanto,

# Rosita Dayana

Mamani Tello,

# José Antonio

# Pérez

Salvatierra,

# María Fernanda

# Rodriguez Zavaleta, Valeria Nicole

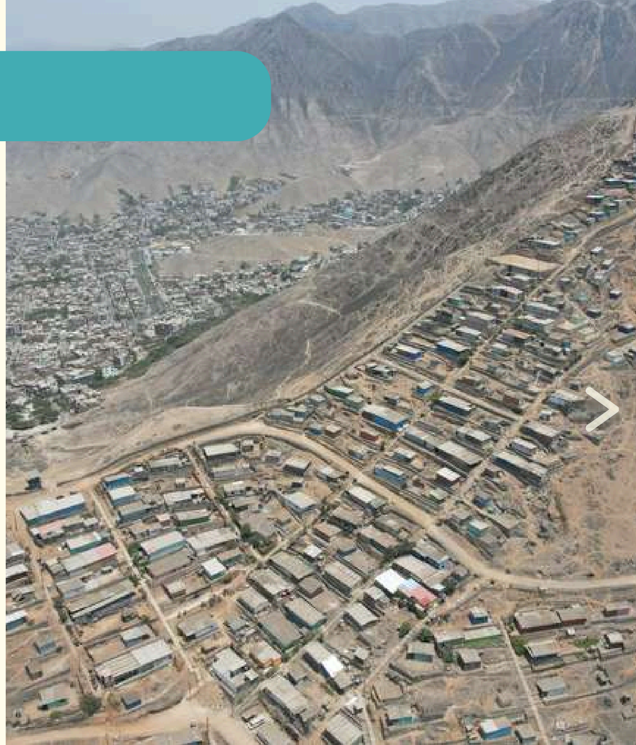
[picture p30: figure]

# BIBLIOGRAFÍA:

# 1.ISO 7027 [Internet]. [citado 26 de abril de 2026]. Disponible en: https://www.iso.org/obp/ui/ #iso:std:iso:7027:-1:ed-1:v1:en

2. ISO 10523 [Internet]. [citado 26 de abril de 2026].

# Disponible en: https://www.iso.org/obp/ui/ #iso:std:iso:10523:ed-2:v1:en 3.ISO 7888 [Internet]. [citado 26 de abril de 2026]. Disponible en: https://www.iso.org/obp/ui/#iso:std:iso:7888:ed-1:v1:en

4.DS-004-2017-MINAM-4.

# 5.FAO [Internet]. [citado 26 de abril de 2026]. Disponible en: https://www.fao.org/home/en/ 6.OMS 2023 [Internet]. [citado 26 de abril de 2026]. Disponible en: https://www.who.int/es/news-room/fact-sheets/detail/ ambient-%28outdoor%29-air-quality-and-health

7.Fillingham J, Harrington A, Deehan M, Renta I, Gugliotti E, Matlock G, et al. 2022 NOAA Science Report.

# 8.ISO 27001 [Internet]. [citado 29 de abril de 2026]. Disponible en: https://www.iso.org/isoiec-27001-information-security.html

9.52075.html [Internet]. [citado 29 de abril de 2026].

# Disponible en: https://www.iso.org/standard/52075.html

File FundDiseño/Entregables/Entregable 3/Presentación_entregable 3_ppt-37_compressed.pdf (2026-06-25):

YAKUYURA; GRUPO 2

SISTEMA INTELIGENTE PARA LA CAPTACIÓN DE AGUA DE NIEBLA EN ZONAS

URBANAS CON LIMITADO ACCESO HÍDRICO

# INTRODUCCIÓN

# CONTEXTO

ALTERNATIVA SOSTENIBLE; Crecimiento urbano y cambio climático; Monitoreo climático; Monitoreo remoto

La captación de agua de
niebla es una fuente no
convencional.

En Lima sur, muchas
familias dependen de
camiones cisterna.

Lima sur tiene alta humedad
y presencia de neblina .

Oportunidad para captar
agua atmosférica
PROPUESTA

Mayor costo, menor
continuidad y calidad
del servicio
LIMITACION ACTUAL

Captación de niebla

solo captan agua

No monitorean la calidad
del agua.

Calidad del agua

No evalúan variables
ambientales en tiempo real.

Transmisión de datos

Solución tecnológico que aprovecha un recurso natural y

promueve la responsabilidad urbana

# PROBLEMÁTICA

Alta humedad y neblina frecuente.; Sistemas atrapanieblas recolectan 3 a 10 L/m2 diarios.; POTENCIAL HÍDRICO; SITUACIÓN ACTUAL; PROBLEMA PRINCIPAL; BRECHA TECNOLÓGICA; PROPUESTA DE SOLUCIÓN; ODS

No monitorean la calidad del
agua.

Solo el 49.4% de la
población accede a
agua potable segura.

No evalúan la contaminación
atmosférica .

En zonas vulnerables
se usan camiones
cisterna.

El agua cuesta entre 5
a 10 veces más.

Sin monitoreo remoto en
tiempo real,

# OBJETIVO GENERAL

# OBJETIVOS ESPECIFICOS

OBJETIVOS

Diseñar e implementar un
sistema inteligente IoT
para captar agua de niebla
y monitorear su calidad y
condiciones climáticas en
Villa María del Triunfo,
evaluando su uso en
aplicaciones no potables.

Implementar un sistema de
monitoreo de variables climáticas.

Diseñar una estructura eficiente de
captación de agua de niebla.

Evaluar la calidad fisicoquímica
del agua recolectada mediante la
medición de parámetros .

Integrar sensores con ESP32 para
monitoreo y transmisión de datos
en tiempo real.

Implementar monitoreo remoto para
visualizar y analizar datos en tiempo
real.

Analizar la relación entre clima,
captación y calidad del agua de niebla.


# ESTADO DE LA TECNOLOGIA

# TECNOLOGIA EXISTENTE EN EL AMBITO COMERCIAL

Libelium Smart Environment; FogQuest

Cloud fisher
Tecnología: Mallas
tridimensionales de alta
resistencia que funcionan por
condensación sin gasto
energético.
Ventajas: Diseño modular y
resistente, ideal para zonas
áridas con alta humedad.
Limitación Crítica: Es un sistema
puramente mecánico; carece de
monitoreo inteligente y análisis
de calidad de agua en tiempo
real.

Enfoque: Implementación de
mallas captadoras en
comunidades con estrés hídrico
para riego y reforestación.
Ventajas: Bajo costo de
mantenimiento, nulo consumo
energético y alta adaptabilidad a
zonas áridas.
Limitación Crítica: Al igual que
CloudFisher, es un sistema
analógico; no posee tecnología
para el monitoreo ambiental ni
control de calidad en tiempo real.

Capacidad: Plataforma robusta
para supervisar variables
ambientales (temperatura,
humedad, presión y calidad del
aire) en tiempo real.
Infraestructura: Usa sensores
inalámbricos, microcontroladores
y almacenamiento en la nube para
el análisis de datos históricos.
Limitación Crítica: Su enfoque es
puramente atmosférico; no incluye
por defecto los sensores
fisicoquímicos necesarios para
analizar el agua captada.

# TECNOLOGIA EXISTENTE EN EL AMBITO PATENTES

# Atrapanieblas multifuncional autosustentable para un riego uniforme

# Cobweb-like mist-catching water drinking device:

# Water quality monitoring and control system

# FACTORES COMUNES EN EL ESTADO DEL ARTE

# TESIS UNIVERSIDAD NACIONAL AGRARIA LA MOLINA


# Fundamento Técnico: Identifica factores críticos para la eficiencia (viento, densidad de niebla y

diseño estructural).

# Validación: Confirma que es una solución de bajo costo y alta

viabilidad para zonas rurales.

# Evolución del Proyecto: El estudio sirve de base para transformar el modelo convencional en uno inteligente, integrando IoT para el monitoreo automatizado de variables climáticas y volumen de

agua en tiempo real.

# Factor Crítico: El rendimiento depende directamente del tipo de malla (destacando la malla Raschel)

y del diseño estructural del colector.

# Resultados: Confirma que es una tecnología de bajo impacto ambiental y alta viabilidad en climas

con neblina.

# Aporte al Proyecto: Proporciona los parámetros técnicos para optimizar la captación física, permitiendo que la integración de sensores e IoT maximice el volumen recolectado

según el entorno.


# Revisión de sistemas

atrapanieblas.

# TESIS UNIVERSIDAD RICARDO

PALMA .


# LISTA DE EXIGENCIAS

Edición: 1.0; Revisado:; CLIENTE:; Elaborado:; Fecha; DESCRIPCIÓN; RESPONSABLE

PROYECTO: | YAKUYURA: | Fecha: 29/04/2026

Los profesores del curso de Fundamentos de Diseño:

MARCO ANTONIO MUGABURU CELI

JOSE LUIZ DA SILVA.

DOMINGO VLADIMIR FLORES ROBLES ALBERTO

VICTOR ALBERTO HUANAMBAL SOVERO

JHOMER RODRIGO CONTRERAS PAUCCA

1. Rodriguez Zavaleta, Valeria Nicole
2. Perez Salvatierra, María Fernanda
3. Canchari de la Cruz, Ayme
4. Mamani Tello, Jose Antonio
5. Espinola Abanto, Rosita Dayana

HARRY ANDERSON RIVERA TITO

RENZO JOSE CHAN RIOS

JULISSA ELVIRA VENANCIO HUERTA

DIANA SHEYLA SANDOVAL EUSTAQUIO

CRISTHIAN GUSTAVO JACINTO CALDERON

(cambios)

28/04/2026 | E

FUNCIÓN PRINCIPAL:

Captar agua de niebla y evaluar su calidad mediante la medición de pH, conductividad y turbidez para su uso en riego, aplicando métodos estandarizados (ISO 7027-1, ISO 10523, ISO 7888)(1) (https://www.zotero.org/google-docs/?DSFb8U)(2) (https://www.zotero.org/google-docs/?PmxobH) (3)considerando (https://www.zotero.org/google-docs/?kOAhaM) los Estándares de Calidad Ambiental para Agua (DS N° 004-2017-MINAM) (4)y (https://www.zotero.org/google-docs/?CdiYSG) criterios de uso agrícola de la FAO (2017)(5), (https://www.zotero.org/google-docs/?Za9Sbp) así como la influencia de contaminantes atmosféricos en la composición del agua (OMS, 2023)(6). (https://www.zotero.org/google-docs/?TARi8P)

Todos

28/04/2026

GEOMETRÍA:

E

El sistema deberá contar con una estructura de captación con altura entre 0.5m, área mínima de 0.2 m² e inclinación entre 20° y 45°, permitiendo la recolección eficiente del agua y su conducción hacia un sistema de almacenamiento de 10 a 15L.

Ayme

D

Se busca mejorar la eficiencia de captación mediante diseños optimizados sin incrementar significativamente el costo del sistema.

Valeria

FUERZAS:

La estructura deberá resistir condiciones ambientales, incluyendo viento ≥ 5 m/s y

28/04/2026 | E | Maria Fernanda

cargas entre 25 y 50 kg, establecidos como criterios de diseño del sistema, considerando la variabilidad climática y condiciones atmosféricas del entorno (NOAA, 2022; Evaluación de necesidades tecnológicas para el cambio climático en el Perú)(7). (https://www.zotero.org/google-docs/?VdbmG5) Asimismo, deberá contar con protección mínima IP ≥ 24 contra humedad y polvo (IEC 60529), garantizando su durabilidad frente a la presencia de contaminantes atmosféricos (OMS, 2023) (6).

28/04/2026 | | MATERIA:
| E | La niebla y la humedad más el flujo de viento se convierte en agua a través del sistema | Valeria
28/04/2026 | | ENERGÍA: | Dayana
| E | Conexión eléctrica por cable
| D | Baterías de Litio (12V 10Ah) para alimentar el sistema con una autonomía de aproximadamente 3 dias solo para monitoreo
| D | Sistema de energía: panel solar además de incluir baterías de respaldo
| | SEÑALES:
| | Entradas:
| | ENERGÍA
| E | Energía eléctrica
| | SEÑALES

28/04/2026 | TODOS
| Señal de control ON/OFF
E | Señal del sensor de pH
E | Señal del sensor de turbidez
E | Variables ambientales (humedad, temperatura, presión, etc.)
E | Señal de nivel de tanque
| Salidas:
| ENERGÍA
E | Calor disipado del sistema
| SEÑALES
| Estado del sistema (encendido/apagado)
E | Señal del volumen disponible en el tanque
E | Visualización y registro de calidad del agua y aire
E | Alertas de operación o mantenimiento
E | Recomendaciones para toma de decisiones
| | CONTROL:

El sistema de captación y monitoreo de

28/04/2026 | TODOS

E

niebla debe operar de manera estable y continua en todas sus etapas, desde la recolección de agua mediante mallas captadoras hasta el almacenamiento y análisis de calidad. Se debe garantizar el control del flujo de agua recolectada, así como la correcta adquisición de datos ambientales mediante sensores (temperatura, humedad, presión y calidad del aire). Asimismo, el sistema debe asegurar que la secuencia de operación (captación, filtración, almacenamiento, medición y visualización de datos) se ejecute en el orden correcto y sin interrupciones. Además, el sistema debe ser capaz de reiniciar automáticamente o manualmente sus operaciones ante fallas o variaciones en las condiciones ambientales, sin comprometer la integridad de los datos ni el
funcionamiento del dispositivo.

28/04/2026

| ELECTRONICA (Hardware)
E | El sistema debe permitir la adquisición de datos de variables ambientales y de nivel de agua mediante dispositivos de medición. | Dayana
E | El sistema debe contar con una unidad de procesamiento capaz de interpretar la información obtenida y gestionar la activación de alertas. | Jose
E | Se deben incorporar elementos de salida para la notificación de eventos críticos, considerando protección frente a condiciones ambientales como la humedad. | Dayana
| SOFTWARE:

28/04/2026

El sistema debe procesar la información
obtenida, generando alertas en función de
límites previamente establecidos, así como | Dayana

permitir el registro y acceso remoto a los datos.

28/04/2026

| | COMUNICACIONES:
| E | El sistema debe permitir la transmisión de datos hacia una plataforma remota, facilitando el monitoreo en tiempo real y la generación de alertas ante condiciones críticas. | Ayme
| E | SEGURIDAD: El sistema debe operar con niveles de voltaje seguros y garantizar la protección de la información durante su transmisión, asegurando confidencialidad, integridad y disponibilidad conforme a estándares ISO (8). (https://www.zotero.org/google-docs/?CAAXnD) | Valeria
28/04/2026 | E | ERGONOMÍA: El sistema debe presentar un diseño compacto y de fácil operación, permitiendo una interacción sencilla y un mantenimiento accesible para el usuario en condiciones reales de uso(9). (https://www.zotero.org/google-docs/?ovqdZg) | Valeria
| | FABRICACIÓN:
| | La fabricación del sistema debe incluir un nodo de monitoreo ambiental compuesto por un microcontrolador y sensores , integrados en una sola unidad. Este nodo debe estar protegido frente a humedad, garantizando su durabilidad, en concordancia con la Ley N° 28611 – Ley General del Ambiente. Asimismo, debe permitir la salida de calor, contar con protección contra el ingreso de agua (sellado tipo IP) y facilitar el mantenimiento.
| | CONTROL DE CALIDAD:
28/04/2026 | E

TODOS

28/04/2026

E | El sistema debe evaluar la calidad del agua recolectada según el D.S. N° 004-2017-MINAM (Categoría 3 – D1), asegurando un pH entre 6.5 y 8.5 y considerando la conductividad como indicador de salinidad (4). La medición de pH, conductividad y turbidez deben seguir normas ISO 10523, ISO 7888 e ISO 7027-1, con sensores calibrados(1-3). Además, se debe considerar el impacto de la calidad del aire, según lineamientos de la OMS (2023) (6). | Maria Fernanda
28/04/2026 | | MONTAJE:
| E | El sistema debe instalarse de forma fija y segura, garantizando estabilidad ante viento y humedad, para evitar desplazamientos o fallas. La malla debe orientarse al viento predominante para maximizar la captación, y el tanque colocarse sobre una base firme y protegida para prevenir fugas y contaminación. La instalación eléctrica debe contar con conexiones seguras y protección adecuada. | Jose
28/04/2026 | | TRANSPORTE:
| E | El sistema debe ser modular para facilitar su transporte e instalación en diversas zonas, asegurando adaptabilidad. Sus componentes deben desmontarse sin afectar su funcionamiento y protegerse durante el traslado frente a golpes, vibraciones y condiciones adversas.El prototipo debe tener un peso aproximado entre 10 y 25 kg en vacío, permitiendo su transporte manual. | Valeria
| USO:
E | El sistema operará bajo condiciones ambientales de alta humedad (70% - 90%) y presencia de neblina persistente en VMT. | Ayme

28/04/2026

Para la captación hídrica se utilizará malla Raschel, la cual debe resistir vientos moderados y la exposición a la intemperie

Mafer

El monitoreo se realizará mediante un microcontrolador ESP32 conectado a sensores para identificar cuándo las condiciones climáticas son óptimas para la captación, además sobre la calidad del agua obtenida. | Dayana
E | MANTENIMIENTO:
| Componentes físicos:Limpieza mensual de la malla atrapanieblas para eliminar acumulación de material particulado (PM2.5/PM10) y polvo | Valeria

28/04/2026

E | Componentes electrónicos: Se debe revisar trimestralmente que los cables no tengan sarro o humedad. Los sensores de pH y nivel se deben limpiar para evitar que el agua estancada dé lecturas falsas. | Dayana
| | COSTOS: | TODOS
28/04/2026 | E

Basado en las horas de trabajo en clase (80
hrs de clase) y 60 hrs de trabajo externo. A S/ 40/hr, el costo de diseño es S/ 5600. Los materiales se mantienen en un presupuesto máximo de S/ 500

PLAZOS:

28/04/2026 | E | TODOS

El proyecto se desarrolla durante el periodo académico 2026-1 (16/03 al 09/07). Se han establecido los siguientes hitos de evaluación:

- 7 de mayo: Entrega del Avance 1 (Parcial), presentación de la investigación base, selección final de componentes, pitch del proyecto.
- 2 de julio: Entrega del Avance 2 y sustentación final del prototipo funcional e informe de resultado

# CAJA NEGRA


# SECUENCIA DE OPERACIONES:


# NIVEL USUARIO

# SECUENCIA DE OPERACIONES:


# NIVEL DISPOSITIVO

# ESTRUCTURA DE FUNCIONES:


# DOMINIO ENERGÍA

# DOMINIO DE SOFTWARE

# DOMINIO ELECTRÓNICO

# DOMINIO MECÁNICO

# DOMINIO CONTROL

# En este sistema se consideran

sensores de calidad de agua,

# temperatura y humedad, así como calidad del aire, estas señales son enviadas al dominio de control para su

procesamiento.

# Este dominio incluye las funciones de captación de

niebla, condensación,

# conducción y almacenamiento del agua recolectada. El resultado de este proceso es la

obtención de agua no potable,

# Incluye la recepción de energía

eléctrica, su regulación,

# almacenamiento (mediante baterías) y acondicionamiento para su distribución a los

distintos componentes.

# Recibe la información proveniente de los sensores y procesa los datos correspondientes a las variables medidas. A partir de este procesamiento, se genera información

relevante sobre la calidad del aire,

# condiciones ambientales y calidad del

agua.

# Recibe los datos procesados desde el dominio de control, los almacena, analiza

y genera salidas útiles para el usuario. Entre estas salidas se incluyen alertas, recomendaciones y visualización de datos.

# Este dominio permite transformar los datos en información útil para la toma de

decisiones.

# ESTRUCTURA DE FUNCIONES INTEGRADAS


# MATRIZ MORFOLOGICA

# DOMINIO ELECTRONICO

# Selección: Alternativa 01

# Monitoreo Atmosférico (BME280 + NDIR): BME280: Integra presión, temperatura y humedad en un

solo componente digital, optimizando el hardware (ESP).

# Sensor NDIR: Medición de gases con mayor vida útil y

estabilidad térmica que los sensores comunes.

# Análisis de Calidad de Agua (pH, Turbidez, TDS): Incluye etapas de amplificación para estabilizar señales

débiles y eliminar ruido, asegurando datos fiables.

# Objetivo Crítico: Correlacionar la calidad del aire con la

pureza del agua recolectada.

# Gestión de Almacenamiento (Ultrasónico): Control de nivel sin contacto para evitar corrosión de

componentes y facilitar el mantenimiento del tanque.

# Conclusión: Un ecosistema sensorial robusto que garantiza la precisión necesaria para validar el sistema como fuente de

agua segura.

# DOMINIO MECÁNICO

# Selección: Alternativa 01


Eficiencia de Captación: Uso de malla
Raschel maximizando la superficie de
condensación y el rendimiento hídrico.

Materiales Estratégicos:
Canaleta de PVC: Ligera, anticorrosiva y
de bajo mantenimiento.
Tanque plástico: Alta resistencia
estructural y durabilidad a la intemperie.

Ventaja Competitiva: Supera a la malla
metálica en capacidad de condensación

Conclusión: Equilibrio óptimo entre
eficiencia de recolección, peso y robustez.

# DOMINIO ENERGÍA


Selección: Alternativa 02 (Energía
Fotovoltaica)
Motivo Principal: Garantiza autonomía total
y sostenibilidad, ideal para zonas alejadas
de la red eléctrica.
Ventaja Competitiva: A diferencia de las
otras opciones, elimina la dependencia de
alimentación externa constante.
Componentes: Integración de paneles
solares, controlador de carga y
almacenamiento (baterías), asegurando un
suministro estable, seguro y protegido.
Conclusión: Es la opción que mejor
equilibra independencia operativa y
viabilidad técnica

# DOMINIO CONTROL

# Selección: Alternativa 01


Cerebro del Sistema: Uso de un microcontrolador
por su equilibrio óptimo entre procesamiento,
bajo costo y eficiencia energética.
Integración Sensorial: Capacidad nativa para
gestionar sensores de calidad de aire,
temperatura, humedad y calidad del agua en una
sola plataforma.
Ventaja Competitiva:
Sobre Alt. 02: Menor consumo de energía,
crítico para la alimentación solar.
Sobre Alt. 03: Mayor estabilidad y robustez
para una implementación definitiva (no solo
prototipo).
Conclusión: Solución confiable, compacta y de fácil
programación, ideal para sistemas autónomos de
monitoreo remoto.

# DOMINIO DE SOFTWARE

# Selección: Alternativa 03 (Dominio de Software)

# Conectividad y Alcance: Comunicación inalámbrica que elimina el cableado y permite la transmisión

de datos en tiempo real desde los sensores.

# Gestión de Datos: Uso de base de datos en la nube, garantizando accesibilidad remota total y escalabilidad, superando las limitaciones del

almacenamiento local.

# Interfaz y Control: Integración de una aplicación móvil y reglas lógicas para una supervisión moderna y eficiente (superior al uso de pantallas

LCD básicas).

# Conclusión: Una solución IoT robusta que equilibra conectividad, acceso global y

funcionalidad avanzada para el usuario final.


# BOCETOS CONCEPTOS DE SOLUCIÓN

# BOCETOS CONCEPTOS DE SOLUCIÓN

# BOCETO CONCEPTO DE SOLUCIÓN 1


# BOCETO CONCEPTO DE SOLUCIÓN 2


# EVALUACIÓN MATRIZ DE PUGH

# MATRIZ DE PUGH


# SELECCION DE SOLUCIÓN:


# RESILIENCIA AMBIENTAL:

# EQUILIBRIO TECNICO

# SINERGIA DE SUBSISTEMAS

# SOSTENIBILIDAD Y MANTENIMIENTO:

# Tras el análisis comparativo mediante la matriz de Pugh, se ha seleccionado la Solución 1

# Presenta una compatibilidad óptima entre los componentes mecánicos, electrónicos y el

software de control,

# garantizando un

funcionamiento fluido.

# uso de componentes accesibles y de bajo consumo simplifica las labores de mantenimiento y reduce los costos operativos a largo

plazo.

# Ofrece una alta durabilidad frente a condiciones climáticas adversas, asegurando la integridad del sistema en exteriores

# Logra una integración superior entre la eficiencia de captación

y el consumo energético,

# superando a la Solución 2 y 3 en estabilidad operativa

Fradel and Spies | Home | Services | Project | Contact | End Slide


YAKUYURA:
del agua a la
vida

# BIBLIOGRAFÍA:

# ISO 7027 [Internet]. [citado 26 de abril de 2026]. Disponible en: https://www.iso.org/obp/ui/#iso:std:iso:7027:-1:ed-1:v1:en

ISO 10523 [Internet]. [citado 26 de abril de 2026].

# Disponible en: https://www.iso.org/obp/ui/#iso:std:iso:10523:ed-2:v1:en ISO 7888 [Internet]. [citado 26 de abril de 2026]. Disponible en: https://www.iso.org/obp/ui/#iso:std:iso:7888:ed-1:v1:en

DS-004-2017-MINAM-4.

# FAO [Internet]. [citado 26 de abril de 2026]. Disponible en: https://www.fao.org/home/en/ OMS 2023 [Internet]. [citado 26 de abril de 2026]. Disponible en: https://www.who.int/es/news-room/fact-sheets/detail/ambient-%28outdoor%29-air-quality-and-health

Fillingham J, Harrington A, Deehan M, Renta I, Gugliotti E, Matlock G, et al. 2022 NOAA Science Report.

# ISO 27001 [Internet]. [citado 29 de abril de 2026]. Disponible en: https://www.iso.org/isoiec-27001-information-security.html

52075.html [Internet]. [citado 29 de abril de 2026].

# Disponible en: https://www.iso.org/standard/52075.html

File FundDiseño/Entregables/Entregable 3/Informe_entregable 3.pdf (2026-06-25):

### UNIVERSIDAD PERUANA CAYETANO HEREDIA


FACULTAD DE CIENCIAS E INGENIERÍA INFORME TÉCNICO DEL PROYECTO

### INFORME TÉCNICO DEL PROYECTO: ENTREGABLE 2 “De la escasez al aprovechamiento: diseño de sistema inteligente para la captación de agua de niebla en zonas urbanas con limitado acceso hídrico “

INTEGRANTES:
(aportación al informe —> %) Canchari de la Cruz, Ayme (85%) Espinola Abanto, Rosita Dayana (95%) Mamani Tello, José Antonio (100%) Pérez Salvatierra, María Fernanda ( 95%) Rodriguez Zavaleta, Valeria Nicole (100%)

ASESORES:
Da Silva, José Luis
Flores Robles, Domingo
Mugaburu Celi, Marco
Venancio Huerta, Julissa

Lima-Perú
2026

Universidad Peruana Cayetano Heredia Facultad de Ciencias e Ingeniería Fundamentos de Diseño

ÍNDICE

### 1. Introducción | 2 2. Problemática | 3 3. Estado de latecnología | 5

3.1. Tecnología existente en el ámbito comercial | 5
3.2. Tecnología existente en el ámbito de patentes | 7
3.3. Factores comunes en el estado del arte | 12
3.3.1. Artículos científicos | 12
3.3.2. Tesis de repositorios | 14

### 4. Lista de exigencias | 15

4.1. Plan de trabajo | 16

### 5. Estructura de Funciones | 20

5.1. Caja Negra (Black Box) | 20
5.2. Secuencia de Operaciones | 21
5.3. Estructura de Funciones (Caja Blanca) | 22
5.4. Estructura de Funciones Integradas | 22

### 6. Concepto de solución por Dominio | 23

6.1. Matriz morfológica del dominio electrónico | 23
6.1.1. Disposición básica de soluciones del dominio electrónico | 25
6.1.2. Evaluación de conceptos y selección del concepto óptimo | 28
6.2. Matriz morfológica del dominio mecánico | 30
6.2.1. Disposición básica de soluciones del dominio mecánico | 31
6.2.2. Evaluación de conceptos y selección del concepto óptimo | 34
6.3. Matriz morfológica del dominio energía | 35
6.3.1. Disposición básica de soluciones del dominio energía | 37
6.3.2. Evaluación de conceptos y selección del concepto óptimo | 39
6.4. Matriz morfológica del dominio control | 40
6.4.1. Disposición básica de soluciones del dominio control | 41
6.4.2. Evaluación de conceptos y selección del concepto óptimo | 42
6.5. Matriz morfológica del dominio software | 42
6.5.1. Disposición básica de soluciones del dominio software | 46
6.5.2. Evaluación de conceptos y selección del concepto óptimo | 20

### 7. Bocetos de los 3 conceptos de solución | 45

7.1. Boceto del Concepto de solución 1 | 45
7.2. Boceto del Concepto de solución 2 | 46
7.3. Boceto del Concepto de solución 3 | 47

### 8. Evaluación de Matriz de Pugh | 51

8.1. Selección y explicación de los criterios técnico/económicos | 51
8.2. Justificación de asignación de puntajes | 51
8.2.1. Concepto de Solución 1 | 52
8.2.2. Concepto de Solución 2 | 53
8.2.3. Concepto de Solución 3 | 54
8.3. Concepto de Solución Óptimo | 54

### 9. Referencias Bibliográficas | 57

### 1 Introducción

El agua constituye un recurso esencial para la vida, el desarrollo humano y el funcionamiento sostenible de las ciudades. Sin embargo, el incremento de la población, el crecimiento urbano desordenado y los efectos del cambio climático han generado una presión cada vez mayor sobre las fuentes tradicionales de abastecimiento hídrico (1). (https://www.zotero.org/google-docs/?vU9lnB) A nivel mundial, organismos internacionales advierten que la disponibilidad de agua dulce disminuye progresivamente, mientras que la demanda continúa aumentando, situación que afecta principalmente a las poblaciones más vulnerables (2). (https://www.zotero.org/google-docs/?FGIDN5)

En el Perú, las dificultades relacionadas con el acceso al agua potable representan una problemática persistente, especialmente en sectores urbano-marginales donde la infraestructura de distribución resulta insuficiente (3). (https://www.zotero.org/google-docs/?VNYWvG) En Lima Metropolitana, diversos asentamientos humanos ubicados en zonas periféricas presentan limitaciones en el suministro continuo de agua, obligando a miles de familias a depender de sistemas alternativos de abastecimiento, como los camiones cisterna, los cuales implican mayores costos y menores garantías de calidad sanitaria (4). (https://www.zotero.org/google-docs/?Jy8Ntx)

Frente a este escenario, surge la necesidad de explorar fuentes hídricas no convencionales que permitan complementar el abastecimiento tradicional. Entre ellas, la captación de agua de niebla representa una alternativa sostenible y viable para zonas costeras con altos niveles de humedad atmosférica, como ocurre en diversos sectores de Lima Sur (5). (https://www.zotero.org/google-docs/?n6pNpG) Esta tecnología aprovecha la condensación de microgotas presentes en la neblina mediante estructuras de captación, permitiendo recolectar agua para diferentes usos (6). (https://www.zotero.org/google-docs/?d5WKZc)

No obstante, aunque los sistemas atrapanieblas han demostrado resultados favorables en determinados contextos, la mayoría de propuestas existentes se enfocan únicamente en la captación del recurso, sin incorporar mecanismos de monitoreo en tiempo real que permitan evaluar las condiciones ambientales y la calidad fisicoquímica del agua obtenida (7). (https://www.zotero.org/google-docs/?hA7VJN) Esta limitación dificulta garantizar un aprovechamiento seguro y eficiente del recurso recolectado (8). (https://www.zotero.org/google-docs/?sSd0lJ)

En este contexto, el desarrollo de tecnologías basadas en Internet de las Cosas (IoT) ofrece nuevas posibilidades para optimizar la gestión de recursos hídricos alternativos. La integración de sensores ambientales, sistemas de monitoreo remoto y plataformas de transmisión de datos permite supervisar continuamente variables climáticas y parámetros de calidad del agua, facilitando la toma de decisiones y mejorando la eficiencia de los sistemas de captación (9) (https://www.zotero.org/google-docs/?YxX7Bt) .

Por ello, la presente investigación propone el diseño e implementación de un sistema inteligente de captación de agua de niebla basado en tecnología IoT, orientado al monitoreo de variables climáticas y características fisicoquímicas del agua recolectada en zonas urbanas de Villa María del Triunfo. La propuesta busca contribuir al desarrollo de soluciones sostenibles frente a la problemática hídrica, promoviendo el aprovechamiento de recursos atmosféricos mediante herramientas tecnológicas adaptadas a contextos urbanos vulnerables.

### 2 Problemática

### 2.1 Contexto general

El acceso al agua constituye uno de los principales desafíos a nivel global, debido a su estrecha relación con la salud, el desarrollo económico y la sostenibilidad ambiental. De acuerdo con la Organización de las Naciones Unidas, la creciente presión sobre los recursos hídricos está asociada tanto al cambio climático como al acelerado crecimiento urbano, factores que modifican los patrones de precipitación y reducen la disponibilidad de agua dulce(1). (https://www.zotero.org/google-docs/?p4XK0D) En este contexto, diversos estudios señalan que la escasez hídrica no responde únicamente a limitaciones físicas del recurso, sino también a deficiencias en su gestión, distribución e infraestructura (2). (https://www.zotero.org/google-docs/?D7YdGO)

En el Perú, esta problemática se manifiesta de manera significativa, ya que solo el 49,4 % de la población cuenta con acceso a agua potable gestionada de forma segura (INEI, 2022) (3). (https://www.zotero.org/google-docs/?AOcImG) Esta situación evidencia brechas estructurales en la provisión del servicio, especialmente en zonas urbanas periféricas, donde el crecimiento poblacional supera la capacidad de la infraestructura existente. En consecuencia, la desigualdad en el acceso al agua refleja, en gran medida, un problema de gobernanza más que de disponibilidad absoluta del recurso(4). (https://www.zotero.org/google-docs/?x8B0eP)

En Lima Metropolitana, particularmente en distritos como Villa María del Triunfo, esta situación se intensifica debido a procesos de urbanización no planificada (5). (https://www.zotero.org/google-docs/?ipo24p) Como resultado, una parte importante de la población depende del abastecimiento mediante camiones cisterna, lo que implica costos entre cinco y diez veces superiores al suministro convencional(6). (https://www.zotero.org/google-docs/?OujsWa) Este escenario evidencia una marcada inequidad, donde los sectores más vulnerables acceden a agua de menor calidad a un costo significativamente mayor.

2.2 Potencial hídrico y limitaciones

Paradójicamente, estas zonas presentan condiciones ambientales favorables para la captación de agua atmosférica. Estudios climatológicos han demostrado que la costa peruana registra altos niveles de humedad relativa asociados a la presencia de neblina o garúa, lo que representa una fuente potencial de agua no convencional (7). (https://www.zotero.org/google-docs/?2omUhz) Este recurso ha sido aprovechado mediante tecnologías de captación de niebla, especialmente en regiones áridas.

No obstante, su implementación en entornos urbanos aún es limitada. Investigaciones experimentales reportan que los sistemas atrapanieblas pueden recolectar entre 3 y 10 litros por metro cuadrado al día, dependiendo de las condiciones climáticas (8). (https://www.zotero.org/google-docs/?F1aGgG) Sin embargo, la mayoría de estos estudios se desarrollan en contextos rurales o con baja contaminación atmosférica, lo que restringe su aplicabilidad en ciudades como Lima.

Un factor crítico es la calidad del aire. Según la Organización Mundial de la Salud, la presencia de material particulado fino (PM2.5 y PM10) en zonas urbanas puede afectar tanto la salud como la calidad del agua captada (9). (https://www.zotero.org/google-docs/?uSqrD3) En efecto, investigaciones recientes evidencian que las microgotas de niebla pueden incorporar contaminantes atmosféricos, modificando su composición química (10). (https://www.zotero.org/google-docs/?VhAzkL) Por ello, el desafío no radica únicamente en captar el recurso, sino en garantizar su calidad para un uso seguro.

### 2.3 Brecha Tecnológica

En este contexto, se identifica una brecha tecnológica en la integración de sistemas de captación de agua de niebla con herramientas de monitoreo ambiental en tiempo real. Si bien los sistemas tradicionales han demostrado eficacia en la captación, carecen de mecanismos que permitan evaluar variables críticas como las condiciones climáticas, la calidad del aire y las propiedades fisicoquímicas del agua recolectada (11). (https://www.zotero.org/google-docs/?WOSb2I)

Estudios realizados en las lomas de Villa María del Triunfo evidencian que el agua captada no cumple con estándares de potabilidad debido a la presencia de contaminantes; sin embargo, puede emplearse en usos no potables como el riego (7). (https://www.zotero.org/google-docs/?KpUUbV) Este hallazgo pone de manifiesto la necesidad de contar con sistemas que permitan monitorear y validar la calidad del recurso de manera continua.

En consecuencia, las soluciones actuales se enfocan principalmente en la eficiencia de captación, dejando de lado la incorporación de tecnologías inteligentes para una gestión integral del recurso. Esta limitación reduce su aplicabilidad y escalabilidad en contextos urbanos.

### 2.4 Propuesta de solución

Frente a la problemática descrita, se propone el desarrollo de un sistema inteligente de captación de agua de niebla basado en la integración de tecnologías de monitoreo ambiental y el enfoque del Internet de las Cosas (IoT). Este enfoque permite la recolección, procesamiento y análisis continuo de datos, facilitando una gestión más eficiente del recurso hídrico(12). (https://www.zotero.org/google-docs/?A0H1zm)

A diferencia de los sistemas convencionales, la propuesta adopta un enfoque integral que incorpora no solo la captación de agua, sino también la evaluación en tiempo real de las condiciones ambientales y de la calidad fisicoquímica del recurso recolectado, superando así una de las principales limitaciones identificadas en estudios previos(11). (https://www.zotero.org/google-docs/?m55Lug)

El sistema será implementado en zonas estratégicas como las lomas costeras de Villa María del Triunfo, donde la presencia de neblina es recurrente y representa una fuente alternativa

viable de agua(6). (https://www.zotero.org/google-docs/?bAINZX) En este contexto, el dispositivo permitirá identificar condiciones óptimas para la captación, optimizando su rendimiento.

Para su funcionamiento, se empleará un microcontrolador ESP32, debido a su capacidad de procesamiento y conectividad, lo que lo hace adecuado para aplicaciones IoT(13). (https://www.zotero.org/google-docs/?g4YN2P) Asimismo, se integrará el sensor BME280 para la medición de variables climáticas como temperatura, humedad relativa y presión atmosférica, parámetros clave en la formación de niebla(14). (https://www.zotero.org/google-docs/?abL8qL)
En cuanto a la calidad del agua, el sistema incorporará sensores de pH, conductividad y turbidez, permitiendo evaluar sus características conforme a normas internacionales como ISO 10523, ISO 7888 e ISO 7027-1, así como los Estándares de Calidad Ambiental para Agua establecidos en el D.S. N° 004-2017-MINAM (15). (https://www.zotero.org/google-docs/?4jDkdP) Esta evaluación es fundamental, considerando que la composición del agua de niebla puede variar en función del entorno.

Adicionalmente, se incluirán sensores de nivel para gestionar el almacenamiento del agua recolectada. Los datos serán procesados y transmitidos en tiempo real, facilitando su visualización y análisis, lo que contribuye a una toma de decisiones basada en evidencia.

De este modo, la propuesta integra captación, monitoreo ambiental y evaluación de calidad en un solo sistema, contribuyendo al desarrollo de soluciones tecnológicas sostenibles adaptadas a contextos urbanos vulnerables.

Finalmente, el proyecto se alinea con los Objetivos de Desarrollo Sostenible, en particular con el ODS 6 (agua limpia y saneamiento), el ODS 9 (industria, innovación e infraestructura) y el ODS 11 (ciudades y comunidades sostenibles), promoviendo el uso de fuentes hídricas alternativas mediante la tecnología(16) (https://www.zotero.org/google-docs/?Z0PkCj) .

### 2.5 Objetivos

### 2.5.1 Objetivo general

Diseñar e implementar un sistema inteligente basado en Internet de las Cosas (IoT) para la captación de agua de niebla y el monitoreo de sus características fisicoquímicas y condiciones climáticas en zonas urbanas de Villa María del Triunfo, con la finalidad de evaluar la disponibilidad y viabilidad de uso del recurso hídrico para aplicaciones no potables.

### 2.5.2 Objetivos específicos

- Diseñar una estructura eficiente de captación de agua de niebla adaptada a las condiciones ambientales locales, considerando parámetros de geometría, orientación y capacidad de almacenamiento.

- Implementar un sistema de monitoreo de variables climáticas (temperatura, humedad relativa y presión atmosférica) mediante el sensor BME280, para identificar condiciones óptimas de captación.
- Evaluar la calidad fisicoquímica del agua recolectada mediante la medición de pH, conductividad y turbidez, en concordancia con normas técnicas como ISO 10523, ISO 7888 e ISO 7027-1 y los estándares del D.S. N° 004-2017-MINAM.
- Integrar los sensores en una plataforma basada en el microcontrolador ESP32 para la adquisición, procesamiento y transmisión de datos en tiempo real.
- Implementar un sistema de monitoreo remoto que permita visualizar, registrar y analizar la información obtenida para la toma de decisiones.
- Analizar la relación entre las condiciones climáticas y la eficiencia de captación de agua de niebla, así como su influencia en la calidad del recurso obtenido.

### 3 Estado de la tecnología 3.1 Tecnología existente en el ámbito comercial 3.1.1 Producto Comercial 1: CloudFisher

Nombre técnico: Sistema de captación de agua atmosférica mediante mallas atrapanieblas de alta eficiencia

Enlace de consulta: https://cloudfisher.com/
Resumen técnico

CloudFisher es un sistema tecnológico orientado a la captación de agua atmosférica mediante mallas atrapanieblas de alta eficiencia. Su funcionamiento se basa en la condensación de microgotas de niebla presentes en el ambiente, permitiendo recolectar agua sin requerir elevados consumos energéticos. El sistema emplea mallas tridimensionales resistentes a condiciones climáticas adversas, facilitando su implementación en zonas áridas y costeras con alta humedad atmosférica.

La tecnología incorpora estructuras de soporte, mecanismos de canalización y almacenamiento del agua recolectada, permitiendo su aprovechamiento en actividades agrícolas y abastecimiento no potable. Asimismo, su diseño modular facilita la adaptación a diferentes condiciones ambientales y geográficas, optimizando la eficiencia de captación según la presencia de niebla y velocidad del viento(17). (https://www.zotero.org/google-docs/?U8nn1W)

Sin embargo, esta solución se enfoca principalmente en la captación del recurso hídrico, sin incorporar sistemas inteligentes de monitoreo ambiental ni evaluación fisicoquímica en tiempo real, limitando el control continuo de la calidad del agua recolectada(17). (https://www.zotero.org/google-docs/?RPJnCp)

Soluciones | Descripción | Principales características | Componentes y tecnologías utilizadas
Sistema de captación de agua de niebla Cloud Fisher | Sistema modular diseñado para recolectar agua atmosférica mediante mallas atrapanieblas de alta eficiencia en zonas con elevada humedad relativa y presencia constante de neblina. | - Captación pasiva de agua atmosférica - Uso de mallas tridimensionales de alta resistencia - Bajo consumo energético - Adaptación a zonas áridas y costeras - Sistema modular de instalación - Recolección y almacenamiento de agua | - Mallas de polipropileno de alta densidad - Estructuras metálicas de soporte - Sistema de canalización de agua - Tanques de almacenamiento - Tecnología de condensación atmosférica

Fuente: Adaptado de (17)


Figura 1: Sistema de captación de agua atmosférica CloudFisher

Fuente: Adaptado de (17)
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


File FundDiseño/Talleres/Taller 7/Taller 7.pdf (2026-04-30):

# UNIVERSIDAD PERUANA CAYETANO HEREDIA

# FACULTAD DE CIENCIAS E INGENIERÍA

TALLER 7; INTEGRANTES:; Rodriguez Zavaleta, Valeria Nicole; Perez Salvatierra, María Fernanda; Canchari de la Cruz, Ayme; Mamani Tello, Jose Antonio; Espinola Abanto, Rosita Dayana

# Proyecto de investigación interdisciplinario orientado al aprovechamiento

# sostenible de recursos hídricos atmosféricos

## PROFESORES:

## Da Silva, Jose Luis Flores Robles, Domingo Vladimir Mugaburu Celi, Marco Antonio Venancio Huerta, Julissa Elvira CURSO: Fundamentos de diseño

## Lima, Abril del 2026

## ÍNDICE:

## 1. Lista de exigencias

LISTA DE EXIGENCIAS | Pág 1 de 7

Edición: 1.0

PROYECTO: YAKUYURA: Sistema inteligente para la captación de agua de niebla

Fecha: 29/04/2026
Revisado:
CLIENTE: Los profesores del curso de Fundamentos de Diseño:
- MARCO ANTONIO MUGABURU CELI
- JOSE LUIZ DA SILVA.
- DOMINGO VLADIMIR FLORES ROBLES
| ALBERTO
- VICTOR ALBERTO HUANAMBAL SOVERO
- JHOMER RODRIGO CONTRERAS PAUCCA
- HARRY ANDERSON RIVERA TITO
- RENZO JOSE CHAN RIOS
- JULISSA ELVIRA VENANCIO HUERTA
- DIANA SHEYLA SANDOVAL EUSTAQUIO
- CRISTHIAN GUSTAVO JACINTO CALDERON
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

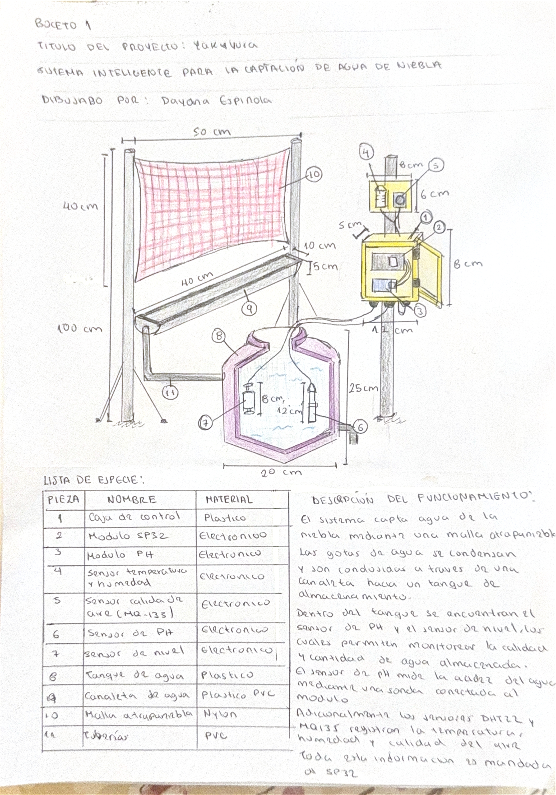
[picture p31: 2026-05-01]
FundDiseño/Talleres/Taller 7/Taller 7_bocetos/boceto1.jpg

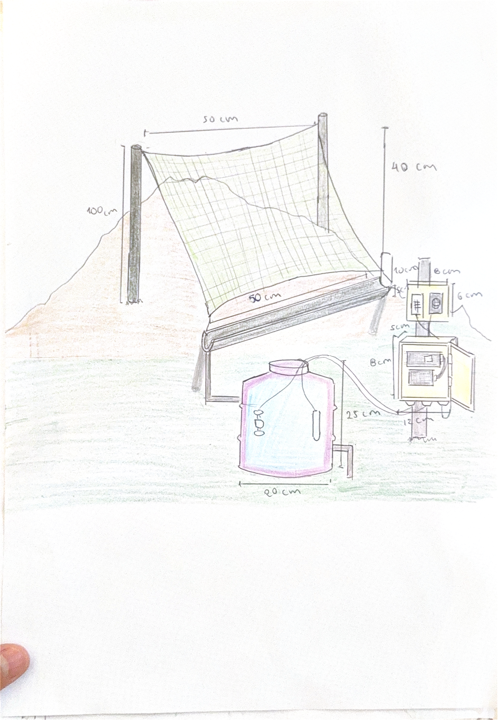
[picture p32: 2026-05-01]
FundDiseño/Talleres/Taller 7/Taller 7_bocetos/boceto2.jpg

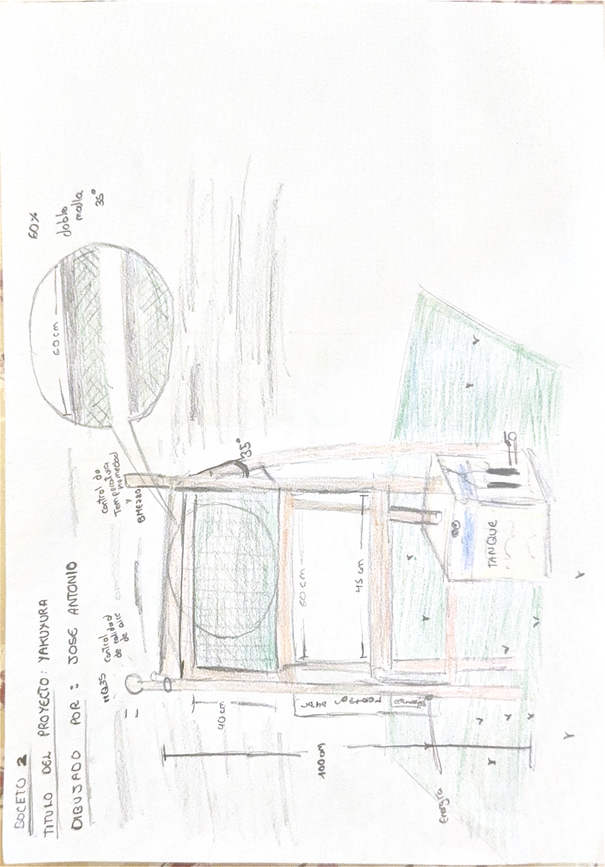
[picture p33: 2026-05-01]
FundDiseño/Talleres/Taller 7/Taller 7_bocetos/boceto3.jpg

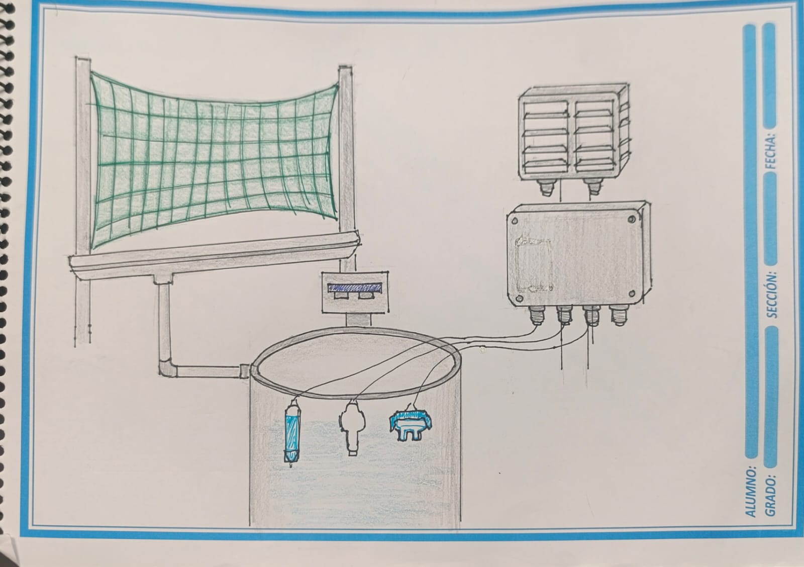
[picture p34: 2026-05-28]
Proyecto/Módulo Mecánico/version 2.0/Boceto/Boceto 2.1.jpeg

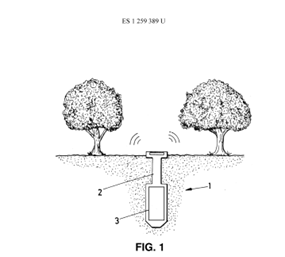
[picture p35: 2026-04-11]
Recursos/Imágenes/Imágenes/Fotos_Adicionales/PATENTE_06.png

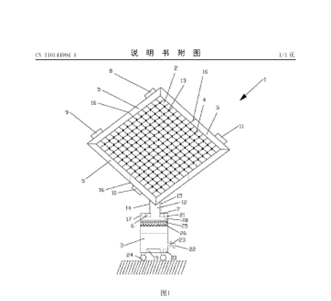
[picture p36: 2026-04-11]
Recursos/Imágenes/Imágenes/Fotos_Adicionales/PATENTE_03.png

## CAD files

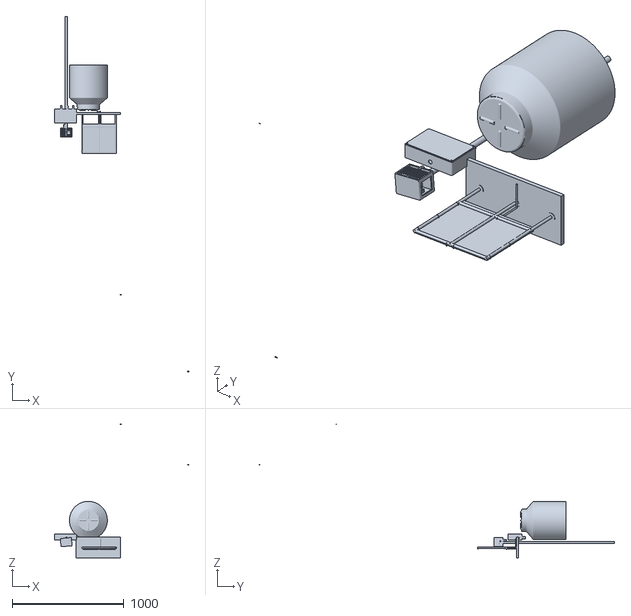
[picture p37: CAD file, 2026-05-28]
Proyecto/Módulo Mecánico/version 2.0/Onshape/Ensamble/Assembly 1.stl
1206.1 x 3183.8 x 1201.6

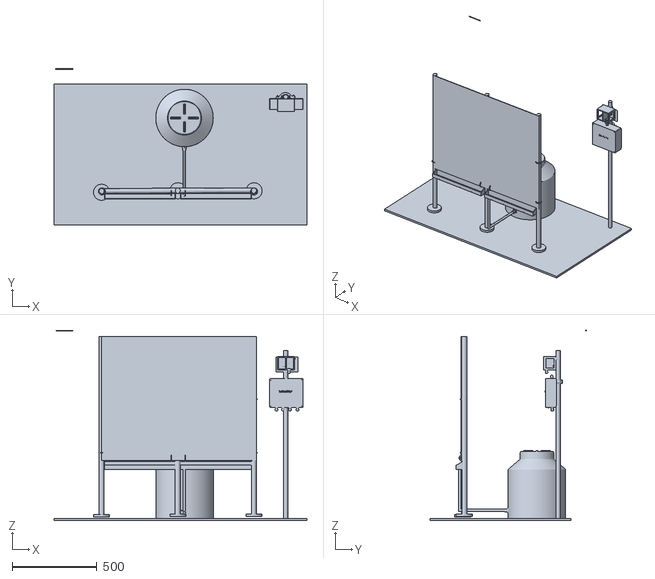
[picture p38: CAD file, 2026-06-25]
Proyecto/Módulo Mecánico/VFINAL/ONSHAPE/ENSAMBLAJE/ENSAMBLE GLOBAL.stl
1496.0 x 923.9 x 1124.7

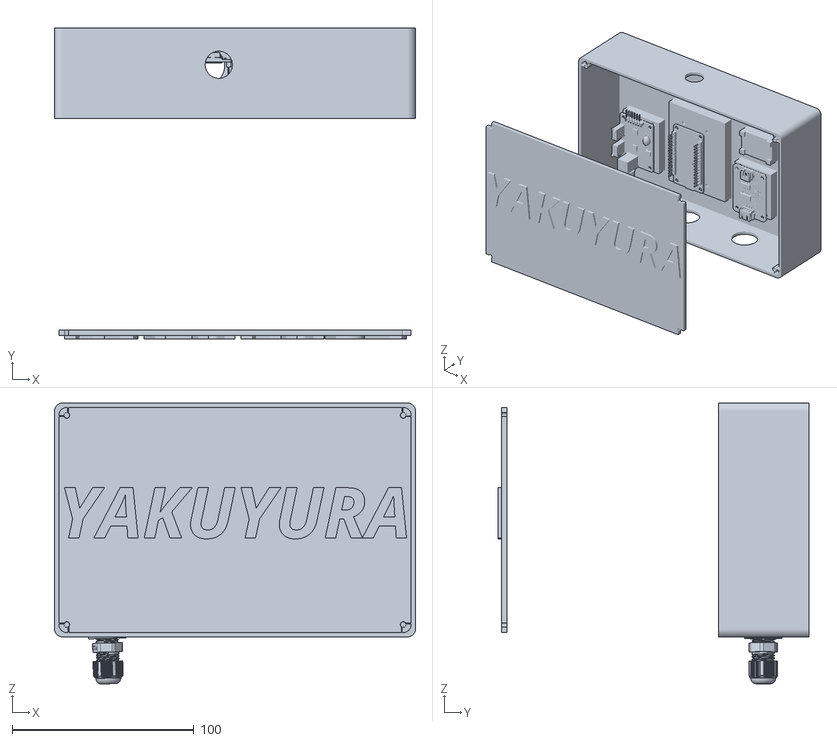
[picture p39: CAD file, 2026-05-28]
Proyecto/Módulo Mecánico/version 2.0/Onshape/Ensamble/Caja grande/Part Studio CAJA CONTROL.stl
198.8 x 171.6 x 154.7

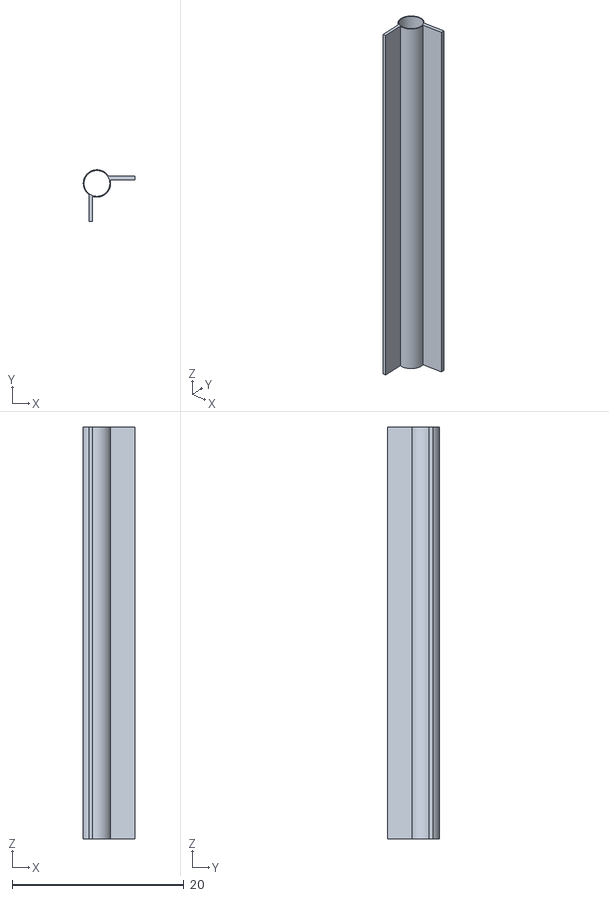
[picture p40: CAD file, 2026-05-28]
Proyecto/Módulo Mecánico/version 2.0/Onshape/Partes/Caja Grande/Parte 6 Caja Agua.stl.stl
6.01 x 6.01 x 48.0

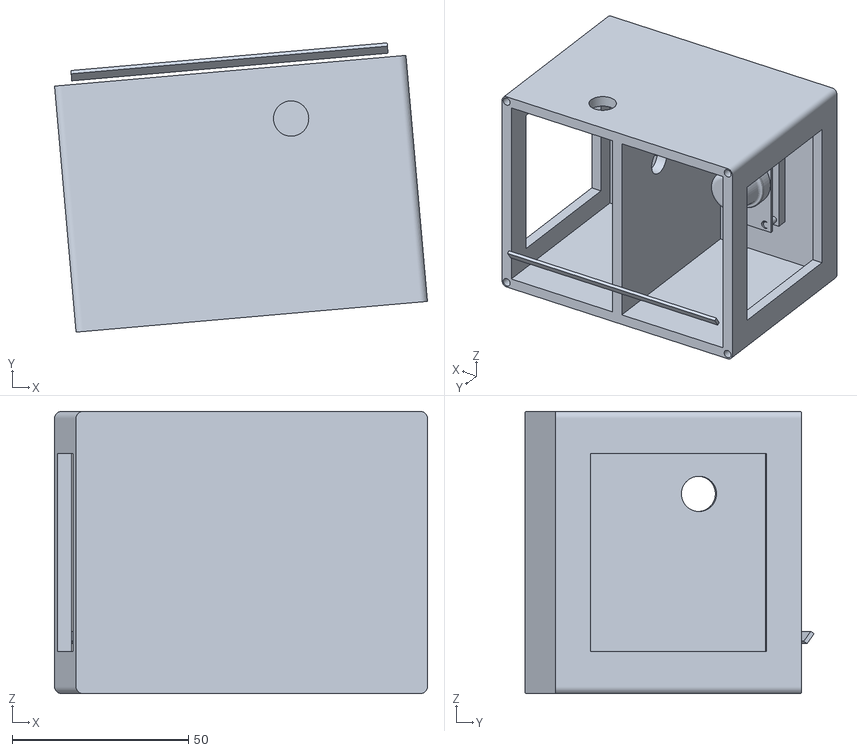
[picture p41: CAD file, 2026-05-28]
Proyecto/Módulo Mecánico/version 2.0/Onshape/Partes/Caja pequeña (aire)/Parte 1 Caja Aire (1).stl
105.7 x 82.0 x 80.0

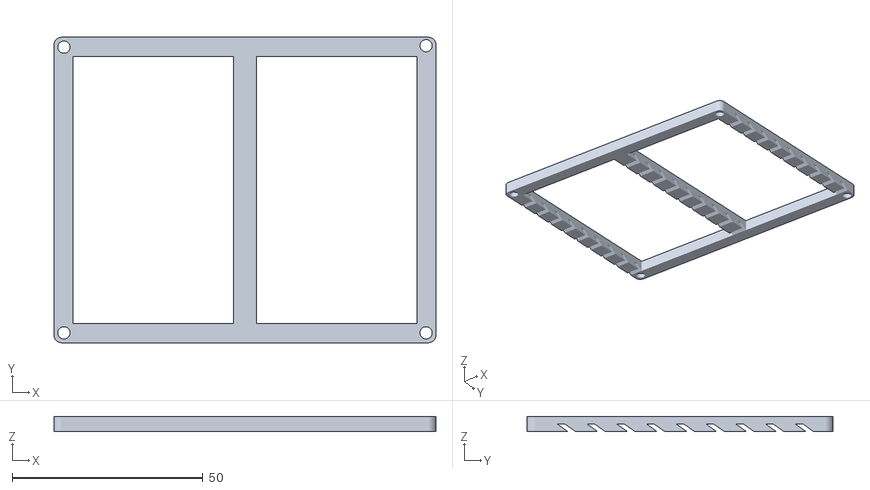
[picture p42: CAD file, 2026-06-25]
Proyecto/Módulo Mecánico/VFINAL/ONSHAPE/PARTES/Tapa_cajachica VFINAL.stl
100.0 x 80.0 x 4.00

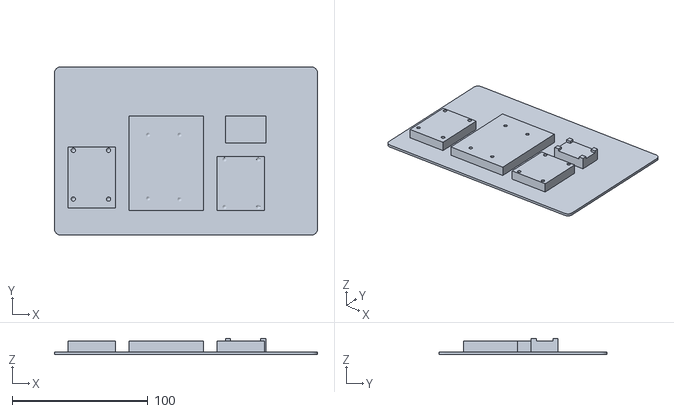
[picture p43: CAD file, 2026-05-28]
Proyecto/Módulo Mecánico/version 2.0/Onshape/Partes/Caja Grande/Parte 2 Caja Agua.stl
194.0 x 124.0 x 12.0

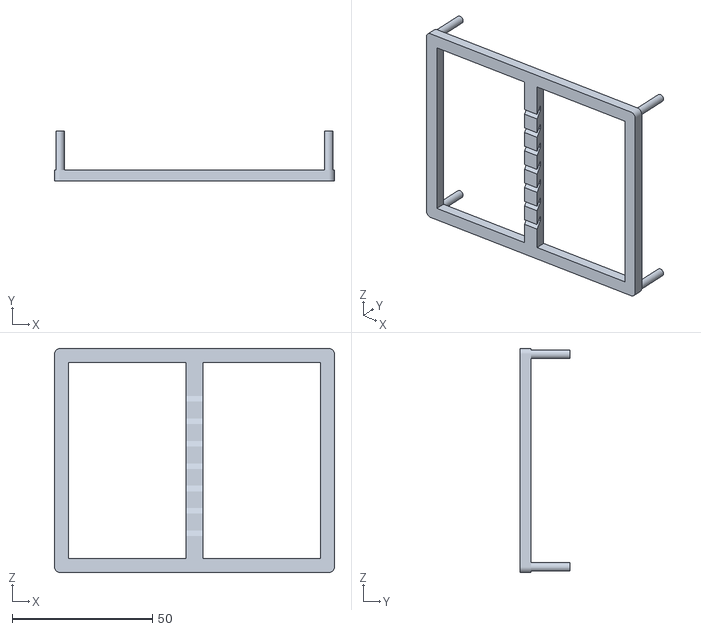
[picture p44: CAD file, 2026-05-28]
Proyecto/Módulo Mecánico/version 2.0/Onshape/Partes/Caja pequeña (aire)/Parte 2 Caja Aire.stl.stl
100.0 x 18.0 x 80.0

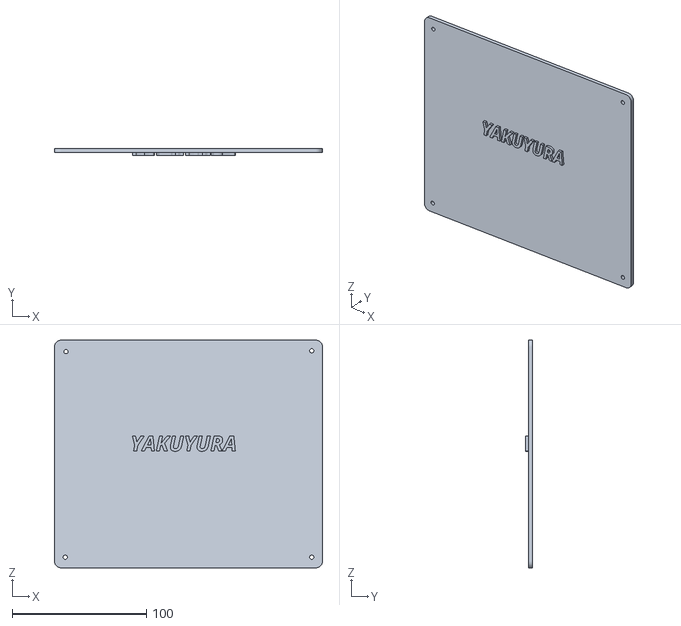
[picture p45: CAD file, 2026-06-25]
Proyecto/Módulo Mecánico/VFINAL/ONSHAPE/PARTES/Tapa caja grande VFINAL.stl
200.0 x 5.00 x 170.0

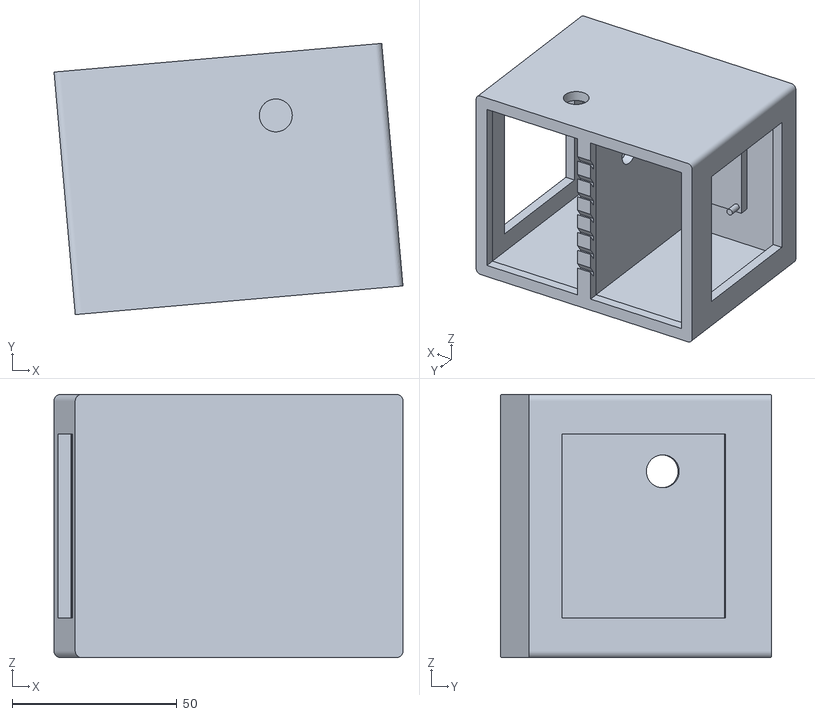
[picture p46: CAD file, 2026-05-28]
Proyecto/Módulo Mecánico/version 2.0/Onshape/Partes/Caja pequeña (aire)/Parte 3 Caja Aire.stl.stl
106.1 x 82.4 x 80.0

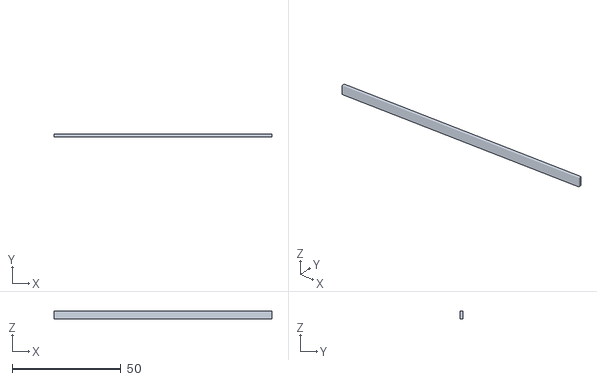
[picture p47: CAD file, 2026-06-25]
Proyecto/Módulo Mecánico/VFINAL/ONSHAPE/PARTES/Reja caja chica VFINAL.stl
100.0 x 1.16 x 3.46

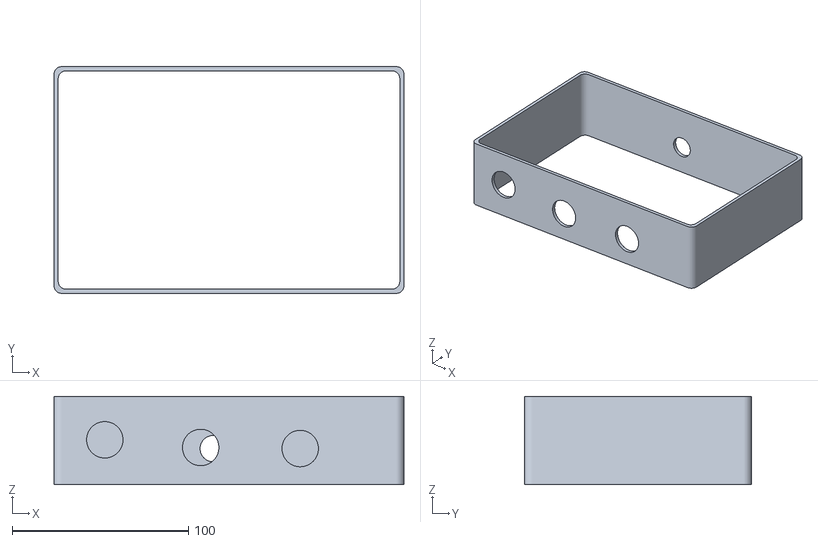
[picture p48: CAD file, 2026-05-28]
Proyecto/Módulo Mecánico/version 2.0/Onshape/Partes/Caja Grande/Parte 1 Caja Agua.stl
198.8 x 128.8 x 50.0

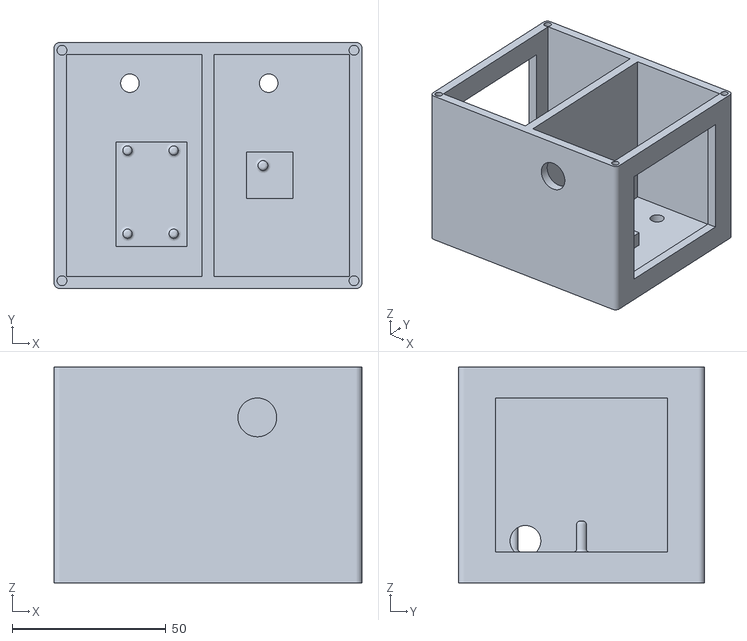
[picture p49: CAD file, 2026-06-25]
Proyecto/Módulo Mecánico/VFINAL/ONSHAPE/PARTES/Caja_senso_aire VFINAL.stl
100.0 x 80.0 x 70.0

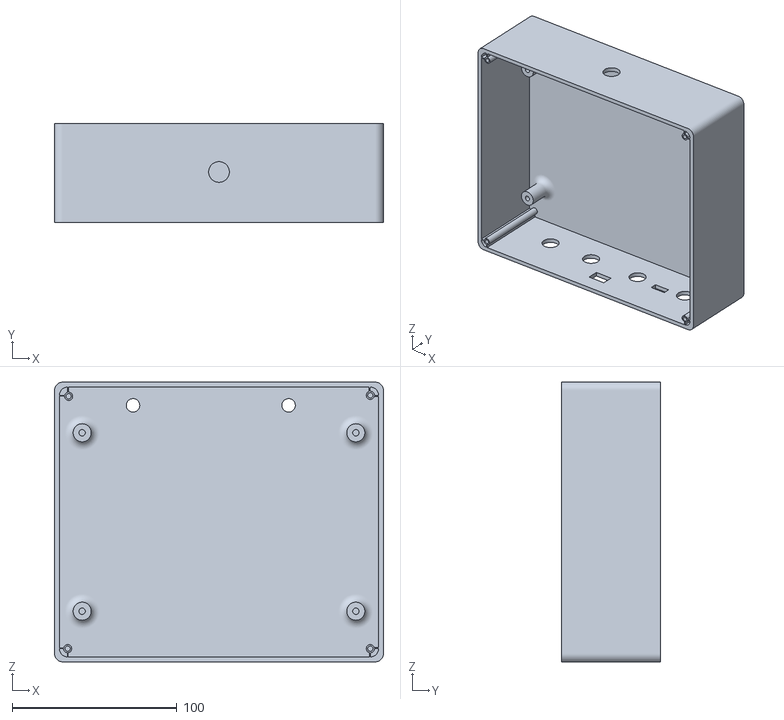
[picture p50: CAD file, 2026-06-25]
Proyecto/Módulo Mecánico/VFINAL/ONSHAPE/PARTES/Caja grande VFINAL.stl
200.0 x 60.0 x 170.0

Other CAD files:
Proyecto/Módulo Mecánico/version 2.0/Onshape/Partes/Caja Grande/Parte 5 Caja Agua.stl
Proyecto/Módulo Mecánico/version 2.0/Onshape/Partes/Caja Grande/Parte 7 Caja Agua.stl.stl
Proyecto/Módulo Mecánico/version 2.0/Onshape/Partes/Caja Grande/Parte 4.stl
Proyecto/Módulo Mecánico/version 1.0/Onshape/Partes/CAJA 1 YAKUYURA.stl
Proyecto/Módulo Mecánico/version 1.0/Onshape/Partes/CAJA 1.stl
Proyecto/Módulo Mecánico/version 1.0/Onshape/Partes/CAJA 2 YAKUYURA.stl
Proyecto/Módulo Mecánico/version 2.0/Onshape/Partes/Caja Grande/Parte 3 Caja Agua.stl

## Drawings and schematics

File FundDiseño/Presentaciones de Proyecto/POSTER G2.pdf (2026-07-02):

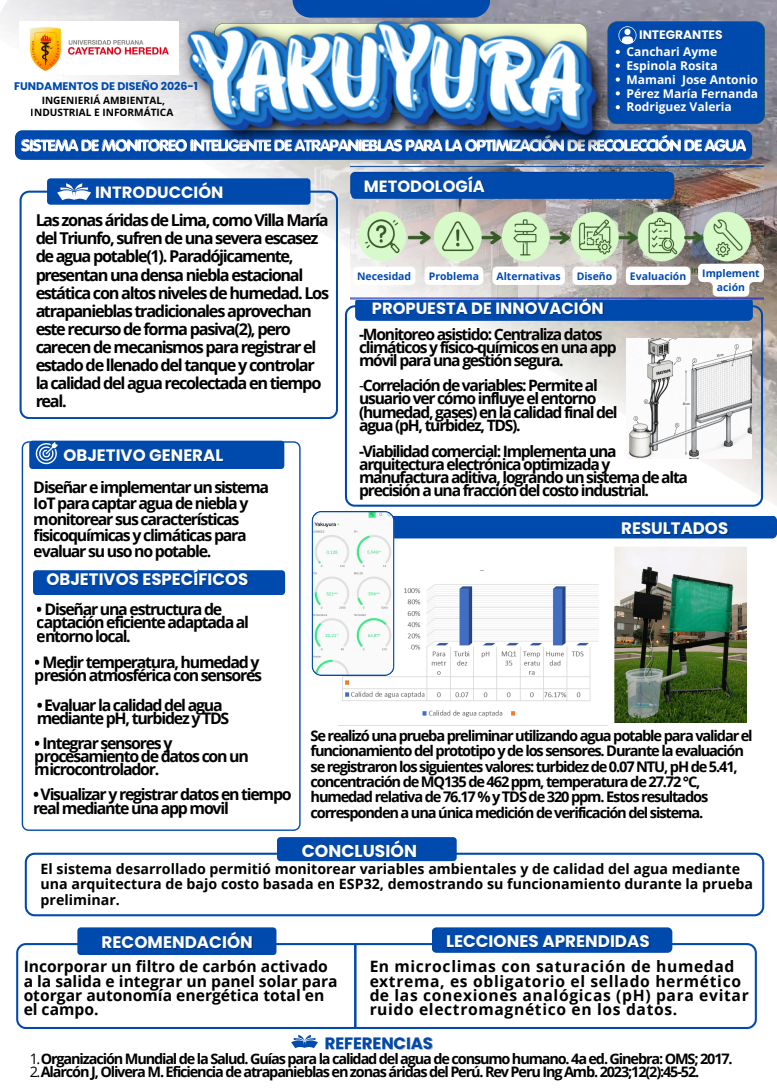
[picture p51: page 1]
SISTEMADEMONITOREOINTELIGENTEDEATRAPANIEBLASPARALAOPTIMIZACIÓNDERECOLECCIÓNDEAGUA; INTRODUCCIÓN; Diseñareimplementarunsistema IoTparacaptaraguadenieblay monitorearsuscaracterísticas fisicoquímicasyclimáticaspara evaluarsuusonopotable.; CONCLUSIÓN; OBJETIVO GENERAL; OBJETIVOS ESPECÍFICOS •Diseñarunaestructurade captacióneficienteadaptadaal entornolocal. •Medirtemperatura,humedady presiónatmosféricaconsensores; •Integrarsensoresy procesamientodedatosconun microcontrolador.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

INTEGRANTES
Canchari Ayme
Espinola Rosita
Mamani Jose Antonio
Pérez María Fernanda
Rodriguez Valeria

FUNDAMENTOS DE DISEÑO 2026-1
INGENIERIÁ AMBIENTAL,
INDUSTRIAL E INFORMÁTICA

PROPUESTA DE INNOVACIÓN
-Monitoreoasistido:Centralizadatos
climáticosyfísico-químicosenunaapp
móvilparaunagestiónsegura.
-Correlacióndevariables:Permiteal
usuariovercómoinfluyeelentorno
(humedad,gases)enlacalidadfinaldel
agua(pH,turbidez,TDS).
-Viabilidadcomercial:Implementauna
arquitecturaelectrónicaoptimizaday
manufacturaaditiva,lograndounsistemadealta
precisiónaunafraccióndelcostoindustrial.

El sistema desarrollado permitió monitorear variables ambientales y de calidad del agua mediante
una arquitectura de bajo costo basada en ESP32, demostrando su funcionamiento durante la prueba
preliminar.
RECOMENDACIÓN

Incorporar un filtro de carbón activado
a la salida e integrar un panel solar para
otorgar autonomía energética total en
el campo.

En microclimas con saturación de humedad
extrema, es obligatorio el sellado hermético
de las conexiones analógicas (pH) para evitar
ruido electromagnético en los datos.
REFERENCIAS

1.OrganizaciónMundialdelaSalud.Guíasparalacalidaddelaguadeconsumohumano.4aed.Ginebra:OMS;2017.
2.AlarcónJ,OliveraM.EficienciadeatrapanieblasenzonasáridasdelPerú.RevPeruIngAmb.2023;12(2):45-52.

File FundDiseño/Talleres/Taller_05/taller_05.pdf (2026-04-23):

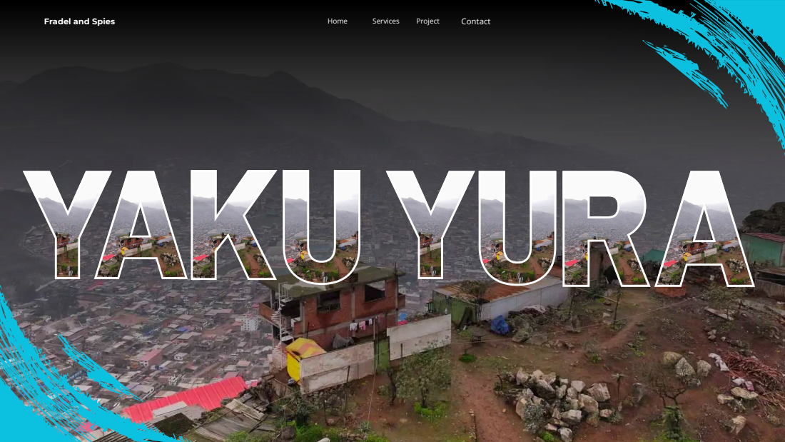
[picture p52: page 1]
Fradel and Spies; Home; Services; Project; Contact

# ¿Sabias que en Lima una

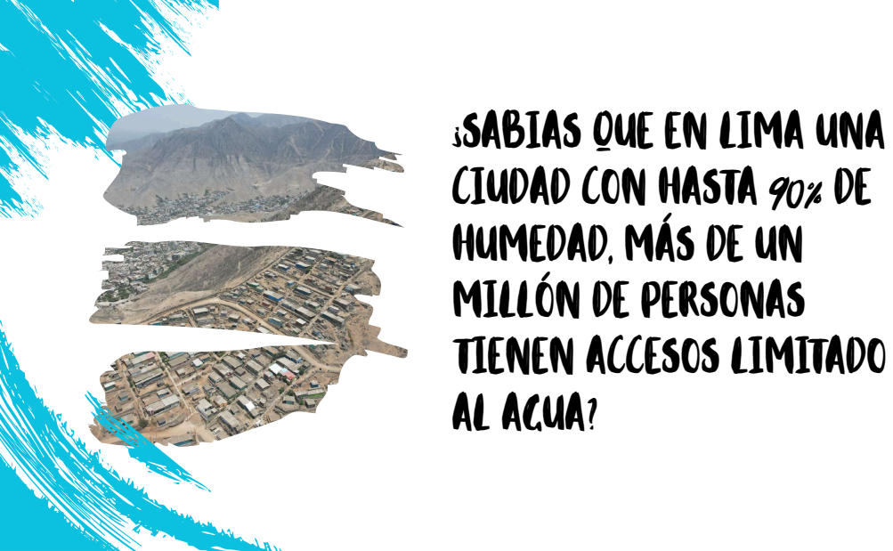
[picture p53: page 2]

ciudad con hasta 90% de
humedad, más de un
millón de personas
tienen accesos limitado
al agua?

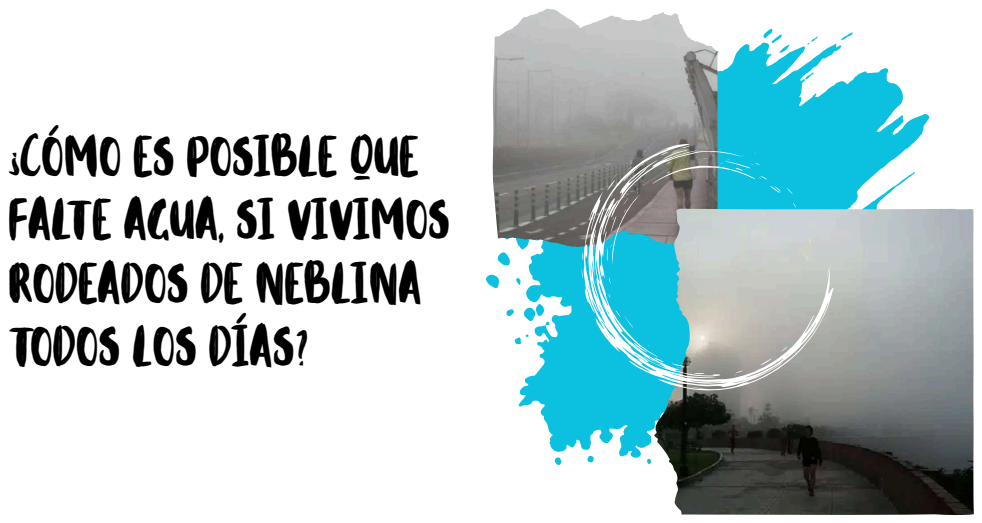
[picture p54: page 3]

¿Cómo es posible que
falte agua, si vivimos
rodeados de neblina
todos los días?

# problema

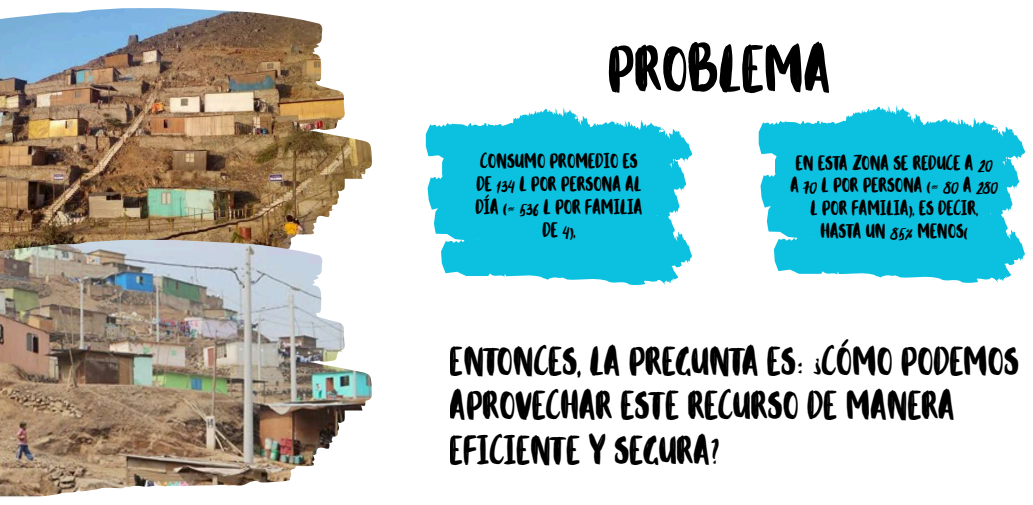
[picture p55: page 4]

consumo promedio es
de 134 L por persona al
día (≈ 536 L por familia

en esta zona se reduce a 20
a 70 L por persona (≈ 80 a 280
L por familia), es decir,
hasta un 85% menos(

Entonces, la pregunta es: ¿cómo podemos
aprovechar este recurso de manera
eficiente y segura?

# solución:

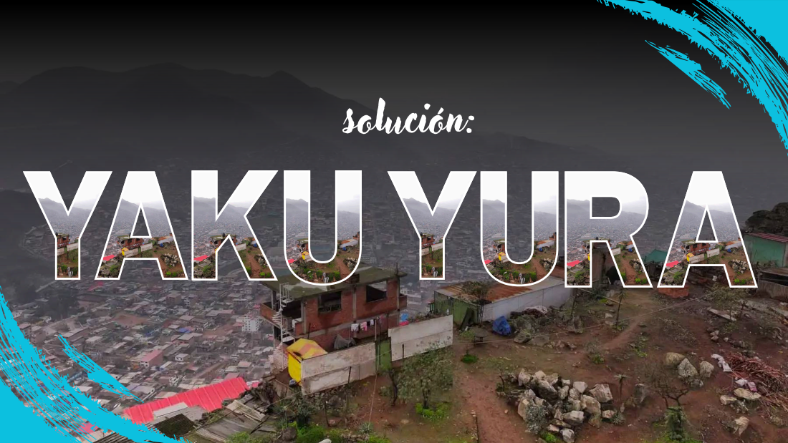
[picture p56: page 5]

# Propuesta de

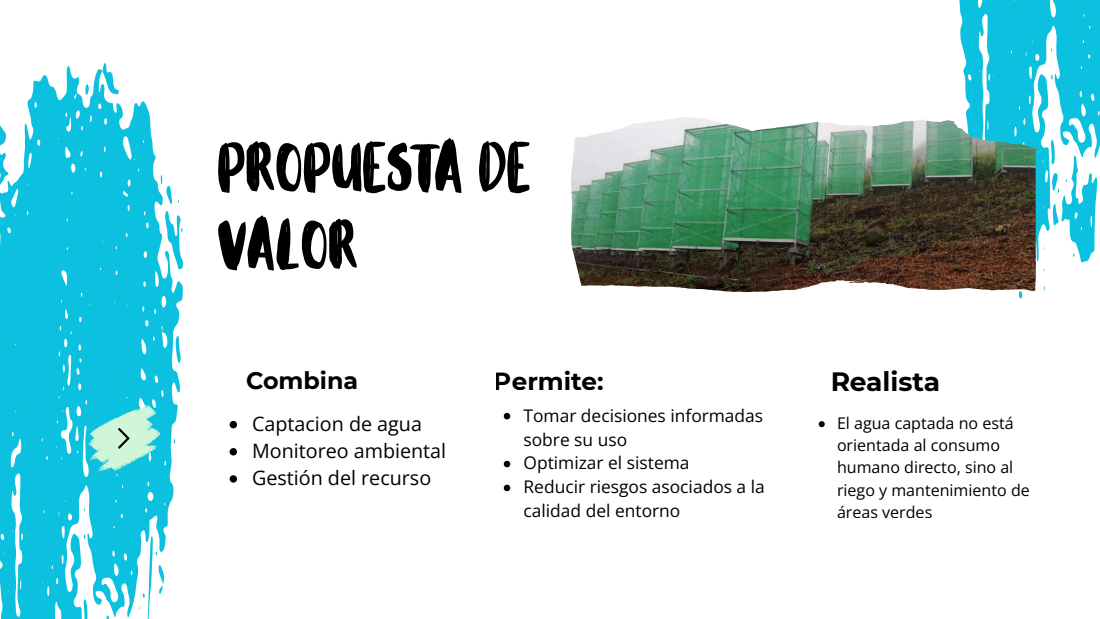
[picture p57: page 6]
valor; Realista

Combina
Captacion de agua
Monitoreo ambiental
Gestión del recurso

Permite:
Tomar decisiones informadas
sobre su uso
Optimizar el sistema
Reducir riesgos asociados a la
calidad del entorno

El agua captada no está
orientada al consumo
humano directo, sino al
riego y mantenimiento de
áreas verdes

# Modelo de negocio

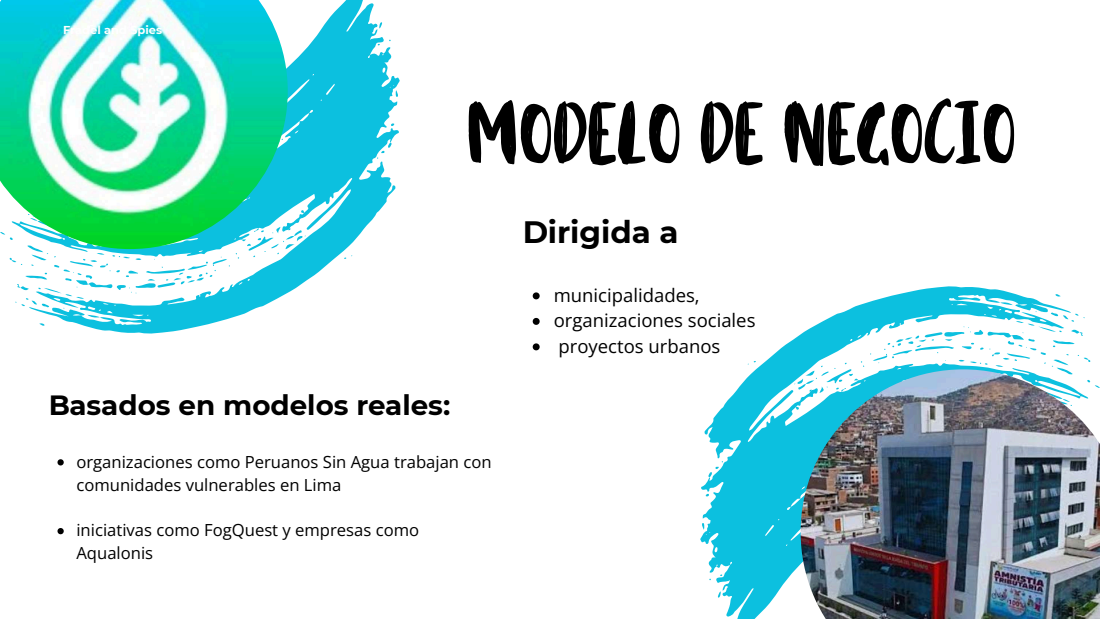
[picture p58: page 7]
municipalidades, organizaciones sociales proyectos urbanos; Dirigida a

Fradel and Spies

Basados en modelos reales:

organizaciones como Peruanos Sin Agua trabajan con
comunidades vulnerables en Lima

iniciativas como FogQuest y empresas como
Aqualonis

# ESTRATEGIA

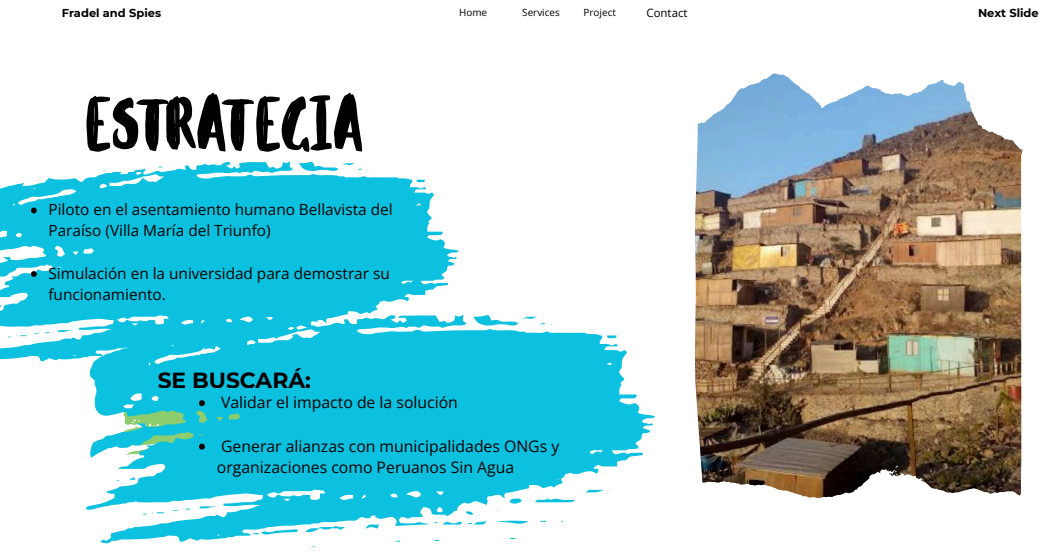
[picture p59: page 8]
Fradel and Spies; Home; Services; Project; Contact; Next Slide; SE BUSCARÁ:

Piloto en el asentamiento humano Bellavista del
Paraíso (Villa María del Triunfo)

Simulación en la universidad para demostrar su
funcionamiento.

Validar el impacto de la solución

Generar alianzas con municipalidades ONGs y
organizaciones como Peruanos Sin Agua

# TRACCIÓN

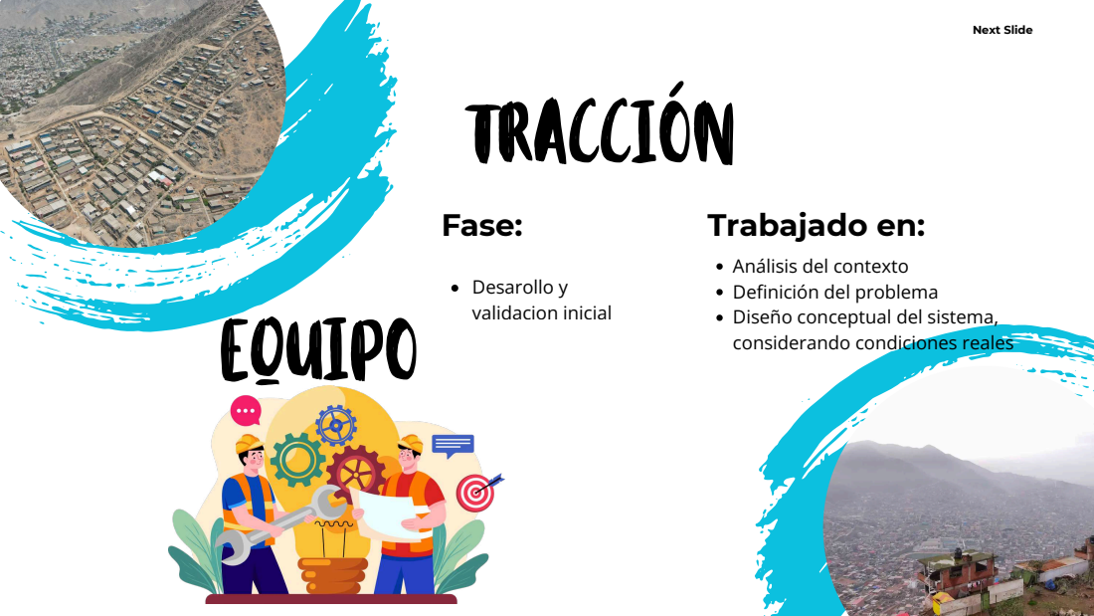
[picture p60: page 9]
Next Slide; Desarollo y validacion inicial; Fase:; Trabajado en:; EQUIPO

Análisis del contexto
Definición del problema
Diseño conceptual del sistema,
considerando condiciones reales

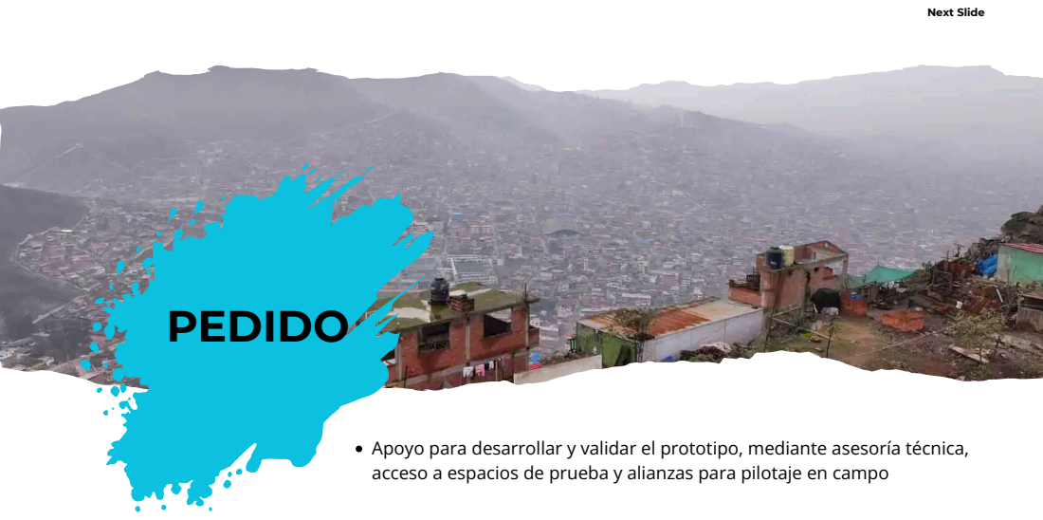
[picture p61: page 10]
Next Slide; PEDIDO

Apoyo para desarrollar y validar el prototipo, mediante asesoría técnica,
acceso a espacios de prueba y alianzas para pilotaje en campo

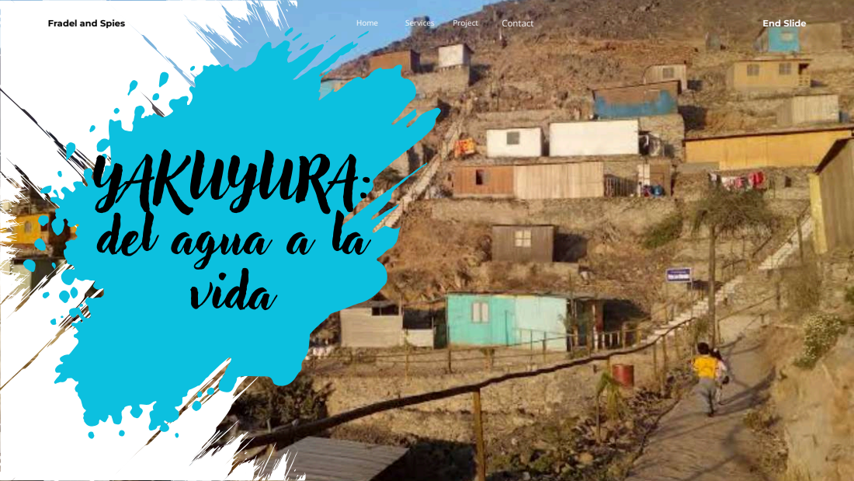
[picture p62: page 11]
Fradel and Spies; Home; Services; Project; Contact; End Slide

YAKUYURA:
del agua a la
vida

Referencias bibliográficas

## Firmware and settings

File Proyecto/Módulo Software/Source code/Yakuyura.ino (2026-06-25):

#define BLYNK_TEMPLATE_ID "TMPL2MFgtw7OB"
#define BLYNK_TEMPLATE_NAME "Yakuyura"
#define BLYNK_AUTH_TOKEN "wPPOgT2GeVWP4oJ6vy2Lx7gAwq5AeAku"

#include <WiFi.h>
#include <BlynkSimpleEsp32.h>
#include <Wire.h>
#include <Adafruit_ADS1X15.h>
#include <Adafruit_BME280.h>

// ==========================================
// Ruteo de Hardware (Arquitectura MECRO 3.3V)
// ==========================================
#define SDA_ADS 21
#define SCL_ADS 22
#define SDA_BMP 32
#define SCL_BMP 33

const char* ssid = "esp";
const char* pass = "12345678";

Adafruit_ADS1115 ads;         
Adafruit_BME280 bme;          
BlynkTimer timer;

// ==========================================
// CONSTANTES DE CALIBRACIÓN INDEPENDIENTE
// ==========================================
float offset_pH = 0.0; 

// CONFIGURACIÓN DE DIVISORES DE VOLTAJE POR CANAL
// Si el sensor tiene divisor de 5V a 3.3V, pon 1.5
// Si el sensor NO tiene divisor (va directo), pon 1.0
const float FACTOR_TURBIDEZ = 1.5; 
const float FACTOR_PH       = 1.0; // Cambiado a 1.0 asumiendo que no le pusiste divisor y por eso leía tan alto
const float FACTOR_TDS      = 1.5; 
const float FACTOR_MQ135    = 1.5; 

void procesarYEnviar() {
  // 1. ADQUISICIÓN DE VOLTAJES CRUDOS (DIRECTOS DEL ADC)
  float v_adc[4];
  for(int i = 0; i < 4; i++) {
    v_adc[i] = ads.computeVolts(ads.readADC_SingleEnded(i));
  }

  // 2. RECONSTRUCCIÓN DEL VOLTAJE REAL DEL SENSOR
  float v_turbidez = v_adc[0] * FACTOR_TURBIDEZ;
  float v_pH       = v_adc[1] * FACTOR_PH;
  float v_tds      = v_adc[2] * FACTOR_TDS;
  float v_mq135    = v_adc[3] * FACTOR_MQ135;

  // 3. PROCESAMIENTO DE SEÑALES ANALÓGICAS
  // A0: Turbidez 
  float turbidez = 0;
  if (v_turbidez < 2.5) {
    turbidez = 3000; 
  } else if (v_turbidez > 4.2) {
    turbidez = 0;    
  } else {
    turbidez = -1120.4 * v_turbidez * v_turbidez + 5742.3 * v_turbidez - 4352.9;
    if(turbidez < 0) turbidez = 0;
  }

  // A1: pH 
  float pH = 7.0 + ((2.5 - v_pH) / 0.18) + offset_pH;

  // A2: TDS 
  float tds = (133.42 * v_tds * v_tds * v_tds - 255.86 * v_tds * v_tds + 857.39 * v_tds) * 0.5;
  if(tds < 0) tds = 0;

  // 4. VARIABLES ATMOSFÉRICAS (BME280)
  float temp = bme.readTemperature();
  float presion_atm = bme.readPressure() / 101325.0F; 
  float humedad = bme.readHumidity();

  // 5. TRANSMISIÓN IOT BLYNK
  if (Blynk.connected()) {
    Blynk.virtualWrite(V0, v_mq135);     
    Blynk.virtualWrite(V1, presion_atm); 
    Blynk.virtualWrite(V2, pH);        
    Blynk.virtualWrite(V3, turbidez);  
    Blynk.virtualWrite(V4, tds);       
    Blynk.virtualWrite(V6, temp);      
    Blynk.virtualWrite(V7, humedad);   
  }
  
  // 6. TELEMETRÍA (Modo Ingeniería - Aislamiento de Fallas)
  Serial.println("==================================================================");
  Serial.printf("[ADC_PURO] A0:%.2fV | A1:%.2fV | A2:%.2fV | A3:%.2fV\n", v_adc[0], v_adc[1], v_adc[2], v_adc[3]);
  Serial.printf("[SENSOR_V] Turb:%.2fV | pH:%.2fV | TDS:%.2fV | MQ:%.2fV\n", v_turbidez, v_pH, v_tds, v_mq135);
  Serial.printf("[PROCESADO] pH:%.2f | Turb:%.1f | TDS:%.0f ppm | MQ135:%.2f V\n", pH, turbidez, tds, v_mq135);
  Serial.printf("[ATMOSFERA] Presion:%.4f atm | Temp:%.1f C | Hum:%.1f %%\n", presion_atm, temp, humedad);
}

void setup() {
  Serial.begin(115200);
  delay(100);

  Wire.begin(SDA_ADS, SCL_ADS);
  Wire1.begin(SDA_BMP, SCL_BMP);
  
  // GAIN_ONE permite leer máximo 4.096V (OJO: No superes los 3.6V físicos si el ADS está a 3.3V)
  ads.setGain(GAIN_ONE);
  
  if (!ads.begin(0x48, &Wire)) Serial.println("[CRÍTICO] Error ADC.");
  if (!bme.begin(0x76, &Wire1)) Serial.println("[CRÍTICO] Error BME280.");

  WiFi.begin(ssid, pass);
  Blynk.config(BLYNK_AUTH_TOKEN);
  
  timer.setInterval(1000L, procesarYEnviar);
}

void loop() {
  if (WiFi.status() == WL_CONNECTED) {
    if (!Blynk.connected()) Blynk.connect(5000); 
    Blynk.run();
  }
  timer.run();
}

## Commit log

2026-03-19 Primera plantilla
    [WeatherStation_v2_Base_v2.stl, WeatherStation_v2_windmill_v4.stl]
2026-03-20 cambios de vale porfi al fin
2026-03-20 Mejora en la informacion de las ODS
2026-03-20 Cambio de medidas de la foto del equipo
2026-03-25 Añadi ejemplo de proyecto
2026-03-26 Actualizacion de proyecto.md
2026-04-23 Rename Pitch Yakuyura_20260423_102529_0000.pdf to Taller_5.pdf
2026-05-21 Rename Assembly 1.stl to CAJA 1
2026-05-21 Rename CAJA 1 to CAJA 1.stl
    [CAJA 1.stl]
2026-06-24 Update and rename .gitkeep to Descripción y aporte de normas
2026-06-24 Rename Descripción y aporte de normas to Descripción y aporte de normas.md
2026-06-24 Create Descripción y aporte de normas.md
2026-06-25 Actualizacion de fotos
    [CAJA GRANDE (1).stl, CAJA_SENSO_AIRE (1).stl, ENSAMBLE GLOBAL.stl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]
2026-06-25 Rename file to Descripción y aporte de tesis.md
2026-06-25 Create Descripción y aporte de patentes.md
2026-06-25 Update and rename Descripción y aporte de tesis.md to Descripción y aporte de artículos científicos .md
2026-06-25 Update Descripción y aporte de tesis.md
2026-06-25 Rename Proyecto/Módulo Mecánico/WeatherStation_v2_Base_v2.stl to Proyecto/Módulo Mecánico/version 3.0/WeatherStation_v2_Base_v2.stl
    [WeatherStation_v2_Base_v2.stl]
2026-06-25 Rename Proyecto/Módulo Mecánico/WeatherStation_v2_windmill_v4.stl to Proyecto/Módulo Mecánico/version 3.0/WeatherStation_v2_windmill_v4.stl
    [WeatherStation_v2_windmill_v4.stl]
2026-06-25 Create Descripción y aportes para el proyecto.md
2026-06-25 Rename CAJA SENSOR DE AIRE.pdf to Caja sensor de aire VFINAL.pdf
2026-06-25 Rename Caja sensor de aire VFINAL.pdf to Plano caja sensor de aire VFINAL.pdf
2026-06-25 Rename CAJA GRANDE (2).stl to Caja grande VFINAL.stl
    [Caja grande VFINAL.stl]
2026-06-25 Rename CAJA_SENSO_AIRE (2).stl to Caja_senso_aire VFINAL.stl
    [Caja_senso_aire VFINAL.stl]
2026-06-25 Rename REJA CAJA CHICA (2).stl to Reja caja chica VFINAL.stl
    [Reja caja chica VFINAL.stl]
2026-06-25 Rename TAPA CAJA GRANDE (2).stl to Tapa caja grande VFINAL.stl
    [Tapa caja grande VFINAL.stl]
2026-06-25 Rename tapa_cajachica (1).stl to Tapa_cajachica VFINAL.stl
    [Tapa_cajachica VFINAL.stl]
